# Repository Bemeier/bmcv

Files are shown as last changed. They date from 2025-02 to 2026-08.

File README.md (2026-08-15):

# BMCV

Eight scene-crossfaded LFOs in 16HP, with a PLL that locks them to an incoming
clock. This repository is the firmware, and three other things that run the
*same* firmware: a headless simulator, a browser frontend, and a VCV Rack
module.

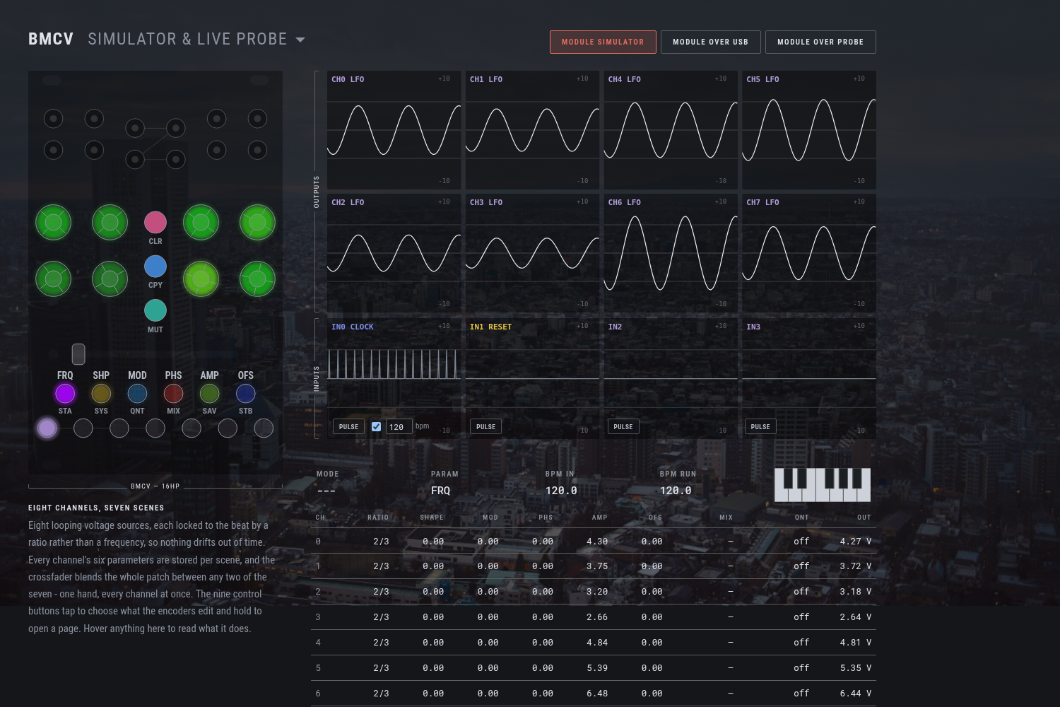
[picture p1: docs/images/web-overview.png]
The browser simulator (https://bemeier.github.io/bmcv/)


**[bemeier.github.io/bmcv](https://bemeier.github.io/bmcv/)** is that frontend,
built and deployed from `main`. It runs the module with no install, shows a
physical one over USB if you have the hardware, and carries the
[manual](https://bemeier.github.io/bmcv/manual/), a
[firmware updater](https://bemeier.github.io/bmcv/update/) and a
[diagnostics page](https://bemeier.github.io/bmcv/diagnostics/).

How to *play* the module is the manual's job, not this file's. What follows is
how the project is put together.

## One core, four hosts

Everything that behaves like a BMCV runs `Core/Src/Lib` unmodified - the same
`engine_tick`, the same UX layer, the same LED renderer. Nothing below
reimplements any of it, and none of them may: a host supplies time, input and
somewhere to put the output, and that is the whole contract.

| | what it is | lives in |
|---|---|---|
| **Firmware** | The module. STM32G474, one `bmcv_main()` off a 250µs tick. | `Core/Src/` |
| **Simulator** | The same core behind a flat C API, plus a scripting CLI for golden-file runs. | `sim/` |
| **Web frontend** | That API compiled to wasm, with an SVG panel and scopes over it. | `web/` |
| **VCV Rack** | A Rack module wrapping the same core. | `vcv/` |

The consequence worth knowing: the browser page is not a *model* of the module,
it is the module's own code with a different set of peripherals bolted on. That
is what lets the same page decode a real module's memory - see
[docs/live-module.md](docs/live-module.md) - with no parser and no second copy
of any unit conversion.

[docs/architecture.md](docs/architecture.md) is the long version.

## Repository layout

    Core/Src/Lib/     the core: engine, UX layer, LED renderer. No hardware.
    Core/Src/         the firmware's own half: ADCs, DAC, FRAM, USB, main loop.
    USB_Device/       the USB stack's app layer - descriptors, WebUSB, DFU entry.
    Middlewares/      ST's USB device library, with the MIDI class extended.

    sim/              the flat C API, its runtime shims and the scripting CLI.
    web/              the browser frontend: simulator, manual, updater, diagnostics.
    vcv/              the VCV Rack plugin.

    tests/            host-compiled tests over Core/Src/Lib and the USB descriptors.
    tools/            code generators - the panel spec, the layout asserts.
    panel/            the generated panel spec, shared by every host.
    pcb/              the KiCad project; production/ holds its fab outputs.
    docs/             architecture, the PLL, the wavetable, the live link, setup.

`Core/Src/Lib` never includes a HAL header. That is what makes the same files
compile for ARM, for the host tests, for wasm and for Rack - and it holds
because three of those four toolchains have no STM32 headers at all.

## Hardware

BMCV is a real Eurorack module - a Macro CV Controller inspired by the
[Emblematic Systems Catalyst](http://www.emblematic-systems.net/). The PCB is
made with [KiCad 8.0](https://www.kicad.org/); the project lives in
[`pcb/`](pcb/) and its fabrication outputs (BOM, gerbers, pick-and-place) in
[`production/`](production/).

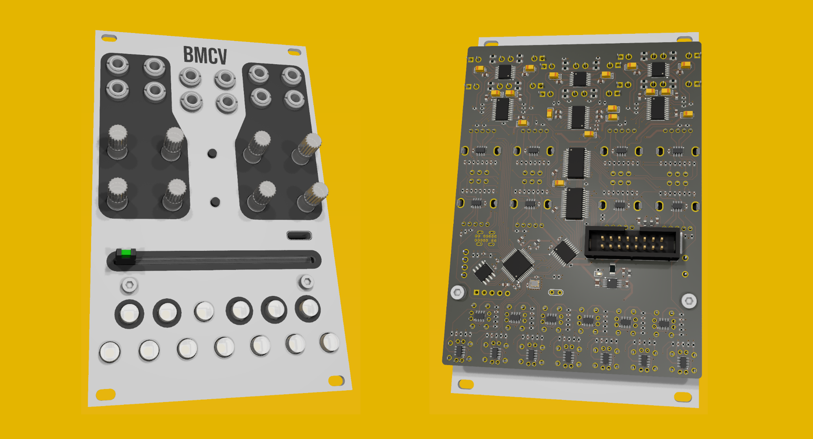
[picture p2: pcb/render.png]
Render


Eight output jacks and four input jacks, eight endless encoders that are also
buttons, nine control buttons, seven scene buttons, a crossfader, and 21
WS2812s. One USB-C port, which is a MIDI port and a vendor interface at once -
[docs/midi.md](docs/midi.md), [docs/live-module.md](docs/live-module.md).

The panel geometry is not typed in anywhere. `tools/gen_panel_spec.py` reads the
KiCad placement data and the firmware's own index tables and writes `panel/`,
which every host then draws from - so the picture on the web page cannot drift
from the board.

## The concepts the design turns on

Three, and most of the codebase follows from them.

**A channel is an oscillator locked to a ratio, not a rate.** Frequencies are
divisions of the incoming beat, so a patch stays in phase with everything around
it. That is why there is a PLL rather than a tempo readout, and why
`clock_sync.c` is the most carefully tested file here -
[docs/pll.md](docs/pll.md).

**A scene is every parameter of every channel at once, and the crossfader blends
two of them.** Forty-eight values move on one fader. That is why parameters live
in a scene-indexed array rather than on the channel, and why `EngineConfig` is
the thing that gets saved, copied and cleared.

**The whole module is one struct.** `BmcvInstance` holds the config, the signal
path, the interaction state and the input layer; the firmware keeps exactly one.
Nothing that matters lives in a file-static. That is what lets a host run
several, a test build one per case, and a debug probe or a USB link ship the
entire module to a browser as bytes.

## LED language

The colours are not decoration. One fact per LED, and the same colour for the
same idea on every page - the point being that the panel teaches itself, so the
manual never has to explain a colour.

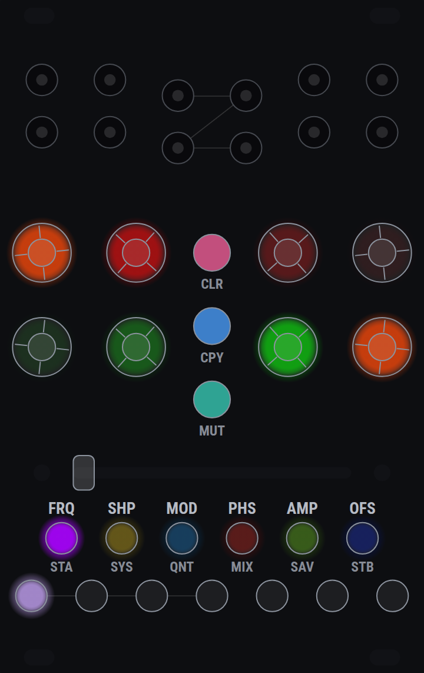
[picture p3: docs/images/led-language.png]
The panel's LEDs


- **Ctrl-page settings clamp, they do not wrap.** Each is a short list of
  unrelated states with its default at index 0, so spinning an encoder fully
  left resets it and you can do that without looking. Rolling off one end into
  the other would be the largest change on the page.
- **Setting states** are the base layer. Index 0 of every setting - disabled,
  default, neutral - is **purple**; **cyan** is continuous / level-following or
  multiplicative, **green** additive or half-way, **yellow** triggered / clocked
  / stepped, **red** reset. Destructive is **pink**, and belongs to clearing
  alone. See `HUE_STATE_*` in `color_presets.h`. The output clamp is the one
  place brightness also carries meaning, because it is two facts on one LED.
- **White is assignment, and nothing else uses it.** A short white flash every
  1.6s over an element's own colour means "you can pick this". Once something is
  held, the places it can go are steady white with a short dropout, the held
  source is steady saturated purple, and everything else goes **dark** - if it
  cannot be pressed it does not light.
- **Output level** only appears when no shift mode is active. In a shift mode
  the encoder ring shows that mode's setting, or nothing if it has none.
- **FRQ is a ratio, not a level**, so its ring codes three facts on three axes
  rather than drawing a bar. **Hue** is the kind of division: **green** straight
  (halves, quarters, octaves), **yellow** triplet, **orange** quintuplet -
  octaves are free, so 1/8 and 16 are the same green and 1/3, 3/2 and 24 are the
  same yellow. **Saturation** is how far off the grid the value sits, so a fine
  adjust washes the colour out to a pastel and a snapped ratio is pure.
  **Brightness** pulses shallowly at the channel's own output rate, which is
  what says fast from slow; anything too fast for the panel to resolve shimmers
  together at one rate instead of aliasing into a slow phantom pulse.
- **Confirmations** are a brief flash on top: purple wrote, pink cleared, cyan
  loaded. Purple is the selection colour, so a copy landing somewhere flashes
  the colour the source was held in. Red is errors only.
- **A held press dips out once as it crosses each of its thresholds** - off,
  then back on - which says "that registered" rather than pulsing away as if
  something were still in progress. At the first stage it comes back exactly as
  the page had it; where holding longer does something wider - clearing every
  scene rather than this one - it comes back brighter, in the same colour.
  Nothing commits until the release.

## Building

Prerequisites, what each fetch recipe actually gets and why, and
troubleshooting: [docs/setup.md](docs/setup.md). On a fresh checkout, the one
thing to run first is `just arm-sdk`.

    just arm-sdk          # fetch the ARM toolchain + STM32Cube HAL, once
    just build            # ARM firmware        just flash / just flash-usb
    just check            # everything host-side: format, tests, flows, wasm, web
    just check-all        # the above plus the firmware and Rack plugin builds
    just test-san         # the same tests under ASan/UBSan
    just fmt              # clang-format the hand-written C (fmt-check to verify)
    just web              # the browser frontend, at http://localhost:8000
    just docs-page        # the same pages with no wasm build, for the updater
    just vcv-install      # build the Rack plugin into ~/.local/share/Rack2
    just vcv-dist win-x64 # a distributable .vcvplugin for any platform

    # Rack running on Windows while you build in WSL. Needs the cross-compiler
    # once: sudo apt install gcc-mingw-w64-x86-64 g++-mingw-w64-x86-64
    just vcv-win-install  # cross-build plugin.dll into %LOCALAPPDATA%\Rack2

    just panel            # regenerate the panel spec from the hardware repo
    just layout-check     # regenerate the struct layout asserts from the ELF
    just docs-shots       # regenerate the screenshots in this file
    just dfu-check        # check the DfuSe client against a fake device

`just fmt` is pinned to clang-format 18, which is what CI installs; the recipe
refuses any other major, because the output moves between them.

Anything machine-specific - where your Rack SDK lives, which browser to drive -
goes in `local.just`, which is not checked in. `CMakeLists.txt` has the same
arrangement with `local.cmake`.

CI runs `just check`, the sanitizer pass and an ARM build on every push - one
job per target, in [`.github/workflows/ci.yml`](.github/workflows/ci.yml). The
firmware size is printed into the job summary rather than gated.

A push to `main` that clears every job bumps `VERSION` and `CHANGELOG.md` from
the commits since the last tag and cuts a GitHub Release - see
[Versioning](#versioning). The same push deploys `web/` to GitHub Pages.

## Flashing

Three routes, and they want different files.

**Over the programming header, from a build.** `just flash` sends
`build/BMCVFirmware.elf` over an ST-Link; `just flash-rel` does the same with
the release build. It needs the module out of the rack with a ribbon on its
debug header, and it is the only route that can also halt the core - so it is
what `just where` and any breakpoint work sit on.

**Over USB-C, from a build.** `just flash-usb` sends `build/BMCVFirmware.bin`
through the STM32's ROM DFU bootloader, with no probe and **the module still in
the rack**. That is the development loop when nothing needs stepping through:
the WebUSB link and the diagnostics page still work, so printf-level debugging
survives; halting does not. The module has to be put into update mode first -
hold **CPY** while it powers up, or press the update-mode button on the updater
page - and the recipe says which, then waits for the bootloader to appear. See
[docs/setup.md](docs/setup.md).

**Over USB-C, from the browser.**
[bemeier.github.io/bmcv/update](https://bemeier.github.io/bmcv/update/) flashes
a released version or a local `.bin`, with no build and no probe. `just
docs-page` serves the same page locally against your own build. That page
documents the rest - what to hold, what Windows needs once, what the panel does
- and this file does not repeat it.

It has to be the `.bin` there. The `.elf` beside it is what the ST-Link path
wants and is not a raw image: headers and symbols, so its first bytes are not
the vector table, and a debug build is four times the size of the flash. The
updater checks for this and refuses, naming the mistake, before erasing
anything.

Both files are on every [release](https://github.com/Bemeier/bmcv/releases). The
`.elf` is the same build with its symbols still attached, which is what a
debugger or a live variable viewer needs to attach to a module running that
release - a `.bin` carries no symbol table, so no tool can find a variable in
one. Take the `.elf` from the release the module is actually running, since
every address in it belongs to that build.

## Installing the Rack module without building it

Every [release](https://github.com/Bemeier/bmcv/releases) carries a
`BMCV-<version>-<platform>.vcvplugin` for `lin-x64`, `win-x64`, `mac-x64` and
`mac-arm64`. Drop the one for your platform into Rack's plugin folder and
restart Rack, which unpacks it on the way up. The folder ends in your
platform's name - since Rack 2.4 there is one per platform, and a plain
`plugins` directory is not read:

| | |
|---|---|
| Windows | `%LOCALAPPDATA%\Rack2\plugins-win-x64` |
| macOS (Apple silicon) | `~/Library/Application Support/Rack2/plugins-mac-arm64` |
| macOS (Intel) | `~/Library/Application Support/Rack2/plugins-mac-x64` |
| Linux | `~/.local/share/Rack2/plugins-lin-x64` |

It is not in the VCV Library, so nothing has signed it but this repository's
CI. On macOS that means Gatekeeper quarantines it on download and Rack then
refuses to load it - clear the flag on the file itself, before starting Rack:

    xattr -dr com.apple.quarantine ~/Library/Application\ Support/Rack2/plugins-mac-arm64/BMCV-*.vcvplugin

Windows may want a "more info" click past SmartScreen the first time.

## Versioning

Commit messages are [Conventional Commits](https://www.conventionalcommits.org)
- `feat: ...`, `fix: ...`, `feat!: ...` for a breaking change, and so on -
enforced on pull requests by the `commits` CI job. `VERSION` and
`CHANGELOG.md` are generated from them by [commitizen](https://commitizen-tools.github.io/commitizen/),
never edited by hand; `Core/Inc/Lib/version.h` is in turn generated from
`VERSION` at configure time, which is why it isn't checked in.

    just commit          interactive wizard for a correctly formatted message
    just bump-dry-run    preview the next version and changelog, unattended
    just bump            bump, commit and tag locally - or just push to main
                         and let the `release` CI job do it

Needs `pipx install commitizen` (or `pip install --user commitizen`) once.

The Rack plugin is the one thing that does not follow this version, because it
cannot: Rack refuses to load a plugin whose version does not begin with Rack's
own major, so driving `vcv/plugin.json` from `VERSION` would pin this project's
major to Rack's and cost the firmware its semver. It is fixed at `2.0.0` and
stays there - it means "for Rack 2", not "the second version of anything". The
firmware version travels on the released file's name instead,
`BMCV-v0.6.1-lin-x64.vcvplugin`, which is why the plugin shows as 2.0.0 in
Rack's browser however new the firmware inside it is.

## License

This work is licensed under a [Creative Commons Attribution-ShareAlike 4.0 International License][cc].

[][cc]

[cc]: https://creativecommons.org/licenses/by-sa/4.0
[shield]: https://licensebuttons.net/l/by-sa/4.0/88x31.png
[render]: https://raw.githubusercontent.com/Bemeier/bmcv/refs/heads/main/pcb/render.png

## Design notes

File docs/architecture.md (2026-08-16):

# How this repository is arranged

Four things are built from it: the firmware, a headless simulator, a browser
frontend and a VCV Rack module. All four run the same C, and the arrangement
below exists to keep that true rather than approximately true. For how to
build each - what to install and in what order - see
[setup.md](setup.md).

```
Core/Inc/Lib  Core/Src/Lib   the module. No host, no peripherals.
Core/Src/*, USB_Device/      the STM32: HAL glue, DMA, SPI, the USB stack.
sim/                         host-side glue, plus a headless CLI.
web/                         the browser frontend (wasm + plain ES modules).
vcv/                         the VCV Rack plugin.
tests/                       native unit tests for everything above.
tools/                       generators. Their output is checked in.
panel/                       generated panel geometry.
```

The HAL itself is not in the tree. `cmake/stm32cubemx/CMakeLists.txt` compiles it
out of an STM32Cube FW package located by `STM32CUBE_FW_PATH`, which is what
`toolchain.cmake` sets - written by `just arm-sdk` (see setup.md), or by hand
from `toolchain.default.cmake` if you already have STM32CubeCLT. CI fetches
the same version from ST's public mirror the same way `arm-sdk` does; the two
submodules it needs are named in `../.github/workflows/ci.yml`, at the repo
root.

## The three ideas most of this follows from

**A channel is an oscillator locked to a ratio, not a rate.** Frequencies are
divisions of the incoming beat, so a patch stays in phase with everything around
it. That is why there is a PLL rather than a tempo readout, and why
`clock_sync.c` is the most carefully tested file here - [pll.md](pll.md).

**A scene is every parameter of every channel at once, and the crossfader blends
two of them.** Forty-eight values move on one fader. That is why parameters live
in a scene-indexed array rather than on the channel, and why `EngineConfig` is
the thing that gets saved, copied and cleared. Moving a parameter onto the
channel where it looks like it belongs is the recurring wrong turn.

**The whole module is one struct.** `BmcvInstance` holds the config, the signal
path, the interaction state and the input layer; the firmware keeps exactly one.
Nothing that matters lives in a file-static. That is what lets a host run
several, a test build one per case, and a debug probe or a USB link ship the
entire module to a browser as bytes - which the next section is about.

## The seam

`Core/Src/Lib` is the module and nothing else. It has no peripheral access, no
globals, and no idea what is running it. The contract is one struct and two
calls:

```c
BmcvInstance m;                                  // instance.h
bmcv_instance_init(&m, &preset_io, now_us);
bmcv_instance_tick(&m, &input_sample, now_us);   // input_fold.h
```

A host fills an `InputSample` - button levels, encoder positions, slider, CV -
and reads `EngineState` back: `channels_gated_level[]` for its outputs,
`leds[]` for its lights. That is the whole interface. Everything a host has to
decide for itself, it decides outside this line.

Which files are in the core is not a matter of opinion:
`cmake/core_sources.cmake` lists them, and all four builds read that one list.
A source that is not on it does not compile into the firmware either.

**The rule that keeps this honest:** a behaviour that exists in a host and not
in `Core/Src/Lib` is a behaviour the hardware does not have. When a host needs
something the core does not expose, the answer is to widen the core's
interface, not to reimplement the behaviour on top of it.

## Why there is a `sim/` at all

Three hosts need the same handful of fiddly things, and each is easy to get
subtly wrong:

## What reaches the pins, and how often

The engine computes one value per channel per tick. What the DAC gets is
interpolated between the last two of those, so a step becomes a ramp rather
than an edge - `dac_write_interpolated()` in `bmcv.c`.

**The DAC has a clock of its own.** TIM6 fires every `DAC_CHUNK_US` and calls
`bmcv_dac_tick()`, which arms one transaction. Nothing in the main loop touches
it, so the output rate is a number this firmware chooses rather than a side
effect of how long the last engine tick took.

It was the latter, and it collapsed exactly when the most was being asked of it:
served from the loop, a completed transfer sat in a flag until the loop noticed,
and the loop was inside an engine tick. `dac_fps` and `engine_fps` read the same
number under load - one transaction per tick, so one frame per output every four
ticks, against a shape being computed every tick.

Two things had to be true before a fixed cadence was affordable:

1. **HAL is not on the path.** `HAL_SPI_TransmitReceive_DMA` plus
   `SPI_DMATransmitReceiveCplt` measured ~17.4us per six-byte transaction
   against **2.67us of actual wire time** - most of a transaction spent walking
   a state machine. `dac_adc.c` arms the DMA and services its completion by
   writing registers: ~9us, and four substeps went from impossible (the engine
   never ticked at all) to merely expensive.
2. **The interrupt runs at the SPI DMA completion's priority.** Equal priority
   means neither can preempt the other, so the service cannot be re-entered
   against the completion that feeds it and the two need no lock between them.

`DAC_SUBSTEPS` is how many full frames a tick is divided into - 2, so a chunk is
62.5us and every output is refreshed twice per tick. That is what the
interpolation was written for: below 1 it has nothing to interpolate between.

The measurements to reach for are `just profile`, which reads `bmcv_profile` off
a running module - `load` near 1 means the tick does not fit its period, and the
`dac` row is what one service costs - and `just dac-loopback`, which patches an
output into an input and is the only reading that tells "the bus is busy" apart
from "the outputs are moving".

- **Unit conversion.** Volts to ADC counts and DAC counts to volts, with the
  converters' real ranges and the 14-bit converter's off-by-one.
- **Tick decimation.** The engine is dt-driven and correct at any rate, but a
  host samples audio far faster than the engine needs. `SimTickDiv` accumulates
  time in Q32 microseconds so that a 44.1kHz divider of 11 does not run the
  clock 0.17% slow.
- **Gate latching.** Hardware catches edges in the ADC's DMA callback, faster
  than the engine loop. A host that samples per frame and ticks at the
  engine's rate has to latch the same way or it drops short triggers.
- **Filling an `InputSample`.** A host counts jacks the way the panel does;
  `InputSample` counts converter channels.
- **The preset slots**, which on the module are FRAM and on a host are bytes to
  put in a patch file or in browser storage.

`sim/src/sim_rt.c`, `slot_store.c` and `led_color.h` are those, in plain C with
no host's types in them, so all three hosts share one implementation and
`tests/test_sim_rt.c` and `test_slot_store.c` can exercise it with no host at
all. `sim/src/bmcv_sim.c` is a fourth host - the flat C API the wasm build and
the CLI use.

The directory is named for the simulator that came first, but its contents are
host support generally.

## The four builds

| Target | Entry point | Why it is separate |
|---|---|---|
| firmware | `CMakeLists.txt` | ARM toolchain, `cmake/gcc-arm-none-eabi.cmake` |
| tests + tools | `tests/CMakeLists.txt` | host compiler, `ctest` |
| sim + wasm | `sim/CMakeLists.txt` | same sources under `emcmake` for the web |
| Rack plugin | `vcv/Makefile` | Rack supplies `plugin.mk`; a plugin must include it |

The Rack plugin is also the only one built for more than one platform, four of
them, so which SDK and which compiler go with which is `scripts/vcv-build.sh`
rather than anything in `vcv/Makefile` - one path shared by `just vcv-dist` and
by the CI matrix in `.github/workflows/vcv.yml`, so a released `.vcvplugin` is
reproducible locally.

They are four projects rather than one because their toolchains genuinely
differ, not because the code does. Each includes `cmake/core_sources.cmake` (or
parses it, in the Rack plugin's case) so the source list cannot drift.

`just check` runs everything that needs neither hardware nor a browser: the
unit tests, the golden flows, a headless load of the wasm, and a headless
import of the whole web frontend.

## Generated, not written

Anything derived is generated and checked in, so that a reader gets it without
opening KiCad and a reviewer sees it change as a diff:

- `panel/` and `web/panel.json` and `vcv/res/` come from `tools/gen_panel_spec.py`,
  which merges the PCB project's KiCad output (`pcb/`, `production/`) with the
  firmware's own `HwSetup` tables. Positions, LED assignments and button roles are
  therefore derived from the board and the firmware together, and
  `tests/test_panel_spec.c` asserts the two agree. `just panel`.
- `Core/Inc/Lib/stepped_table.h` comes from `tools/gen_stepped_table.c`.
  `just stepped-table`.
- `Core/Inc/Lib/wavetables.h`, `Core/Src/Lib/wavetables.c` and the plots in
  `docs/images/wavetable-*.svg` all come from one run of
  `tools/gen_wavetable.py`, so the documentation cannot show a shape the
  firmware does not have. `just wavetable`, and `just wavetable --report` for
  the axis as sparklines. Generated rather than drawn because the properties
  that matter - full swing and no DC at *every* setting, the canonical shapes
  exact, the axis closing on itself - are true of the whole family by
  construction and were not true of a table edited slice by slice.
  `docs/wavetable.md` is the long version.
- `docs/images/` comes from `tools/`-driven screenshots of the real frontend.
  `just docs-shots`.

What genuinely cannot be derived lives in `panel/overrides.json` and is listed
under `assumptions` in the generated spec, so an assumption cannot hide.

## Testing

Conventions for writing one are in [`tests/CLAUDE.md`](../tests/CLAUDE.md);
this is what exists and why. `tests/` holds ordinary unit tests plus three
things worth naming:

- **`tests/fixtures/fixture.c`** drives a whole `BmcvInstance` from button and
  encoder events, so a test can express a gesture ("hold STA, tap scene 3")
  rather than a state.
- **`sim/flows/`** are scripted input timelines replayed through the CLI and
  diffed against committed CSV output. They cover interactions across time that
  a unit test cannot state - a clock locking, a mute ramping, a mode latching.
  Review the diff, then `just flows-bless`.
- **`tests/pll_metrics.{c,h}`** turns a run of the sync loop into numbers -
  settling, ringing, frequency pull, phase continuity, long-run alignment - so
  that a change to it reads as a trade rather than as a feeling.
  `tests/test_pll.c` prints the table; `docs/pll.md` keeps the baseline.

Several tests exist purely to stop the four builds drifting apart, and are
load-bearing rather than incidental: `test_panel_spec.c` (the generated
geometry against `hw_setup.c`), `test_sim_import.c` (a snapshot round-trips
through the wasm decoder), `test_config_migrate.c` (every old FRAM record still
loads), the LED curve check in `web/smoke.mjs` (the C header against the JS
constants), and `sim/include/layout_target.h`, which is not a test at all but a
wall of static assertions the wasm build compiles.

`tools/stepped_explore/` is the fourth kind: an offline measurement harness rather
than a check. It is what a change to `stepped_shape()` has to be judged with,
because the obvious identity metrics say the old sweep contained 400 distinct
patterns and are no help at all. See [`tools/CLAUDE.md`](../tools/CLAUDE.md).

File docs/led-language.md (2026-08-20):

# LED language

The colours are not decoration. One fact per LED, and the same colour for the
same idea on every page - the point being that the panel teaches itself, so the
manual never has to explain a colour.

The panel's LEDs

- **Red and green are a voltage, and nothing else on an encoder is.** The ring
  showing a level, the AMP and OFS parameters, and the live CV on an input jack
  wear the ramp in `led_set_bipolar` — red negative, green positive, warming at
  the extremes. That ramp never lights the blue die, and every other colour on
  the panel does, which is what keeps a setting from reading as a level. The
  error blink borrows red and blanks the panel to say so; the six lit caps keep
  their own colours, because a cap is a label and never shows a value.
- **Ctrl-page settings clamp, they do not wrap.** Each is a short list of
  unrelated states with its default at index 0, so spinning an encoder fully
  left resets it and you can do that without looking. Rolling off one end into
  the other would be the largest change on the page.
- **Setting states** are the base layer, and they live on the cool half of the
  wheel, 30 apart. Index 0 of every setting - disabled, default, neutral - is
  **purple**; **cyan** is continuous / level-following or multiplicative,
  **teal** additive or half-way, **blue** triggered / clocked / stepped.
  Destructive is **pink**, and belongs to clearing alone. **Yellow** is reset,
  and is the one state that keeps a warm hue: it appears only on the SYS scene
  row, which is the one page with no voltage on it anywhere. See `HUE_STATE_*`
  in `color_presets.h`. The output clamp is the one place brightness also
  carries meaning, because it is two facts on one LED.
- **White is assignment, and nothing else uses it.** A short white flash every
  1.6s over an element's own colour means "you can pick this". Once something is
  held, the places it can go are steady white with a short dropout, the held
  source is steady saturated purple, and everything else goes **dark** - if it
  cannot be pressed it does not light.
- **Output level** only appears when no shift mode is active. In a shift mode
  the encoder ring shows that mode's setting, or nothing if it has none.
- **A parameter is drawn as what it is.** With no page open, touching an encoder
  reveals the selected parameter across all eight rings for two seconds. **AMP**
  and **OFS** are volts, so they wear the voltage ramp on the DAC's own scale.
  **SHP**, **MOD** and **PHS** are numbers: the same ramp - dark at zero,
  brightening toward either end - in **teal** positive and **pink** negative,
  where saturation is the third fact and says whether the value is on something
  with a name. Pure on a named shape or on a half or whole turn of phase,
  washing to a pastel between two of them. Which shapes have names depends on
  the shape mode, so PWM's width and the stepped morph have none.
- **FRQ is a ratio, not a level**, so its ring codes three facts on three axes
  rather than drawing a bar. **Hue** is the kind of division: **teal** straight
  (halves, quarters, octaves), **blue** triplet, **pink** quintuplet - octaves
  are free, so 1/8 and 16 are the same teal and 1/3, 3/2 and 24 are the same
  blue. The scale used to be green to orange, which is the voltage ramp end to
  end; it walks the cool half now, so a ratio cannot be read as a level.
  **Saturation** is how far off the grid the value sits, so a fine adjust washes
  the colour out to a pastel and a snapped ratio is pure.
  **Brightness** pulses shallowly at the channel's own output rate, which is
  what says fast from slow, shifting the hue slightly *inward* toward the middle
  of the scale at the peak so a pulse can never brighten a class toward the
  voltage arc; anything too fast for the panel to resolve shimmers
  together at one rate instead of aliasing into a slow phantom pulse.
- **Confirmations** are a brief flash on top: purple wrote, pink cleared, cyan
  loaded. Purple is the selection colour, so a copy landing somewhere flashes
  the colour the source was held in.
- **A held press dips out once as it crosses each of its thresholds** - off,
  then back on - which says "that registered" rather than pulsing away as if
  something were still in progress. At the first stage it comes back exactly as
  the page had it; where holding longer does something wider - clearing every
  scene rather than this one - it comes back brighter, in the same colour.
  Nothing commits until the release.

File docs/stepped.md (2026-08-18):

# The stepped shape

A pattern of values, one per step of the cycle, eased between and locked to the
beat. `Core/Src/Lib/stepped.c` is the runtime; `stepped_pattern.h` is what each
step shows, shared with the table generator; `stepped_norm.h` is the correction
that holds the level steady.

**It is not random.** Every value is a deterministic function of the two knobs,
the pattern length and the phase - the caller re-derives phase from the PLL on
every tick and gets the same value back, which is what lets scenes crossfade
without the pattern drifting. What the knobs move through is a space of
patterns. That is also the constraint that shapes everything below: a phase-
driven module cannot draw fresh numbers, so what it has instead of stochastic
draws is the rule that **neighbouring knob positions stay related**.

For what the knobs do musically, see [shapes.md](shapes.md).

## How a value is built

1. **Slots.** Each step has a slot, and each slot rides its own slow orbit at
   its own whole-numbered rate. SHP advances all of them at once, which is why
   the knob wraps.
2. **Character levers**, all functions of the orbit: how the values are spread
   (`ST_BEND`), how melodic the contour is (`ST_CONTOUR`), whether the cycle
   repeats a quarter-length phrase (`ST_MOTIF`), which steps tie (`ST_SPIN`),
   where the beat sits (`ST_SWING`). Each has a depth and a *rate* - how many
   excursions it makes across its knob - so a given contour depth comes back
   paired with a different shaper each time.
3. **Ties.** A step either takes its own value or crossfades toward the previous
   one. MOD moves the density and rotates which steps tie, so the tied set keeps
   re-arranging instead of only growing.
4. **The correction**, `out = value * gain + offset`, which holds the level
   steady. See below.
5. **Two reshapings** of the finished value, both driven by SHP: the bias, which
   leans the distribution, and the terracing, which gathers values onto a few
   levels. Both monotone.

## The correction, and where it lives

Short patterns collapse. With a handful of steps the orbits can all cross at
once and the pattern flattens for a stretch of the knob - measured at length 2,
18% of the sweep, in runs 15% wide. The correction is an affine per setting that
lifts those without flattening the natural variation elsewhere.

It has two halves, and they have opposite shapes, which is what decides where
each one lives:

| | shape | so it is |
|---|---|---|
| the centring constant | length-*in*dependent, expensive: an average across every pattern length of what would centre each | baked, 8 KB, `st_centre_table` |
| the gain | length-dependent, cheap: one pattern's own extremes | measured at runtime |

A channel knows only its own length, so it cannot work the constant out; it
scans its own pattern for the gain, one slot per engine tick. That split is what
replaced a 180 KB table of gains and offsets - and it made two things exact that
the table could only approximate:

- **The cycle boundary.** Every length lands on the shared constant at phase 0,
  so pattern length can be switched on the wrap without a step in the signal.
  Interpolating a table put 0.044 of a jump there; computing the anchor at the
  real point puts none.
- **The floor.** `ST_NORM_FLOOR` is now applied at the point being played rather
  than arriving through a neighbourhood rule written for interpolation. Worst
  span anywhere went 0.584 to 0.900 of the 2.0 range.

### What a step costs, and why it is paid once

What a step shows, and what the next one shows, depend on which step the
playhead is in and **not on where inside it** - only the ease between them
varies within a step. The shape is sampled far faster than the steps move: at
0.5 Hz over 64 steps, tens of consecutive ticks were computing the same two
numbers from scratch.

So a channel keeps an `StStepCache` and pays per *step* rather than per tick.
Two things fall out of it:

- **Within a step there is nothing to compute but the ease.**
- **Crossing into the next step costs one slot evaluation, not a walk.**
  `st_step_next()` returns exactly `st_step_value(next)`, so what the last step
  eased *toward* is by definition what this one eases *from* - the pair advances
  by computing only its new far end. That is the part that helps a fast LFO,
  where the cache itself never hits.

Only a jump pays the full route: a phase correction, a knob turn, or a rate high
enough to skip a step outright. **The skipping case is not improved at all**, and
was already bounded - `st_step_value()` is O(`ST_JUMP_GRID`) regardless of
pattern length.

### And the slots underneath it

The step cache removed everything *above* the slot evaluations, which left those
as the whole cost - and they are memoisable for the same reason: what a slot
offers depends on the slot and the morph, and the morph on nothing but the two
knobs and the length. `StSlotMemo` remembers `st_slot_offer()` per slot while
the knobs are still.

It is threaded as a parameter, and `NULL` means "compute it". That is what keeps
it a memo rather than a second implementation: one value path, and a caller that
supplies no memo takes the identical route through it. The scan shares the
channel's memo, since it walks the same slots of the same pattern.

### What the two are worth

Measured on the module, seven stepped channels at MOD full (densest ties, motif
fold active), over 64 steps. `engine` avg, and `load` against the 250 µs period -
**taken while the tick was still 250 µs**, so the loads are not today's. The
engine cost per tick is what is being compared and that does not move with the
period; see `hw_setup.h` for what the tick is now and why.

| rate | steps/tick | neither | step cache | + slot memo |
|---|---|---|---|---|
| 0.5 Hz | 1/91 | 296.5 µs (1.30) | 197.3 µs (0.90) | **184.2 µs (0.84)** |
| 62.5 Hz | ~1 | 282.8 µs (1.27) | 227.5 µs (1.02) | **192.0 µs (0.88)** |
| 129.5 Hz | ~2, skipping | 277.9 µs (1.24) | 275.4 µs (1.23) | **209.0 µs (0.95)** |

**Every column of the last row is the point.** The step cache does nothing for a
playhead that skips - the carry never applies and the cache never hits, so it
was flat at 275 µs - while the slot memo takes 24% off it, because a skipping
playhead still asks for slots it asked for a few ticks ago. Together they held
`engine_fps` at its nominal 4000 under every condition above, with overruns at
3% and resyncs in single figures. Before them the same patch ran at 2915 with
every tick overrunning.

Backing out the ~135 µs the engine costs before any stepped channel exists, the
per-channel stepped cost at the skipping rate goes 20.0 → 20.0 → **10.5 µs**.

The cache changes when the work happens, never what comes out.
`tests/test_stepped_cache.c` asserts the cached and uncached routes are
bit-identical, and that is not decoration: the cache key has to name every input
`st_morph()` and `st_step_pair()` read, and a lever added to `StMorph` driven by
something outside the key would leave a channel drawing its old pattern - no
crash, no drift in level, just the wrong shape, sounding plausible.

Writing that test found a real one. `st_tie_run()` *breaks* when a tie weight
reaches 1, so `st_step_value()` returns the slot's offer outright - while
`st_step_next()` computed `lerp(from, offer, 1.0f)`, and `from + (offer - from)`
is not `offer` in floating point. At length 3, where `st_tie_fade` lets a weight
reach exactly 1, the two disagreed in the sixth digit. The discrepancy predates
the cache; nothing had ever compared the two routes.

### The scan

`st_norm_scan()` measures one slot per tick and slews the result into place over
20 ms. Three things about it are load-bearing:

- **The engine hands out one measurement per tick**, in turn, across all
  channels. A slot evaluation is nearly as expensive as the shape itself - a
  step value walks a run of ties, each slot a four-tap contour and a motif fold.
  Eight channels each measuring every tick cost 88 µs of a 310 µs tick, and the
  engine answered by dropping every third one. **Measured on the `-O0` debug
  build** (`just flash-usb` flashes that one; `just flash-usb-rel` is the
  optimised firmware), so the absolute figures are 5x pessimistic - the host
  gap between -O0 and -O2 for this shape is 437 ns against 83. The rota bounds
  the cost either way and costs a standing channel nothing, but whether it is
  *needed* at -O2 has not been measured.
- **A standing channel stops measuring.** Re-measuring an unchanged pattern can
  only give the answer it already has, so what the scan costs is a knob moving.
- **A length change restarts the pass** rather than paying for a full
  measurement in one tick, which would be three ticks' worth of budget and
  happens once per encoder detent.

The slew, not a latch to the cycle wrap: a slow LFO would otherwise play a whole
cycle uncorrected after a knob move, and the table it replaced never waited for
a wrap either.

## What a small turn may do

The rule is that a small turn **deforms** the pattern rather than replacing it.
That is measured as **Spearman's rank correlation** between the patterns at *x*
and *x* + 1% of travel: the steps keep their order.

The measure matters as much as the bound. It used to be "no sample moves more
than 0.35", which is the same thing while character comes from redrawing the
pattern - and a different thing for a monotone reshaping, which cannot move a
step out of order however far it moves the values. That is true by construction,
so the old rule was charging full price for the one mechanism that is musically
free, and it was the ceiling on how much a detent could do.

| steps | worst rho, SHP | worst rho, MOD |
|---|---|---|
| 3-5 | -0.50 .. 0.70 | -0.50 .. 0.60 |
| 8-16 | 0.71 .. 0.84 | 0.79 .. 0.90 |
| 24-64 | 0.93 .. 0.96 | 0.94 .. 0.98 |

Held at 0.55 from eight steps up. Short patterns are exempt: three values cannot
change gently, and at three steps one swap inverts the order outright.

A second, looser bound stays on how far a sample may move (0.60), because
keeping the order is not sufficient on its own - a reshaping steep enough to
throw a step across the range would pass the rank test and still be heard as a
jump.

## Things that were tried and are not here

Written down because each cost a day and the numbers looked good on the way in.

- **A smooth wander** (`drift`, octaves of a smoothed triangle in the phase
  domain). Measured beautifully - DC exactly zero, no correction needed, 20 ns a
  call - and sounded like a sine with harmonics, because that is what it is. A
  waveform that closes on itself over one cycle *is* a Fourier series; smooth
  means few harmonics; octave rates are harmonics 1, 2, 4 and 8. Inside one
  phase-locked cycle the only routes to something that reads as random are
  discontinuity or high harmonic order.
- **A separate melodic mode.** Two routings of the same engine, one for notes
  and one for modulation. The notes one was where this arrived from rather than
  a second thing worth keeping - MOD left is gently eased and SHP centre is an
  even distribution, which is where it lived.
- **`ST_SPAN`**, a lever that ducked the peak-to-peak across SHP. Being a pure
  gain it moved no character measurement at all; it only made the shape flatten
  as the knob turned.
- **Cutting `ST_MAX_ORBIT_RATE` to buy small-turn budget.** The worst turn goes
  0.44 at rate 4, 0.51 at 3, 0.39 at 2, 0.37 at 1 - non-monotone, and barely
  moving even where the slot values are nearly frozen. The worst case is not the
  orbit.
- **Snapping values to levels.** A staircase applied to a moving value is a
  discontinuity - 0.23 of a jump at every crossing. The terracing compresses
  each cell toward its centre instead.
- **Caching orbit values across a run.** Slower: the compare and branch to read
  the cache cost more than the triangle they save.

## Measuring a change

`tools/stepped_explore/` is the only thing that can judge one, because the
obvious metrics mislead: the original sweep contained 400 distinct patterns at
32 steps and still read as nothing happening. `from_c.py` reads the shipping C
through `dump_pattern.c` and splits character into **steer** (what the knob
commands) and **jitter** (what merely fluctuates), alongside the level figures.

Read `char-st` rather than `steer` when only the correction changed: three of
its features are level, and flattening those on purpose lowers `steer` while
moving no character. Two features - `skew` and `clump` - exist because the rest
are ordering-based and were blind to the reshapings entirely.

## Known, and open

- **Terracing moved the level, and the correction now spans it.** It shrinks a
  pattern's peak-to-peak by an amount depending on where its extremes fall
  against the cell boundaries - variance rather than bias, so the mean span
  moves only 4% and no global compensation reaches it. `st_bias_map` driven
  positive does the opposite and *widens* a span.

  So the correction is two affines with the reshapings between them. The
  pre-stage centres the pattern and scales it toward `ST_NORM_TARGET`, as it
  always did. The post-stage - `st_norm_levelled()` - measures what the
  reshapings actually left and scales it back to what the pre-stage asked for.
  Measured across the whole (SHP, MOD, length) grid, on the path a channel
  actually plays:

  | | min span | max span | ratio |
  |---|---|---|---|
  | before | 0.5640 | 1.8750 | 3.325 |
  | after | 0.5640 | **1.6217** | **2.876** |

  **Only the loud end moves, and that is the rails.** Where `st_gain_toward`'s
  clamp is already what sets the gain - the pattern is as wide as +/-1 allows -
  there is no room to lift the quiet settings, so the minimum does not budge.
  What the post-stage reaches is the settings that were coming out *too wide*.

  Two things it must not disturb, and does not. It is anchored at the reshaped
  value at phase 0, which every length shares because the centring constant is
  length-independent - so the loop still closes and pattern length still
  switches seamlessly on the wrap. And being applied *after* the maps, it scales
  the finished waveform uniformly: the plateaus stay plateaus.

  **Applying it before the maps instead does not work, and was measured.** A
  gain change ahead of the terracing moves values against its cell boundaries,
  so it changes which plateau each one lands on - the character, not the level.
  The first attempt did that, iterating on the pre-stage gain, and it also broke
  `ST_NORM_FLOOR` at two settings by removing a widening the floor had been
  carrying by luck.

  A caution for anyone measuring this: `cycle_level()` in the test suite
  evaluates through a *bare* drive - bias 0, terrace 0 - so the reshapings are
  the identity there and it cannot see any of this. An early comparison using it
  produced a confident and completely wrong conclusion. Measure through
  `st_drive(shape, mod)`, which is what a channel plays.

  It costs 3.6% of the engine at the worst case measured on the module - three
  map evaluations and a divide per completed scan pass, and one multiply-add per
  sample - taking `load` from 0.44 to 0.45.

- **Peak-to-peak normalisation flattened crest factor, and `ST_NORM_ROBUST`
  is what stopped it.** The correction measured the span from the single
  highest and single lowest slot. A pattern that sits low with one tall spike
  has the same peak-to-peak as one spread evenly across the range, so it earned
  the same gain - its spike came out no higher than the other's ordinary
  maximum and its bulk far below. A taller spike read as a wider span and
  therefore earned a *smaller* gain. Crest factor is the one thing peak-to-peak
  normalisation cannot let through.

  Reported from the module first, and it was audible before it was measured:
  at negative SHP there were few high values, and the ones there were did not
  peak enough - "now it's just largely quiet".

  The span is now measured between the *second* highest and second lowest,
  blended with the true extremes by `ST_NORM_ROBUST` (0.5). **The rail limit
  still comes from the true extremes**, which is what makes it safe: raising
  the gain lifts a spike toward +/-1 and stops it exactly there rather than
  clipping it.

  Measured across the (SHP, MOD, length) grid, through the drive a channel
  actually plays:

  | | before | after |
  |---|---|---|
  | median peak, SHP < -0.3 | +0.467 | **+0.555** |
  | settings with no peak at all (<0.40) | 36.3% | **25.1%** |
  | RMS ratio, loudest to quietest | 5.249 | **4.067** |
  | crest factor, mean | 1.331 | **1.383** |
  | neighbour rho, mean | 0.9877 | **0.9877** |
  | worst sample move, 1% turn | 0.502 | 0.515 (bound 0.60) |

  **Peak-to-peak spread goes up while RMS spread goes down.** The ear hears
  RMS, so perceived loudness got *more* consistent - the extra span is peaks
  poking out of it, which is the point. The metric that looks worse is the one
  that cannot tell a spike from a loud patch.

  **The character is untouched, and that was the thing to protect.** Spearman
  rho between a setting and the one 1% of travel away is identical to four
  decimal places, so neighbouring knob positions are exactly as related as they
  were; the worst single-sample move across that turn is slightly *larger*, not
  smaller, so there is no loss of variety between neighbours either.

  **It fades in with length**, via `st_dof_fade` - the same fade the contour
  blend uses and for the same reason. At three steps `hi2` and `lo2` are both
  the middle value, the robust span is zero, the gain runs to the rail, and a
  1% turn of SHP moved the output 1.66 of a 2.0 range against a 1.10 limit.
  With the fade it is 0.90.

  One trap worth recording: the rolling scan must seed its order statistics
  *empty* and push slot 0 like any other, exactly as `st_extent_of` does.
  Seeding them from slot 0 looks equivalent and is not - `lo2` starts equal to
  `lo` and can never be improved upward - and the rolling measurement then
  disagreed with the full one in the fourth decimal.

- **Swing on odd lengths** makes step 0 and step L-1 both wide at lengths 3 and
  5 - a lopsided shuffle.
- **Every hardware measurement here was taken on the `-O0` debug build**, which
  is what `just flash-usb` flashes. That is where "the module ticks at 3.3 kHz
  rather than the nominal 4" came from, and it is a property of that build
  rather than of the module. Re-measure with `just flash-usb-rel` before
  treating any of these numbers as the module's own.

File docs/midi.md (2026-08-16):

# MIDI

The module enumerates as a USB MIDI device and talks in both directions. This
is what it says and what it listens for.

## What it sends

Everything on **MIDI channel 1**, in one contiguous block of control changes.

| CC | Source |
|---|---|
| 16–23 | channel outputs 1–8 |
| 24–27 | CV inputs 1–4 |

The value is the signal at the jack, with the converter's full ±10V range
scaled onto 0..127 — so **0V is 64**, a full negative swing is 0 and a full
positive swing is 127.

That mapping is deliberately about the jack rather than about the patch: a
channel clamped to 0..5V uses a quarter of the CC range, because that is the
quarter of the module's output range it actually occupies. Nothing rescales
underneath you when you change the clamp — which also means that **if it is
clipped on the module it is clipped on MIDI**. The clamp is applied in the
output stage before any of this (`channel.c`, `clamp_output`), so a value
sitting at 0 or 127 is the same clipping the jack is doing, and using the clamp
as a shaping tool works the same way in both places.

The channel outputs are read *after* the mute gain, so a muted channel reads as
silent here for the same reason its jack does.

### Rate

Control changes are reconsidered 500 times a second and sent only when the
7-bit value has moved. An idle patch therefore sends nothing at all, and the
worst case is 12 messages per slot.

The rate limit is not a nicety. The engine runs at 2kHz, and a full-scale sine
at 5Hz crosses 128 quantization levels about 256 times a cycle — around 1280
CC/s on one channel and 10k/s across eight, which fits through the endpoint with
no margin and is more than a DAW wants to think about.

7 bits is visibly stepped on a slow ramp into something like a filter cutoff.
That is the cost of a mapping every DAW can learn without configuration; CC
MSB/LSB pairs would fix it at double the traffic and with patchy support.

### Clock

The module sends MIDI Clock at the standard 24 PPQN, plus Start when its clock
resets and Stop when the beat is lost.

**Only when an input jack is the clock source.** That is the same rule the
input direction uses: a patched cable wins, and MIDI is the fallback. So the
module forwards a rack clock out to a DAW, and stays quiet when the DAW is
already the master — regenerating a host's own clock back at it is redundant at
best.

## What it listens for

- **MIDI Clock (0xF8)** and **Start (0xFA)**, used as the clock and reset when
  no input jack is configured for the job. Continue (0xFB) deliberately does not
  read as Start: it resumes rather than restarts, and treating it as a reset
  would drop every oscillator's phase on a DAW punch-in.
And nothing else. Control traffic — the firmware updater's reboot-into-DFU, the
version string it shows beside the image it is about to write, snapshots and the
remote panel — used to come through here as SysEx and now goes over the module's
vendor interface. See [live-module.md](live-module.md) and
`Core/Inc/Lib/usblink.h`. What is left on this endpoint is what MIDI is for.

## Where this lives

`Core/Src/Lib/midi_out.c` decides what to send and holds it in a queue. It is
core code: no USB, no host types, and `tests/test_midi_out.c` drives it with
hand-built engine states. Each host only carries the bytes —
`Core/Src/Lib/midi.c` wraps them as USB-MIDI event packets for the endpoint,
and `web/midi.js` hands them to a Web MIDI port.

The mapping is therefore in exactly one place, and the simulator cannot drift
from the hardware.

## Using the simulator's MIDI out

The **MIDI out** box shows the twelve CCs as they are sent, with a bar per
value: what the far end is receiving, at the 7-bit resolution it receives it,
rather than a re-derivation from the engine. A bar pinned to either end is
marked, so clipping against a channel's clamp is visible as clipping.

That readout is fed by draining the module's queue, which happens whether or
not a port is selected — so it works with no MIDI port on the machine at all,
which is the common case and the quickest way to see what the mapping does.

Two things are worth knowing before it can actually send:

- **Web MIDI is Chromium and Firefox.** Safari does not ship it. The page says
  so rather than failing quietly.
- **A browser can only send to a port that already exists**, and no operating
  system provides one by default. macOS has the IAC driver (Audio MIDI Setup →
  Window → MIDI Studio), Windows needs loopMIDI or similar, Linux has ALSA's
  virmidi. Without one the port list is empty.

## Not implemented

- The VCV Rack module does not send MIDI. Patch its outputs into Rack's own
  CV-MIDI module, which does the same job natively.
- The dialled parameters (FRQ/SHP/MOD/PHS/AMP/OFS) are not published — only the
  values the channels produce. The module is a modulation source here, not a
  control surface.

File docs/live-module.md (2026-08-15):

# Watching and driving a module from the browser

The simulator page can show a physical module instead of the simulation, and
send input back to it. Two transports do the same job by different means:

| | over USB | over a debug probe |
|---|---|---|
| what it needs | the module's own USB cable | an ST-Link on the programming header |
| snapshots/s, measured | **364** | ~70 |
| firmware cost | ~80 lines, 2.4 KB RAM | **none** |
| survives a power cycle | **yes** | yes |
| works on a module that has stopped answering | no | **yes** |

**USB is the default.** It is five times faster, needs no hardware beyond the
cable already in the module, and works on one already plugged into a DAW.

**The probe is kept for one reason.** Streaming runs from the module's main
loop, which is the thing you would be debugging if the engine hung. If the core
faults or stalls, the snapshots stop and so does everything else the module
says. An ST-Link keeps reading RAM regardless, because a Cortex-M's debug unit
reaches memory over the AHB-AP without the core's cooperation. It has already
earned that place once, proving a module was healthy while its USB had gone
quiet.

## The trick, which is the same for both

**The whole module is one struct.** `BmcvInstance` holds the config, the signal
path, the interaction state and the input layer; the firmware keeps exactly one.
Everything the page draws is inside it.

**The wasm decodes it.** `bmcv_sim_import()` takes those bytes, re-points the
pointers inside them at itself, and republishes every reading. So the wasm
module - the same firmware code, compiled for the browser - is not a simulation
of the module here, it is *the decoder for a real one*. There is no struct
parser in JavaScript, no duplicated unit conversion, no second copy of the LED
curve, and there cannot be one, because nothing on the page ever looks inside
the blob.

That property is what every other decision here protects, and it is why three
transports have now been swapped underneath it without any of them touching it.

**The layouts are held equal by construction.** `sim/include/layout_target.h` is
generated from the firmware ELF's debug info and asserts the offset and size of
every leaf field of `BmcvInstance`. It is compiled into the wasm, so `just
check` fails if the two builds ever disagree. Getting there needed one fix:
`arm-none-eabi-gcc` defaults to `-fshort-enums` and clang does not, so three
enum fields are `int8_t` with the enum named in a comment.

Run `just layout-check` after `just build-rel` and review the diff.

## Over USB

The module is a composite device: MIDI on interface 0, exactly as it always was,
and a vendor-specific interface on 1 with its own pair of bulk endpoints.

**Nothing installs a driver.** `USB_Device/App/usbd_webusb.c` carries a BOS
descriptor with a WebUSB platform capability and a Microsoft OS 2.0 one; the
descriptor set behind the second names WinUSB as the driver for interface 1 and
registers a device interface GUID. Windows binds it automatically. Chrome then
claims the interface through `navigator.usb`.

Nothing on the wire is encoded or framed. A bulk transfer keeps its boundaries,
so one transfer is one message, and a snapshot is simply the instance's bytes -
the browser assembles the packets and hands over the whole thing, so neither
side reassembles anything.

- `USBLINK_OP_SNAPSHOT_REQ` asks; the module answers with the instance.
- **One request buys one snapshot.** The page asks again only once it has
  decoded and adopted the last, so the module cannot outrun what the page can
  draw. Two requests stay outstanding so the endpoint does not idle for a round
  trip; credit beyond that is dropped rather than banked, so what goes out is
  the module as it is now and not a queue of stale frames.
- Credit is also the heartbeat. A page that goes away stops asking, credit runs
  out, and the module falls silent on its own.
- The snapshot is copied between engine ticks, so it is internally consistent -
  which a probe read is not.
- Snapshots have their own endpoint, so the engine's MIDI output competes with
  nothing.

`BMCV_REQ_VERSION` is a vendor *control* request answered with the firmware
version. A question about the device rather than part of the stream, and a short
reply sharing an endpoint with 2384-byte snapshots would have to be told apart
from one by length - which is the framing this transport exists to avoid.

**Every call to the device is bounded.** WebUSB transfers have no timeout of
their own: a read for data that never comes simply never settles, with no error
and nothing to retry. During a connect that is an attempt which cannot fail, so
the retries never run and the switch that started it never finishes - which
locks every button on the page, since a switch already running refuses to start
another. `web/frontend-check.mjs` holds this, because it is a property that is
easy to lose one call at a time.

## Over a debug probe

`web/probe/stlink.js` speaks enough of the ST-Link protocol over WebUSB to
identify the probe, enter SWD mode, and read and write memory. A Cortex-M's
memory is readable without halting the core, so the module keeps playing while
it is watched.

Finding the instance is the one thing WebUSB cannot do for itself: `bmcv` moves
whenever anything before it in `.bss` changes size, and a browser has no ELF and
no `nm`. So the firmware says where it is, at an address that does not move -
`Core/Inc/Lib/bmcv_probe.h` declares a 28-byte `const` and the linker pins it to
`0x08000200`, just past the vector table. Two linker `ASSERT`s hold the address
and the size to what the header declares.

## The write direction

Both transports carry the same two mailboxes, and the module cannot tell which
one a byte arrived over.

**`RemoteInput`** is a second panel, wherever it is: button levels to OR in,
free-running encoder positions to sum, an optional crossfader override.
`input_fold` merges it, so the module answers it exactly as it answers a finger
- UX feedback, LED response, autosave, all of it.

Every field is a *level* or a *free-running position*, never a delta waiting to
be consumed. That is what makes it safe to write over a wire with no handshake:
a torn write costs one tick of a wrong value, nothing accumulates so nothing can
be applied twice or lost, and the two sides never have to agree a baseline. The
writer picks its own encoder origin and never learns the module's.

The crossfader is the only control where the two panels can genuinely disagree,
being an absolute position. Last mover wins: a new value in the mailbox takes
the fader and remembers where the physical one was sitting, and the physical one
takes it back by moving `REMOTE_SLIDER_RELEASE_RAW` away from there. The
threshold is what stops ADC noise reading as a hand on the fader.

`RemoteInput.seq` is a heartbeat as well as an update. A writer that stops -
a page refreshed with a button held - would otherwise leave its levels standing,
and a module stuck holding SHIFT has no way back but a power cycle.

**`RemoteCommand`** is the two things a panel cannot say: start again, and forget
what was saved. Destructive, and neither is a level, so it is an edge - acted on
once per change of its sequence number, however often it is rewritten. That is
what "Reset module" and "Clear FRAM" send when a module is connected.

One thing the write direction exposed, older than any of this: a rebuilt
instance zeroes the frame encoder positions are compared against, while the
physical counters keep theirs. The difference is not a turn, but the first fold
read it as one and applied it to whichever parameter was selected - which after
a reset is deliberately OFS. `InputFrames.baseline` is why the first fold after
an instance is built reports a position rather than a movement.

## The update page

`web/update/` flashes over DFU, and now reboots the module into DFU over the
same vendor interface. That matters more there than anywhere: the thing that
page does most is make the module leave the USB bus, and it used to ask over the
transport least able to survive that.

## Diagnosing it

`web/diagnostics/` has two instruments, and they earned their place. Every fault
on these links that was reasoned about was diagnosed wrongly; every one these
were pointed at gave the answer in a single run.

- **Inspect the device** reports what the browser can see: interfaces,
  endpoints, whether the vendor interface can be claimed - which is what says
  the driver bound - and what firmware is running. It separates a driver that
  did not bind from a module that is not answering.
- **Measure the snapshot rate** asks for snapshots exactly as the simulator page
  does but decodes nothing and draws nothing. Fast here and slow there means the
  cost is in decoding and drawing; slow here too means the transport or the
  firmware. It reports the spread as well as the average, because a steady
  stream and a bursty one average the same and look nothing alike.

## What the MIDI transport taught, before it was deleted

Snapshots were carried over MIDI SysEx for a while. It worked - 90 a second,
measured - and was removed anyway, because a browser enumerates MIDI *once*: a
module that left the bus, which a power cycle or a reflash does, could not be
reached again until the browser was restarted. No page can reach past that.

Two things from it are worth keeping in mind, because they are properties of
MIDI rather than of that implementation:

- **Only System Real-Time may interleave a SysEx.** Sharing an endpoint with the
  engine's control changes meant every snapshot held it for eleven milliseconds
  while musical output waited - and a control change landing inside a snapshot
  made the host abandon it, which presented as a stream that stopped for no
  visible reason.
- **A host packs what it has into a transfer.** A parser that reported only the
  first message in one silently dropped the second, which is how the module came
  to be starved of the requests it was waiting for.

The module still speaks MIDI, for what MIDI is for: control changes out, a clock
in.

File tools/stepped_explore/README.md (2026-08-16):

# Stepped: measuring what SHP and MOD actually do

An offline harness for judging changes to `stepped_shape()` before writing any
C. `stmodel.py` is a replica of the shipping algorithm, verified against it to
1.8e-6 (float32 rounding) - regenerate the reference with `dump_c.c`:

    cc -O2 -I Core/Inc/Lib -o /tmp/dump_c tools/stepped_explore/dump_c.c \
        Core/Src/Lib/stepped.c -lm && /tmp/dump_c > /tmp/c_ref.txt

## What it measures

- `metrics.py` - RMS distance between rendered cycles. "How different is this
  signal."
- `musical.py` - patterns quantised to note-sized levels, compared by Hamming
  distance. "How many different note sequences, and how many notes change per
  1% of knob travel."
- `character.py` - eleven features per pattern (span, roughness, turns,
  edginess, tie fraction, longest run, motif repetition, centroid, low-frequency
  energy, spread, swing), then the trajectory along the knob split into
  **steer** (its low-passed component: character the knob commands) and
  **jitter** (the residual: character that merely fluctuates because each
  position is a fresh random draw).
- `invariants.py` - the properties a variant may not break, mirroring
  `tests/test_stepped.c` plus the two the shipping algorithm cannot
  violate (parameter cyclicity, slot 0 length-independence).
- `dump_pattern.c` + `from_c.py` - the same character numbers plus **level**
  (how far the pattern's centre and its peak-to-peak move along a knob),
  computed on the C's own output rather than on the replica. Use these for any
  change to the *correction*: it lives in the generated table, which the replica
  does not carry.

The identity metrics come first historically and are the ones that mislead: the
shipping sweep contains 400 distinct sequences at 32 steps and still feels like
it does nothing. `steer` is what separates a knob that goes somewhere from one
that reshuffles.

`layered.py` is the round-two engine: every lever a (rate, depth) pair, on
whichever knob drives it. `final.py` is the spec the shipping C was written
from, and `verify_c.py` checks the two agree - the normalisation comes from the
generated header, so what it really tests is the value path.

## Use

    cd tools/stepped_explore
    python3 -c "import stmodel as M, character as C, variants as V; \
                C.scale(); C.report(M.Engine()); C.report(V.C5())"
    python3 -c "import invariants as I, variants as V; I.check(V.C5())"

`C.scale()` must be called before the first variant so every run is standardised
against the same baseline sigma.

For a change to the normalisation table, dump the C before and after instead -
the first file given sets the scale, so the columns are comparable:

    cc -O2 -I Core/Inc/Lib -o /tmp/dump_pat tools/stepped_explore/dump_pattern.c -lm
    /tmp/dump_pat > /tmp/after.txt      # `just stepped-table` in between
    python3 tools/stepped_explore/from_c.py /tmp/before.txt /tmp/after.txt

Read `char-st` there, not `steer`: three of the eleven features are level, so a
change that deliberately flattens level lowers `steer` while moving no
character at all.

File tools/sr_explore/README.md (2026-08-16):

# Stepped random: measuring what SHP and MOD actually do

An offline harness for judging changes to `stepped_random()` before writing any
C. `srmodel.py` is a replica of the shipping algorithm, verified against it to
1.8e-6 (float32 rounding) - regenerate the reference with `dump_c.c`:

    cc -O2 -I Core/Inc/Lib -o /tmp/dump_c tools/sr_explore/dump_c.c \
        Core/Src/Lib/stepped_random.c -lm && /tmp/dump_c > /tmp/c_ref.txt

## What it measures

- `metrics.py` - RMS distance between rendered cycles. "How different is this
  signal."
- `musical.py` - patterns quantised to note-sized levels, compared by Hamming
  distance. "How many different note sequences, and how many notes change per
  1% of knob travel."
- `character.py` - eleven features per pattern (span, roughness, turns,
  edginess, tie fraction, longest run, motif repetition, centroid, low-frequency
  energy, spread, swing), then the trajectory along the knob split into
  **steer** (its low-passed component: character the knob commands) and
  **jitter** (the residual: character that merely fluctuates because each
  position is a fresh random draw).
- `invariants.py` - the properties a variant may not break, mirroring
  `tests/test_stepped_random.c` plus the two the shipping algorithm cannot
  violate (parameter cyclicity, slot 0 length-independence).
- `dump_pattern.c` + `from_c.py` - the same character numbers plus **level**
  (how far the pattern's centre and its peak-to-peak move along a knob),
  computed on the C's own output rather than on the replica. Use these for any
  change to the *correction*: it lives in the generated table, which the replica
  does not carry.

The identity metrics come first historically and are the ones that mislead: the
shipping sweep contains 400 distinct sequences at 32 steps and still feels like
it does nothing. `steer` is what separates a knob that goes somewhere from one
that reshuffles.

`layered.py` is the round-two engine: every lever a (rate, depth) pair, on
whichever knob drives it. `final.py` is the spec the shipping C was written
from, and `verify_c.py` checks the two agree - the normalisation comes from the
generated header, so what it really tests is the value path.

## Use

    cd tools/sr_explore
    python3 -c "import srmodel as M, character as C, variants as V; \
                C.scale(); C.report(M.Engine()); C.report(V.C5())"
    python3 -c "import invariants as I, variants as V; I.check(V.C5())"

`C.scale()` must be called before the first variant so every run is standardised
against the same baseline sigma.

For a change to the normalisation table, dump the C before and after instead -
the first file given sets the scale, so the columns are comparable:

    cc -O2 -I Core/Inc/Lib -o /tmp/dump_pat tools/sr_explore/dump_pattern.c -lm
    /tmp/dump_pat > /tmp/after.txt      # `just sr-table` in between
    python3 tools/sr_explore/from_c.py /tmp/before.txt /tmp/after.txt

Read `char-st` there, not `steer`: three of the eleven features are level, so a
change that deliberately flattens level lowers `steer` while moving no
character at all.

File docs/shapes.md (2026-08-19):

# The three shapes, and what SHP and MOD do in each

Every channel is an oscillator locked to the beat by the PLL. What it draws
between one cycle and the next is its **shape mode**, and each mode gives the
same two knobs a different job. The figures are generated from the module's own
shape functions by `just shape-figures` - a picture here cannot show a shape the
firmware does not have.

Read them as a grid: **SHP down the rows, MOD across the columns.**

## Wavetable

wavetable

The classic shapes and everything between them. **SHP** slices a 64-frame table
that runs square - sine - triangle - pointy and back to square, so the knob
wraps. **MOD** leans where the cycle spends its time: negative pulls the
waveform early, positive pushes it late, and the ends of the knob stop short of
where the warp would collapse.

Every setting reaches full swing with no DC offset - between slices as well as
on them, which is a guarantee the table is generated to hold rather than
something it happens to do. See [wavetable.md](wavetable.md).

## Stepped

stepped

A pattern of values, one per step, locked to the beat and eased between. Not
random: every value is a deterministic function of the two knobs, the pattern
length and the phase, re-derived from the PLL on every tick. What the knobs move
you through is a *space of patterns*, which is why neighbouring settings sound
related rather than being fresh draws.

**SHP** is the distribution the values are drawn into, and which pattern they
come from:

| | |
|---|---|
| hard left | mostly low, with the peaks still reaching - modulation that sits down and occasionally spikes |
| centre | even |
| hard right | bunched against both rails - gate-like, mostly high or mostly low |

Underneath that the pattern itself advances, so the knob reaches different
patterns as well as different distributions. It is periodic: past the end is
where it started.

**MOD** is motion. At one end every step takes a new value and the curve is
fully slewed between them; at the other most steps tie to the one before and the
curve sits still on each. Density, which steps tie, how far the beat swings,
whether the cycle repeats a quarter-length phrase, and the ease all move
together along it. Unlike SHP it does not wrap - its ends are opposite ends.

**Pattern length** is a per-channel setting rather than a scene parameter,
because there is nothing between 8 steps and 12 for a crossfade to land on. See
[stepped.md](stepped.md) for how the shape is built and what holds it together.

## PWM

PWM

A gate with an envelope on it. **SHP** is the pulse width, off both end stops so
the pulse never disappears entirely. **MOD** is how much of that pulse is ramp
rather than plateau, and its sign is how the ramp is split between the two ends:

| | |
|---|---|
| 0 | a hard gate, so a PWM channel is still a clock divider |
| part way | attack, plateau, decay - an AD envelope, biased by the sign |
| hard left | one decay filling the pulse: percussive, instant attack |
| hard right | one attack filling the pulse: a ramp up, then a hard drop |

Both ramps live inside the pulse, so **SHP is the envelope's length** as much as
the gate's width, and nothing bleeds past it. A short trigger with a long tail
is a wide SHP at MOD hard left rather than a narrow one.

MOD used to give each edge its own segment - the rise inside the on-time, the
fall inside the off-time. That kept the width honest, but it put the two ramps on
opposite sides of the pulse edge so they could never coexist, and no setting on
the knob was an AD envelope. It also ran the decay's length *inverse* to the
width, because what it had to spend was the off-time: a wide pulse had nowhere
to decay into.

The ramps are curved rather than linear, which is what makes them read as an
envelope rather than as a triangle: the attack is concave and the decay convex.

## What the modes share

- **Phase 0 is the rising edge** in every shape: it is where PWM opens its gate
  and where the stepped mode starts step 0. A square channel at a whole division
  is therefore a clock divider whose gate opens on the beat.
- **The knobs do not change the level.** Each shape either reaches full swing by
  construction (wavetable, PWM) or is corrected to a steady one (stepped), so a
  turn changes what the shape does rather than how much of it there is. How loud
  is AMP's business, and where it sits is OFS's.
- **AMP, OFS, FRQ and PHS mean the same thing everywhere**, which is what makes
  the mode a property of the channel rather than a different instrument.

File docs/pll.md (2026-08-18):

# The sync loop

How a channel's phase is locked to the incoming clock, what it measures, and
the record of the rework that got it here. `tests/test_pll.c` prints the table
below on every run; re-run it after touching the loop and diff.

The work this describes is done. It is kept because the numbers are the only
way to tell whether a future change to the loop is an improvement, and because
two of the three defects found were things the code looked correct about.

## What the loop is, as built

`channel_compute` runs a proportional controller per channel. **As it stands
today**, after the four steps below:

```
q, p     = the latched rational: q beats hold p cycles      // see Step 4
target   = frac(((beat_counter % q) + beat_phase) * p / q)  // the clock's grid
diff     = phase_error(target, shared_phase, 1.0)           // cycles
pull     = clamp(diff / PLL_TAU_S, +/- PLL_MAX_PULL * freq)
correction += (pull - correction) * (dt / PLL_SMOOTH_S)
phase   += dt * (freq + correction)                         // wraps at one cycle
```

The rest of this section describes it **as it was first measured**, which is
where the record starts:

```
target  = ((beat_counter % gcd) + beat_phase) * freq_multiplier
diff    = phase_error(target, shared_phase, phase_length)     // wrapped, cycles
correction += (diff - correction) * k_sync                    // k_sync = 0.075/tick
phase  += dt * (freq + correction)
```

`gcd = find_denominator(freq_multiplier, 8, 0.025)` is the alignment period in
beats — the number of beats after which the channel returns to the same phase.
`phase_length = gcd * freq_multiplier` cycles is the super-period the error
wraps in.

Two things the measurements settled that were not obvious from reading it:

- **`k_sync` is not the loop's time constant.** It is an EMA coefficient per
  tick, so at 250us its time constant is ~3.3ms — three hundred times faster
  than the loop itself. `correction` therefore tracks `diff` essentially
  instantly, and the loop reduces to `d(phase)/dt = freq + 1.0 * error`: a pure
  P controller with an implicit gain of 1/second.
- **So the response is first-order with tau = 1s**, and is nearly independent of
  the control rate. Measured: a half-cycle phase step settles to 1% of a beat in
  3.90s at a 250us tick and 3.87s at 1000us. `ln(0.5/0.01) = 3.9`, which is the
  whole story.

## Step 1: the harness

- `tests/pll_metrics.{c,h}` — a clock generator that drives the fixture at a
  tempo (with optional deterministic jitter), a trace, and the metrics:
  settling time, peak error, ringing (sign changes past a deadband), peak
  frequency pull, frequency slew, steady-state RMS, and alignment-period flips.
  Errors are in **beats**, so they compare across ratios.
- `tests/test_pll.c` — twelve scenarios. Bounds are deliberately loose: the
  point is the printed table, which is the before-picture to diff against.
- `ChannelEffective.phase_error` publishes what the loop is minimising, so the
  tests measure the loop's own quantity rather than a re-derivation that could
  drift from it.

### Baseline (2026-08-04, k_sync 0.075, tau ~1s)

```
scenario                             settle     peak  cross     fdev     fslew  rms_tail   gcd
                                          s    beats      n   x rate  x rate/s     beats flips
lock, x1 @ 120bpm                     0.000   0.0027      0    0.001       0.0   0.00002     0
scene A->B, x1 -> x2 (snap)           3.212   0.2500      0    0.123      34.7   0.00002     0
scene sweep, during the 1s move       never   3.0789     12    1.398     461.9   1.46698    44
scene sweep, settling after           3.164   0.2391      0    0.120       0.1   0.00002     0
ratio sweep x1 -> x4 over 3s          never   3.5626     20    1.721     543.1   1.21583   108
phase step, half a cycle              3.902   0.5000      0    0.246      69.4   0.00002     0
tempo step, 120 -> 140bpm             3.016   0.0728      0    0.032       5.1   0.00031     0
x0.75, 240s alignment                 0.000   0.0003      0    0.000       0.0   0.00019     0
x1, 5% clock jitter                  29.988   0.0272     38    0.014       3.2   0.01048     0
clock lost 6s, then back              0.000   0.0007      0    0.000       0.1   0.00002     0
phase step @ 250us tick               3.901   0.4999      0    0.246      48.9   0.00002     0
phase step @ 1000us tick              3.868   0.4998      0    0.239      12.2   0.00000     0
```

### What it says

**The steady state is excellent.** Long-run alignment at x0.75 (gcd 4, so the
channel only meets the beat every fourth one) holds 0.0002 beats RMS over four
minutes with zero drift. Clock loss and return, tempo steps and jitter are all
absorbed cleanly. Nothing rings: every case is 0 or 1 significant crossings.
The extrapolation-to-beat-multiple approach works — this is the part to keep.

**It is slow, and deliberately over-damped.** ~3.9s to close a half-cycle
error. That is a defensible choice for a module where a lurching LFO is worse
than a late one, and it is why nothing overshoots.

**The one real defect is a moving ratio.** During a crossfade between scenes at
different rates, `find_denominator` changes its answer **44 times in a one-second
fader move** (108 times over three seconds for x1 -> x4). Every change alters
`beat_counter % gcd` by an arbitrary number of beats, so the *target teleports*
and the loop chases a step it did nothing to cause. Consequences, all measured:

- phase error excursions of **3.1 beats** where the fader move itself justifies
  a fraction of one;
- the correction pulling the oscillator to **1.4x its nominal rate** (1.7x for
  the wider sweep) — an audible speed lurch, which is exactly the artifact the
  loop is otherwise tuned to avoid;
- frequency slew of ~460 x rate/s.

Also: a large `gcd` admits a large error, because the error wraps at half the
super-period. At gcd 7 the loop can believe it is 3.5 beats out and correct at
full gain. The excursions above are that mechanism, triggered by the flipping.

## Step 2: done (1-4)

1. **The alignment period is latched.** `EngineState.channels_gcd[]`, taken once
   and re-taken only when the super-period wraps — the "do not change the grid
   under the playhead" rule `st_length_idx` already follows.
2. **The origin is latched with it** (`channels_beat_origin[]`), and the target
   is measured from it: `((beat_counter - origin) % gcd + beat_phase) * ratio`.
   This is what makes a change of period seamless. At the wrap the channel is at
   phase 0 of the period it is leaving, and taking the origin there defines the
   new period to start in the same place — so the target does not move at all.
   Re-basing anywhere else could not work: the origins differ by a whole number
   of *beats*, which is not a whole number of *cycles*, so it would step the
   output waveform.
3. **The correction is clamped** to `PLL_MAX_PULL` (0.15) of the channel's
   nominal rate. Past that the error closes at a constant rate instead of an
   exponential one — slower for a large error, and inaudible.
4. **`PLL_TAU_S`, `PLL_MAX_PULL`, `PLL_SMOOTH_S`** in `channel.h`, all in
   seconds or in fractions of the rate. The smoothing coefficient is now
   `dt / PLL_SMOOTH_S` rather than a per-tick constant.
5. **Not done, and argued against.** An integral term buys nothing measurable
   here: the steady-state residual under a tempo error is 0.0003 beats, and a
   second pole is the thing that would introduce the overshoot this loop is
   valued for not having.

### After (2026-08-04, PLL_TAU_S 1.0, PLL_MAX_PULL 0.15)

```
scenario                             settle     peak  cross     fdev     fslew  rms_tail   gcd
                                          s    beats      n   x rate  x rate/s     beats flips
lock, x1 @ 120bpm                     0.000   0.0027      0    0.001       0.0   0.00002     0
scene A->B, x1 -> x2 (snap)           3.212   0.2500      0    0.123      38.2   0.00002     0
scene sweep, during the 1s move       never   0.2858      0    0.142       0.7   0.23821     1
scene sweep, settling after           3.341   0.2852      0    0.142       0.2   0.00002     1
ratio sweep x1 -> x4 over 3s          never   0.9004      0    0.150       1.7   0.84237     2
phase step, half a cycle              4.060   0.5000      0    0.150      45.9   0.00002     0
tempo step, 120 -> 140bpm             3.017   0.0728      0    0.032       5.6   0.00031     0
x0.75, 240s alignment                 0.000   0.0003      0    0.000       0.0   0.00019     0
x1, 5% clock jitter                  29.988   0.0272     38    0.014       3.5   0.01048     0
clock lost 6s, then back              0.000   0.0007      0    0.000       0.1   0.00002     0
phase step @ 250us tick               4.059   0.4999      0    0.150      31.1   0.00002     0
phase step @ 1000us tick              4.056   0.4995      0    0.150       5.9   0.00000     0
```

| | before | after |
|---|---|---|
| crossfade, frequency pull | 1.398x | **0.142x** |
| crossfade, frequency slew | 461.9 | **0.7** |
| crossfade, peak phase error | 3.08 beats | **0.29 beats** |
| gcd flips, 1s crossfade | 44 | **1** |
| gcd flips, 3s x1→x4 sweep | 108 | **2** |
| phase step, settling | 3.90s | 4.06s |
| long-run alignment, jitter, tempo step, clock loss | — | unchanged |

The crossfade artifact is gone: what was a 1.4x speed lurch is now a bounded
0.14x lean, and the frequency slew during a fader move drops by a factor of 660.
The cost is 4% on settling time, from the clamp, exactly as predicted.
Everything that was already good is untouched, to the digit.

## Step 3: two regressions the hardware found

The first pass at (1) latched `gcd` but left the accumulator wrapping at the
super-period. Caught on hardware as an audible click through a slider move, and
then reproduced in the harness as a new metric, `jump` — the step in output
phase that the oscillator's own rate does not account for.

**The accumulator may only ever wrap at one cycle.** The waveform is a function
of phase modulo one, so that wrap is invisible; the sample either side of it is
the same sample. It used to wrap at `gcd * ratio` cycles, which is only a whole
number of cycles when the ratio really is the rational multiple
`find_denominator` claims. That held while gcd was recomputed every tick — to
within its 0.025 tolerance, so the step existed but was under 2.5% of a cycle.
Latching gcd while the ratio kept moving removed the guarantee entirely:
measured at **0.34 of a cycle** through a one-second crossfade.

The alignment period belongs in the error term, not in the accumulator. So:

- `channels_shared_phase[]` is the phase within one cycle, wrapping at one.
- `channels_cycle[]` counts which cycle of the super-period it is on, and
  `channels_period_cycles[]` how many cycles that period holds. The loop's
  error is computed against `cycle + phase` over the whole super-period.

The second regression came out of fixing the first. Reducing the error to a
single cycle is appealing — it bounds the error at half a cycle and the waveform
repeats, so whole cycles of difference are inaudible in the steady state. It is
wrong: the loop then locks to whichever of the `period_cycles` equivalent phases
is nearest, so a x2/3 channel still repeats every three beats but can sit a
third of a cycle off the bar. **Which cycle of the pattern lands on the downbeat
is the entire point of aligning to a beat multiple.** Nothing asserted it;
`the_pattern_lands_on_the_same_beat_every_time` does now.

A third change fell out of the same investigation: a new alignment period is
only taken once the ratio has held still for `PLL_RATIO_STABLE_US`. A ratio
crossing a crossfade is a rational multiple every few ticks and irrational
between them, so acquiring on the instant meant taking and discarding eleven
periods in a second, with the correction switching on and off along with them.

### Final (2026-08-04)

```
scenario                             settle     peak  cross     fdev     fslew  rms_tail      jump
                                          s    beats      n   x rate  x rate/s     beats    cycles
lock, x1 @ 120bpm                     0.000   0.0027      0    0.001       0.0   0.00002   0.00000
scene A->B, x1 -> x2 (snap)           3.212   0.2500      0    0.123      38.2   0.00002   0.00001
scene sweep, during the 1s move       never   0.2367      2    0.116      32.9   0.18348   0.00001
scene sweep, settling after           2.937   0.1902      0    0.095       0.1   0.00002   0.00001
ratio sweep x1 -> x4 over 3s          never   0.2361      4    0.116      45.4   0.05841   0.00002
fader worked back and forth           never   1.7751     12    0.154     100.4   0.37568   0.00003
phase step, half a cycle              4.060   0.5000      0    0.150      45.9   0.00002   0.00001
tempo step, 120 -> 140bpm             3.017   0.0728      0    0.032       5.6   0.00031   0.00001
x0.75, 240s alignment                 0.000   0.0000      0    0.000       0.0   0.00001   0.00000
x1, 5% clock jitter                  29.988   0.0272     38    0.014       3.5   0.01048   0.00000
clock lost 6s, then back              0.000   0.0007      0    0.000       0.1   0.00002   0.00000
phase step @ 250us tick               4.059   0.4999      0    0.150      31.1   0.00002   0.00000
phase step @ 1000us tick              4.056   0.4995      0    0.150       5.9   0.00000   0.00000
```

| | original | final |
|---|---|---|
| crossfade, frequency pull | 1.398x | **0.116x** |
| crossfade, frequency slew | 461.9 | **32.9** |
| crossfade, peak phase error | 3.08 beats | **0.24 beats** |
| crossfade, output phase step | 0.025 cycles (by luck) | **0.00001** (by construction) |
| crossfade, settling after | 3.16s | 2.94s |
| x0.75 long-run alignment, RMS | 0.00019 beats | **0.00001 beats** |
| phase step, settling | 3.90s | 4.06s |

### Re-taken at a 2kHz tick (2026-08-16)

`ENGINE_TICK_US` went 250 to 500, and the baseline moves with it. Taking it
again turned up a defect that had nothing to do with the rate.

The rate was decided by the *worst* case rather than the typical one: a moving
crossfader empties the stepped caches every tick, because every scene blend is a
new setting, and that costs 359 us however fast the tick is. At 312 us a fader
sweep took `engine_fps` to 2440; at 500 us the same case holds 2000.

**`Clock_Poll` wrapped `beat_phase` past a beat `beat_counter` had not reached.**
The phase is interpolated between pulses and was wrapped with a
`while (next_phase >= 1.0f) next_phase -= 1.0f`, while only a pulse advances the
counter. `channel.c` reads the two together - the target is
`(beats_in % gcd) + beat_phase` - so for the ticks between a beat falling due
and its pulse arriving, every locked channel was pulled by a whole beat of
target at once. It now holds at the end of the beat instead, which is the honest
reading: the next pulse is the evidence that the beat turned over, so a late
pulse stretches the beat.

It read as a single-tick excursion of 0.25 cycles on every beat boundary at
x0.75 - `max` 0.334 beats with `rms_tail` staying clean, because each one lasted
one sample. **Sweeping the tick period, the whole band from 280 to 345 µs showed
it and 250, 260, 360 and 400 µs did not**, which is why nothing had caught it in
two years of running the suite at 250. The suite now passes at every period from
250 µs to 500 µs.

```
scenario                             settle     peak  cross     fdev     fslew  rms_tail      jump
                                          s    beats      n   x rate  x rate/s     beats    cycles
lock, x1 @ 120bpm                     0.000   0.0026      0    0.001       0.0   0.00002   0.00000
scene A->B, x1 -> x2 (snap)           3.213   0.2500      0    0.123      34.7   0.00000   0.00003
scene sweep, during the 1s move       never   0.2368      2    0.116      32.8   0.18370   0.00002
scene sweep, settling after           2.938   0.1903      0    0.095       0.1   0.00000   0.00001
ratio sweep x1 -> x4 over 3s          never   0.2362      4    0.116      45.4   0.05839   0.00006
fader worked back and forth           never   1.7739     12    0.153     100.5   0.37573   0.00014
phase step, half a cycle              3.894   0.4500      0    0.150      41.7   0.00002   0.00002
tempo step, 120 -> 140bpm             2.992   0.0725      0    0.032       5.6   0.00059   0.00001
x0.75, 240s alignment                 0.000   0.0000      0    0.000       0.0   0.00003   0.00000
x1, 5% clock jitter                  29.986   0.0268     40    0.013       2.9   0.01048   0.00000
clock lost 6s, then back              0.000   0.0009      0    0.000       0.1   0.00002   0.00000
phase step @ 500us tick               4.058   0.4998      0    0.150      18.7   0.00002   0.00000
phase step @ 2000us tick              4.240   0.4973      0    0.150       0.3   0.00206   0.00000
```

What moved, and why:

- **`rms_tail` is unchanged at 0.00002 beats.** The residual is set by how
  finely the loop can place a correction, and at 500 us it is still far below
  anything audible.
- **`x0.75, 240s` peak 0.0000 → 0.0006.** Was 0.3339 before the clock fix.
- **`clock lost 6s, then back` settles in 1.25 s where it used to read 0.000.**
  The old zero was the wrap papering over the re-acquisition; holding the phase
  at the end of the beat makes the recovery visible instead of instant-looking.
- **Gates on the input are not affected by any of this.** They are latched in
  the DAC's own interrupt, which samples each converter channel at ~8 kHz, and
  consumed once per tick - so a gate shorter than a tick is still seen. What the
  longer tick costs is the *timestamp*: an edge is attributed to the tick that
  consumed it, so the clock's pulse times carry up to 500 us of quantisation.
  See "Still to check on hardware".
- **The phase-step case steps 0.45 of a cycle, not 0.50.** Exactly half sits on
  the wrap point of `phase_error`, where +0.5 and -0.5 are the same place and
  which way the loop corrects is decided by the last bit of the arithmetic. The
  pick registers as a zero crossing, and `overshoot_beats` - the largest error
  *after* the first crossing - then reports the undisturbed error as overshoot.
  Which side it picked depended on the tick period. Settling, ringing and the
  tail still cover the exactly-half case.

### Timestamping clock edges in the DAC interrupt: measured, not worth it

A tick consumes a clock edge that was *detected* up to a tick earlier - the
latch in the DAC's DMA interrupt records that an edge happened, not when - so
`Clock_Trigger` is given the tick's timestamp. Stamping the edge where it is
detected would put it on the DAC's 62.5 us chunk instead of the engine's 500 us
tick. That is a change across the seam, so it was measured first.

Driving `ClockState` with a perfectly regular clock, so every bit of the error
is quantisation, and taking the *variation* in `beat_phase` rather than its
offset (which is arbitrary - it depends where the first pulse landed):

| edge stamped at | rms, beats | peak |
|---|---|---|
| the tick, 500 us - today | 0.000551 | 0.001233 |
| the DAC chunk, 63 us - the proposal | 0.000070 | 0.000154 |
| exactly - the ceiling | 0.000001 | 0.000003 |
| a 250 us tick - the old engine rate | 0.000274 | 0.000621 |

So the proposal is real: **8x less phase jitter into the loop**, and it would
more than pay back what the 2 kHz tick cost on the input side.

**And it does not matter, because of what is downstream.** The loop's time
constant is 1 s against a pulse rate of 4-24 Hz, so it attenuates this by about
28x: `rms_tail` in the table above is **0.00002 beats with today's stamping**,
which is 10 us at 120 BPM. One DAC frame at 4032 frames/s is **248 us**. The
residual is twenty-five times smaller than the interval between two output
samples - it cannot be observed at the output even in principle.

Worth revisiting only if `PLL_TAU_S` is ever taken far below 1 s. A loop that
tracked the clock aggressively would pass this jitter through instead of
filtering it, and then where the edge is stamped starts to show.

Nothing is missed, either way: gates are latched in that interrupt at ~8 kHz and
consumed once per tick, so a gate far shorter than a tick is still seen.

## Step 4: the grid was the channel's, and it should have been the module's

Two defects, both from the Step 2/3 rework, both found on hardware and then
reproduced in the simulator. They share a cause: the thing the loop aligns to
was per-channel latched state, and per-channel latched state can go stale or
diverge from the next channel's.

### Two channels at one rate, locked exactly 180 degrees apart

The target was measured from `channels_beat_origin[]`, a beat latched per
channel. A new origin was allowed wherever the channel's *own old* period said
the move was seamless - `(beat_counter - origin) % gcd == 0`. **At gcd 1 that
test is vacuously true**, so a channel crossfaded out to x1 and back to x1/2
re-based on whatever beat the fader happened to settle on. An origin one beat
out at x1/2 is half a cycle. Two identical channels, both locked, both steady,
and exactly 180 degrees apart, for as long as the patch was left alone. A
quarter cycle at x1/4, which is the other one that was heard.

The parity is the tell: sweeping the detour length by whole beats, the gap after
came out 0.0000, 0.5000, 0.0000, 0.5000. Half the return beats landed on the
right grid by luck, which is why it looked intermittent.

There is now no per-channel origin. **The grid is `clock.beat_counter`**, which
every channel reads and none of them can disagree about. `Clock_Reset` zeroes
that counter, so a reset re-establishes the grid for everything at once - which
is what the module was already observed to do, and now it is the mechanism
rather than a coincidence.

The `clock_lock` flow moved with this, and the move is the point: the old golden
had the x1/3 channel starting its three-beat period on the beat where its FRQ
encoder happened to be turned. Replaying the same flow with that gesture 500 ms
later shifted the x2/3 channel from 1.005 to 1.505 of its period before the fix,
and does not move it at all after.

### A rate change that kept its denominator, and the wander that followed

The alignment rational is `q` beats to `p` cycles. `p` was computed only inside
the branch that saw `q` change:

- so it was **never taken on the first acquisition at all** - it sat at the
  initial 1 for the life of any channel whose ratio never moved, and was only
  ever right by luck;
- and it went **stale on every move between two ratios that share a `q`**.
  x1/4 and x3/4 both answer q 4. x1, x2, x3 and x4 all answer q 1.

A stale `p` is a super-period the channel's own cycle counter overruns: the loop
compares a target confined to one cycle against a position roaming over three.
Measured at x3/4 -> x1/4, left alone: **peak error 4.6 beats, steady-state RMS
3.19 beats, and the correction pinned on the `PLL_MAX_PULL` clamp with the sign
crossing back and forth indefinitely.** That is the slow wander heard on the
module. It now reads 0.00006 beats RMS with the correction at zero.

`q` and `p` are one fact and are latched together, whenever either half of them
changes.

### The cycle counter is gone, and it cost nothing

Step 3 argued that reducing the error to a single cycle would let a x2/3 channel
"sit a third of a cycle off the bar", and added `channels_cycle[]` and
`channels_period_cycles[]` to measure the error over the whole super-period.

**The argument does not hold.** `find_denominator` returns the *smallest* q it
can, so `p/q` is in lowest terms, so the q beat positions map to q *distinct*
phases within one cycle - for x2/3 they are 0, 2/3 and 1/3. The fraction alone
says which beat of the period the channel is on; there is nothing to confuse.

The evidence that it was never load-bearing: because of the bug above, `p` was 1
on every channel that had not changed rate, so the error *was* being measured
over one cycle on the common path, and had been for the life of the feature.
`the_pattern_lands_on_the_same_beat_every_time` passed throughout, and passes
now, and is the guard for exactly this.

So the error is taken over one cycle, `channels_cycle[]` and
`channels_beat_origin[]` are gone, and `BmcvInstance` is 80 bytes smaller.

### The target is p/q, not the live ratio

The remaining piece. The target used to be `beat_mode * freq_multiplier`, which
steps at the wrap of `beat_counter % q` by `(q * ratio) mod p` whenever the live
ratio and the latched rational disagree - which is every crossfade, and every
moment a stale rational is in force. Using `p/q` instead, the target has advanced
by exactly `q * p/q = p` cycles at the wrap, so its fraction is unchanged and the
target is **continuous by construction**, however far the ratio has moved away.

That is what makes it safe to drop Step 2's "wait for the super-period to wrap"
gate: there is nothing discontinuous left to protect. What replaces it is far
cheaper - the rational is swapped within `PLL_RETAKE_WINDOW` of the top of a
beat, where the old grid and the new one agree. Swapping mid-beat instead costs
22 x rate/s of frequency slew on a scene snap; swapping at the beat top costs
0.5.

### After (2026-08-18)

```
scenario                             settle     peak  cross     fdev     fslew  rms_tail      jump
                                          s    beats      n   x rate  x rate/s     beats    cycles
lock, x1 @ 120bpm                     0.000   0.0026      0    0.001       0.0   0.00002   0.00000
scene A->B, x1 -> x2 (snap)           3.340   0.2217      0    0.110       0.5   0.00000   0.00001
scene sweep, during the 1s move       never   0.2777      1    0.138      92.3   0.20495   0.00008
scene sweep, settling after           3.181   0.1891      1    0.094       0.5   0.00000   0.00001
ratio sweep x1 -> x4 over 3s          never   0.2777     17    0.138      92.3   0.08261   0.00009
fader worked back and forth           never   0.6663     51    0.153     101.1   0.18585   0.00009
phase step, half a cycle              3.894   0.4500      0    0.150      41.7   0.00002   0.00002
tempo step, 120 -> 140bpm             2.992   0.0725      0    0.032       5.6   0.00059   0.00001
x0.75, 240s alignment                 0.000   0.0000      0    0.000       0.0   0.00003   0.00000
x1, 5% clock jitter                  29.986   0.0268     40    0.013       2.9   0.01048   0.00000
clock lost 6s, then back              0.000   0.0009      0    0.000       0.1   0.00002   0.00000
phase step @ 500us tick               4.061   0.5000      0    0.150      41.7   0.00002   0.00002
phase step @ 2000us tick              4.248   0.4989      0    0.150      16.7   0.00207   0.00014
```

| | 2026-08-16 | now |
|---|---|---|
| two channels at one rate, after a detour | **0.5 cycles apart** | 0.0000 |
| x3/4 -> x1/4, steady-state RMS | **3.19 beats**, on the clamp | 0.00006 beats |
| scene snap, frequency slew | 34.7 | **0.5** |
| scene snap, peak error | 0.2500 | **0.2217** |
| crossfade settling after, slew | 0.1 | 0.5 |
| fader worked back and forth, peak | 1.7739 | **0.6663** |
| fader worked back and forth, RMS | 0.37573 | **0.18585** |
| sweep, peak error / slew | 0.2362 / 45.4 | 0.2777 / 92.3 |
| steady state, jitter, tempo, clock loss | — | unchanged to the digit |

**What got worse, and why it is accepted.** During a fader that is still moving,
peak error goes 0.236 -> 0.278 beats and slew 45 -> 92 x rate/s. A sweep never
holds a ratio still for `PLL_RATIO_STABLE_US`, so the rational stays at the
pre-sweep value throughout and the loop leans on the clamp against a rate that
is running away from it. The old code tracked the sweep because its target used
the live ratio - which is the same property that made the target step at every
period wrap. The trade is a slightly firmer lean *while a hand is on the fader*
against a target that is continuous and a grid that is shared. Peak error stays
a quarter of a beat, an eighth of what the pre-rework loop did.

## Step 5: retuned faster, once it was correct

With the grid fixed, the remaining complaint was speed: channels drifted into
line rather than snapping to it. `PLL_TAU_S` had been 1.0s since it was named,
and that number was never chosen - it is what the hand-tuned gain happened to
be. Swept properly, it turns out to have been leaving most of the range unused.

**Nothing in this loop rings, at any speed.** It is first order - one pole, a
pure P controller - so it cannot overshoot in continuous time, and at a 500 us
tick even tau 0.15s is 300 ticks per time constant, nowhere near where
discretisation would change that. The phase-step case reports **0 crossings at
every tau measured from 1.0 down to 0.15**. So ringing is not what bounds the
speed, and the intuition that a faster loop must be a twitchier one is wrong
here.

**What bounds it is jitter.** This loop is the only thing filtering the incoming
clock, and its rejection goes as tau. Measured on the oscillator's own rate
under a 5% jittery clock:

| PLL_TAU_S | 1.0 | 0.5 | 0.35 | 0.25 | 0.2 |
|---|---|---|---|---|---|
| half-cycle step, settling | 3.89s | 2.35s | **1.97s** | 1.75s | 1.66s |
| rate wobble under 5% clock jitter | 0.013 | 0.023 | **0.029** | 0.039 | 0.046 |
| tempo step 120 -> 140, settling | 2.99s | 1.74s | **1.37s** | 1.15s | 0.98s |

Note that `rms_tail` *improves* as tau falls and is no guide here: it measures
phase error, which a faster loop always tracks down. The cost lands on the
output, as rate wobble, which is what the middle row measures.

**`PLL_MAX_PULL` is the separate knob, and it is the one transitions feel.** A
large error spends most of its life on the clamp, so the limit sets how fast it
closes and how far off-rate the channel leans while doing it. At tau 0.35, the
half-cycle step settles in 1.97s at pull 0.15, 1.55s at 0.25 and 1.41s at 0.35.

**Taken: tau 0.35, pull 0.25.** 0.35 is where buying more tail speed starts
costing visible wobble rather than nothing. A quarter off rate is a lean you can
see on a slow LFO and not a lurch; pull 0.35 was measured and rejected because
it pegs the clamp all the way through the settle after a fader move, which is
the artifact the limit exists to prevent.

### After (2026-08-18, PLL_TAU_S 0.35, PLL_MAX_PULL 0.25)

```
scenario                             settle     peak  cross     fdev     fslew  rms_tail      jump
                                          s    beats      n   x rate  x rate/s     beats    cycles
lock, x1 @ 120bpm                     0.000   0.0000      0    0.000       0.0   0.00001   0.00000
scene A->B, x1 -> x2 (snap)           1.253   0.1797      0    0.250       1.4   0.00000   0.00001
scene sweep, during the 1s move       never   0.2519      1    0.250     166.5   0.20411   0.00016
scene sweep, settling after           0.896   0.2321      1    0.250       2.1   0.00000   0.00001
ratio sweep x1 -> x4 over 3s          never   0.2514     16    0.250     166.7   0.08591   0.00024
fader worked back and forth          17.760   0.6664     46    0.256     168.2   0.17508   0.00024
phase step, half a cycle              1.546   0.4500      0    0.250      69.5   0.00001   0.00004
tempo step, 120 -> 140bpm             1.365   0.0509      0    0.067      15.9   0.00058   0.00001
x0.75, 240s alignment                 0.000   0.0000      0    0.000       0.0   0.00001   0.00000
x1, 5% clock jitter                  29.986   0.0207     42    0.029       8.2   0.00889   0.00000
clock lost 6s, then back              0.000   0.0009      0    0.001       0.4   0.00001   0.00000
phase step @ 500us tick               1.646   0.5000      0    0.250      69.5   0.00001   0.00004
phase step @ 2000us tick              1.748   0.4986      0    0.250      27.8   0.00206   0.00022
```

| | tau 1.0 / pull 0.15 | tau 0.35 / pull 0.25 |
|---|---|---|
| half-cycle phase step, settling | 3.894s | **1.546s** |
| scene snap x1 -> x2, settling | 3.340s | **1.253s** |
| crossfade, settling after | 3.181s | **0.896s** |
| tempo step, settling | 2.992s | **1.365s** |
| ringing, every case | 0-1 crossings | 0-1 crossings |
| rate wobble, 5% clock jitter | 0.013 | 0.029 |
| lean during a fader move | 0.138 | 0.250 |
| steady-state RMS, long-run alignment | 0.00003 | **0.00001** |

Nothing got slower and nothing started ringing. What was bought with a 2.5x
faster loop is a doubled rate wobble under a clock that is itself 5% wobbly, and
a quarter-rate rather than a seventh-rate lean while a fader is moving.

**`phase step, half a cycle` now asserts `settle_s < 2.5`.** The suite's bounds
are otherwise deliberately loose, and this one still is in the direction that
matters - it cannot fail on an improvement - but the speed is now a decision
rather than an accident, and something should hold it.

**Where the clock edge is stamped still does not matter**, though this is the
change that would have made it. The argument earlier in this document turned on
`rms_tail` being 0.00002 beats against a 248 us DAC frame; at tau 0.35 it reads
0.00001. Revisit at tau far below 0.2s, not before.

## Step 6: the grid the ratio has left

Step 4 made the target a function of the latched rational `p/q` rather than of
the live ratio, which is what makes it continuous across the wrap of
`beat_counter % q`. The corollary went unhandled, and the module found it.

**A ratio that has moved away from `p/q` describes a grid the oscillator cannot
be on.** A ratio in motion never holds still for `PLL_RATIO_STABLE_US`, so the
rational cannot be re-latched until the fader stops. Until then the error runs
off, wraps at half a cycle, and the correction slams sign on every wrap.

Found on a patch whose two scenes were **x64 and x32** - a whole FRQ sweep apart
rather than a detent, which is what a channel used as an audio-rate LFO looks
like. A one-second fader move **wrapped 49 times, and kept crossing 63 more
times after the fader stopped**: a ~50 Hz square-wave frequency modulation, heard
as grit through the transition rather than as pitch.

This document already predicted the mechanism in Step 4 - "the rational stays at
the pre-sweep value throughout and the loop leans on the clamp against a rate
that is running away from it" - and judged the cost acceptable. At x1 -> x4 it
is. At x64 -> x32 the divergence is thirty times larger, and the loop stops
leaning and starts wrapping. **The suite could not have caught it: every sweep
case in it was a low ratio, which drifts too slowly to wrap inside the move.**

So the correction runs only while the latched rational still describes the rate
the channel is running at - `|ratio * q - p| <= 0.05`, find_denominator's own
tolerance with slack. When it does not, the channel free-runs at the rate asked
for, which is exactly what an unrecognised ratio already got, and acquires the
moment the rate holds still.

`a_sweep_between_distant_ratios_does_not_fight_the_stale_grid` is the guard, and
it pins the crossings that were 49.

### After (2026-08-18)

```
scenario                             settle     peak  cross     fdev     fslew  rms_tail      jump
                                          s    beats      n   x rate  x rate/s     beats    cycles
lock, x1 @ 120bpm                     0.000   0.0000      0    0.000       0.0   0.00001   0.00000
scene A->B, x1 -> x2 (snap)           1.396   0.2500      0    0.250      83.4   0.00000   0.00008
scene sweep, during the 1s move       0.000   0.0022      0    0.003       0.9   0.00000   0.00000
scene sweep, settling after           1.395   0.2498      0    0.250      83.4   0.00000   0.00008
ratio sweep x1 -> x4 over 3s          0.000   0.0025      0    0.003       1.1   0.00000   0.00001
fader worked back and forth           never   0.4728      3    0.250      83.4   0.11087   0.00008
phase step, half a cycle              1.546   0.4500      0    0.250      69.5   0.00001   0.00004
tempo step, 120 -> 140bpm             1.365   0.0509      0    0.067      15.9   0.00058   0.00001
x0.75, 240s alignment                 0.000   0.0000      0    0.000       0.0   0.00001   0.00000
x1, 5% clock jitter                  29.986   0.0207     42    0.029       8.2   0.00889   0.00000
clock lost 6s, then back              0.000   0.0009      0    0.001       0.4   0.00001   0.00000
x64 -> x32, during the 1s move        0.000   0.0000      0    0.000       0.0   0.00000   0.00009
x64 -> x32, settling after            0.000   0.0004      0    0.001       0.2   0.00000   0.00010
phase step @ 500us tick               1.646   0.5000      0    0.250      69.5   0.00001   0.00004
phase step @ 2000us tick              1.748   0.4986      0    0.250      27.8   0.00206   0.00022
```

| | Step 5 | now |
|---|---|---|
| x64 -> x32 sweep, sign crossings | **49 in one second** | 0 |
| x64 -> x32, crossings after it stops | **63** | 0 |
| scene sweep during the move, peak | 0.2519 | **0.0022** |
| scene sweep during the move, slew | 166.5 | **0.9** |
| ratio sweep x1 -> x4, crossings | 16 | **0** |
| ratio sweep x1 -> x4, slew | 166.7 | **1.1** |
| fader worked back and forth, crossings | 46 | **3** |
| fader worked back and forth, RMS | 0.17508 | **0.11087** |
| scene snap x1 -> x2, settling | 1.253s | 1.396s |
| steady state, jitter, tempo, clock loss | — | unchanged |

Every sweep row improves, because the loop is no longer fighting a grid it
cannot reach in any of them. What it costs is 0.14s on a scene *snap*: the
correction is off while the ratio transitions, so acquisition starts later. That
is still 2.4x faster than the 3.34s this loop took before Step 5.

### Still to check on hardware

`PLL_MAX_PULL` is the knob: lower is smoother and slower to acquire, higher is
closer to the old behaviour. `PLL_RATIO_STABLE_US` decides how soon after a
fader stops the channel re-acquires. Re-run `./build-native/test_pll` after any
change and diff the table above.

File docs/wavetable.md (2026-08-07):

# The wavetable

The shape axis of `SHAPE_LFO`. Generated by `tools/gen_wavetable.py` - the
header, its data and the pictures on this page all come out of one run of it, so
a plot here cannot show a shape the firmware does not have. `just wavetable`,
and `just wavetable --report` for the same thing as sparklines in a terminal.

## The named shapes

The wavetable's named shapes

**SINE** is at SHP 0, which is what a channel resets to, and it is `sin(2*pi*p)`
to better than one LSB of the int16 it is stored in. **TRIANGLE** is exact too.
The axis is built from two curve families that share those two shapes exactly,
so the joins between them are identities rather than approximations.

## Where phase 0 is

**The rising edge**, in every shape: zero and rising at phase 0, peak at a
quarter, zero and falling at a half, trough at three quarters.

This is not arbitrary, and it is not only about the wavetable. The other two
shape modes already put their *event* on the beat - `SHAPE_PWM` opens its gate
at phase 0, `SHAPE_STEPPED` begins step 0 at phase 0 - and the wavetable was the
odd one out, with its trough on the beat and its rising edge a quarter of a
cycle late. So PHS 0 meant something different depending on which shape mode a
channel happened to be in.
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

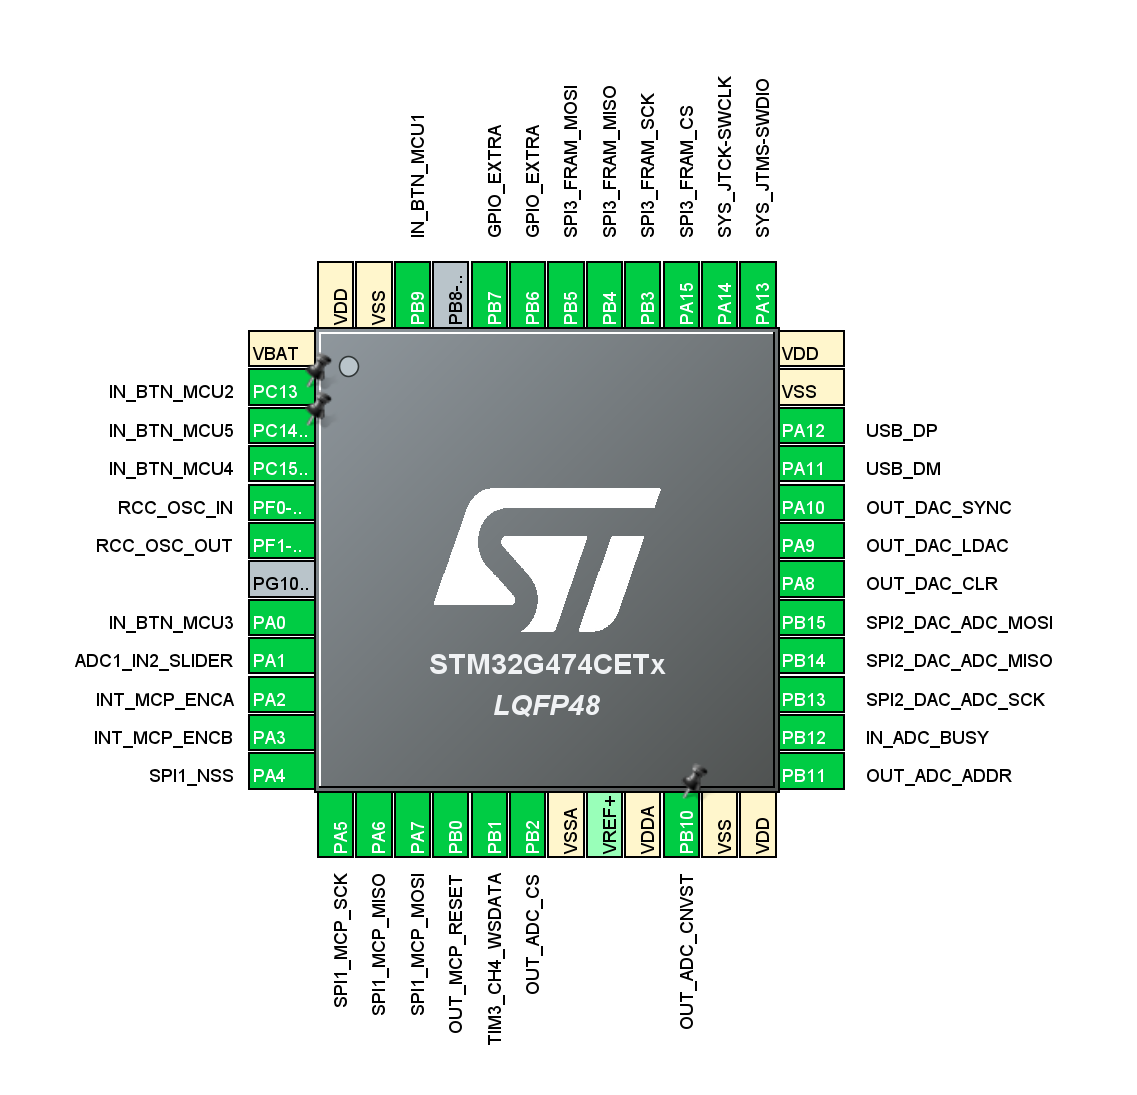
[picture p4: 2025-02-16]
pcb/stm32g4_pinout.png

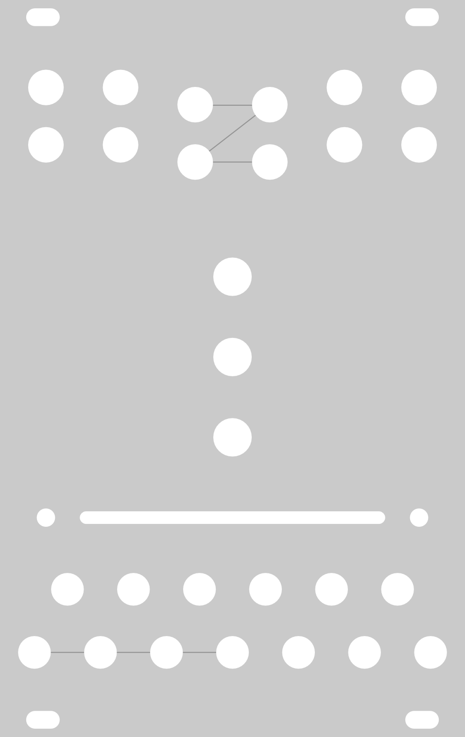
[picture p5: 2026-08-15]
web/bmcv_panel.png

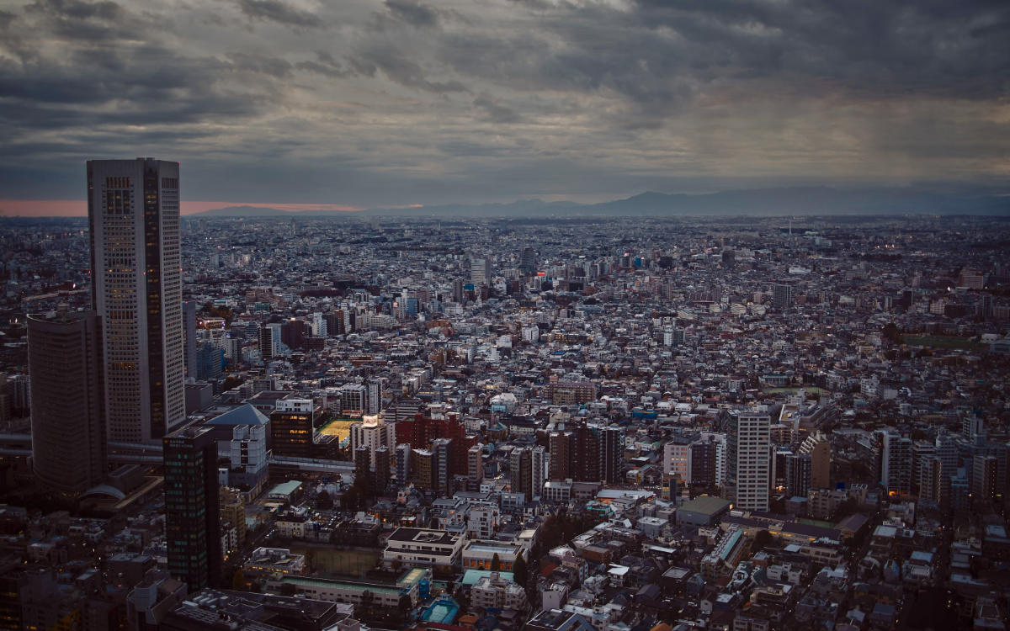
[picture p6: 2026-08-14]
web/bg-tokyo.jpg

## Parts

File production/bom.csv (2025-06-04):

Designator | Footprint | Quantity | Value | LCSC Part #
C1, C2 | 0402 | 2 | 10p | C161520
C10, C16, C7, C9 | 0603 | 4 | 1u | C15849
C100, C101, C102, C103, C44, C45, C47, C49, C50, C52, C53, C55, C56, C58, C59, C61, C62, C64, C65, C67, C8 | 0402 | 21 | 10n | C15195
C104, C105, C106, C107, C108, C109, C110, C111 | 0402 | 8 | 220n | C16772
C112, C12, C13, C18, C26, C27, C28, C29, C3, C30, C31, C32, C33, C34, C35, C36, C37, C38, C39, C4, C40, C41, C42, C43, C46, C5, C6, C78, C82, C83, C93, C94, C95 | 0402 | 33 | 100n | C307331
C14, C17, C19, C20, C21, C22, C23, C24, C25, C48, C51, C54, C57, C73, C74, C87, C89, C91, C92 | 0603 | 19 | 100n | C14663
C15, C97, C98 | 0805 | 3 | 22u | C45783
C60, C63, C66, C68, C69, C70, C71, C72, C75, C76, C77, C79, C80, C81, C84, C88, C90, C96 | 0805 | 18 | 10u | C237493
C85, C86 | 0603 | 2 | 680n | C5143539
F1 | 1206 | 1 | SMD1206P110TF | C20801
FB1, FB2, FB3, FB4 | 0603 | 4 | 470R | C114780
J1, J10, J11, J12, J2, J3, J4, J5, J6, J7, J8, J9 | Jack_3.5mm_QingPu_WQP-PJ398SM_Vertical_CircularHoles | 12 | AudioJack2_SwitchT
J14 | GT-USB-7035E | 1 | USB_C_Receptacle_USB2.0_14P | C22384784
R1, R2 | 0402 | 2 | 5k1 | C25905
R10, R11, R12, R13, R14, R15, R16, R21, R22, R23, R24, R5 | 0603 | 12 | 1M | C22935
R100, R101, R102, R103, R104, R105, R106, R107, R108, R109, R110, R111, R112, R113, R114, R115, R116, R117, R118, R119, R120, R121, R122, R123, R124, R125, R126, R127, R128, R129, R130, R131, R149, R151, R153, R155, R157, R159, R160, R161, R162, R165, R166, R167, R169, R170, R3, R41, R84, R85, R86, R87, R88, R89, R90, R91, R92, R93, R94, R95, R96, R97, R98, R99 | 0402 | 64 | 10k | C25744
R132, R133, R134, R135, R136, R137, R138, R139, R140, R141, R142, R143, R144, R145, R146, R147, R148, R150, R152, R154, R156, R163, R164, R168, R33, R34, R35, R36, R37, R38, R39, R40, R6, R7, R8, R9 | 0402 | 36 | 100 | C25076
R158 | 0402 | 1 | 1k | C11702
R17, R18, R19, R20, R25, R26, R27, R28, R29, R30, R31, R32 | 0603 | 12 | 100 | C22775
R42, R64, R65, R66, R67, R68, R69, R70, R71, R72, R73, R74, R75, R76, R77, R78, R79, R80, R81, R82, R83 | 0402 | 21 | 33 | C25105
R43, R44, R45, R46, R47, R48, R49, R50, R51, R52, R53, R54, R55, R56, R57, R58, R59, R60, R61, R62, R63 | 0402 | 21 | 10 | C25077
RV1, RV10, RV11, RV12, RV2, RV3, RV4, RV5, RV6, RV7, RV8, RV9 | D_SOD-323 | 12 | SD12C-01FTG | C135970
RV13 | ALPHA_B10KX2 | 1 | R_Potentiometer_Dual
SW1, SW10, SW11, SW12, SW13, SW2, SW3, SW4, SW5, SW6, SW7, SW8, SW9 | TC002-N11AXXX-RGB | 13 | TC002-N11AS2XT-RGB
SW14 | TS-1095PS-AXXBX-C3DX | 1 | FN1 | C2834959
SW15 | TS-1095PS-AXXBX-C3DX | 1 | FN2/Boot | C2834959
SW16 | TS-1095PS-AXXBX-C3DX | 1 | FN3 | C2834959
U1, U2, U3, U4, U5, U6, U7, U8 | PEL12T-4xxxS-S1024 | 8 | PEL12T-4225S-S1024
U10, U11, U12, U13, U14, U15, U16, U17, U18, U19, U20, U21, U22, U23, U24, U25, U26, U27, U28, U29, U9 | FSOP-8 | 21 | WS2811F | C5446692
U30, U31 | SSOP-28_5.3x10.2mm_P0.65mm | 2 | MCP23S17_SS | C128577
U32 | TSSOP-20_4.4x6.5mm_P0.65mm | 1 | TXS0108EPW | C17206
U33 | TSSOP-24_4.4x7.8mm_P0.65mm | 1 | AD7367-5 | C650862
U34, U35 | TSSOP-24-1EP_4.4x7.8mm_P0.65mm_EP3.2x5mm | 2 | AD5754R | C392905
U36 | LQFP-48_7x7mm_P0.5mm | 1 | STM32G474CETx | C730125
U37 | SSOP-8_3.9x5.05mm_P1.27mm | 1 | MB85RS64PNF-G-JNERE1 | C8741
U38, U39, U40 | TSSOP-14_4.4x5mm_P0.65mm | 3 | OPA4171 | C529553
U41 | HVSSOP-8-1EP_3x3mm_P0.65mm_EP1.57x1.89mm | 1 | TLV76733 | C2873382
U42 | SOT-353_SC-70-5 | 1 | 74AHCT1G125 | C151417
Y1 | Crystal_SMD_2520-4Pin_2.5x2.0mm | 1 | 38.4MHz 10pF | C3020671

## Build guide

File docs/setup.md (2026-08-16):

# Setup

What to install, once, to build each of the four things this repo builds -
see [architecture.md](architecture.md) for what they are. Every fetchable
dependency (the ARM toolchain, ST's HAL, emsdk, the Rack SDK) is one `just`
recipe away rather than a manual download, and none of them need an account
or an installer: `just arm-sdk` replaces ST's STM32CubeCLT with a couple
hundred megabytes fetched straight from GitHub and ST's own HAL repos.

## Common to everything

- **[`just`](https://just.systems/man/en/packages.html)** runs every recipe
  in this doc. `cargo install just`, `brew install just`, or see the link for
  your platform.
- **CMake 3.22+** and **Ninja**. `apt install cmake ninja-build`,
  `brew install cmake ninja`.
- **git**, **curl** - for the fetch recipes below.
- **Python 3** - the `just wavetable`/`just stepped-table`/`just panel`
  generators, and `just web`'s dev server. Not needed for a build.

## Firmware (ARM)

```
just arm-sdk        # once: fetches the ARM toolchain + STM32Cube HAL
just build            # -> build/BMCVFirmware.elf, build/BMCVFirmware.bin
just flash             # over an ST-Link, via OpenOCD
just flash-usb        # or: over the module's own USB port, no probe
```

### Which of the two flash recipes

`just flash` writes over SWD through an ST-Link. It is the one that can also
halt the core, so it is what `just where` and any breakpoint work sit on. It
needs the module out of the rack with a ribbon on its debug header.

`just flash-usb` writes over the module's panel USB port, through the STM32's
ROM DFU bootloader. No probe, and **the module can stay in the rack** - which
is the point of it, since that port is probably already patched into the
computer for the simulator's live link. You give up halting and breakpoints;
the WebUSB link and the diagnostics page still work, so printf-level debugging
does not go away. See [live-module.md](live-module.md).

It needs the module in update mode first, by either:

- holding **CPY** while the module powers up, or
- pressing the update-mode button on the `just docs-page` updater, which sends
  the same request over WebUSB and needs no hands on the module.

The recipe checks which state the module is in, says what to do, and then waits
for the bootloader to appear - so putting the module into update mode *after*
starting the command is the expected order. It cannot ask for update mode
itself: that request goes over WebUSB to a device that, under WSL, belongs to
Windows, and taking it away with an elevated `usbipd bind` would hide it from
the Windows-side programmer that then has to do the writing.

`build` configures `build/` first if it is not there, so `arm-sdk` really is
the only thing a fresh checkout needs up front. `just configure` reconfigures
from scratch - it deletes `build/` and starts over - which is what you want
after editing `CMakeLists.txt`, and not what you want on every build. The
same holds for each `configure-*` recipe below.

`arm-sdk` fetches two things, both version-pinned in
`scripts/fetch-arm-sdk.sh` for reproducibility:

- The [xPack build](https://github.com/xpack-dev-tools/arm-none-eabi-gcc-xpack)
  of the GNU Arm Embedded toolchain - the same compiler CI installs via
  `apt`, just self-contained rather than a system package. sha256-verified
  against the release's own checksum.
- ST's HAL and CMSIS device headers, sparse-checked-out from
  [STM32CubeG4](https://github.com/STMicroelectronics/STM32CubeG4) at the tag
  named in the script - only the ~30MB the firmware actually compiles
  against, not the multi-gigabyte package with every ST eval board's BSP.

It writes `toolchain.cmake` pointing at both (gitignored - this is meant to
vary per machine) and leaves one alone if it already exists, so re-running
it after an interrupted fetch just finishes the rest. `ARM_GCC_DIR` and
`CUBE_G4_DIR` override where things land, same as `RACK_DIR`/`EMSDK_DIR`
below; both default under `$HOME`.

If you already have STM32CubeCLT (from STM32CubeIDE) and would rather point
at that instead, copy `toolchain.default.cmake` to `toolchain.cmake` and
fill in its two paths - `arm-sdk` is a replacement for that installer, not a
requirement on top of it.

## Native tests and tools

```
just test              # ctest over Core/Src/Lib, host-compiled
just test-san           # the same, under ASan/UBSan
just check              # every host-side check at once
just check-all          # and the firmware and Rack plugin builds too
```

Needs only cmake/ninja/a C compiler - no ARM toolchain, no STM32Cube FW. The
one requirement worth calling out: **GCC 13+**, or a comparably recent
Clang. `Core/Inc/Lib/hw_setup.h` uses `static_assert` as a bare C23 keyword,
which GCC did not support until 13; an older compiler fails several files
deep with a confusing `expected declaration specifiers` rather than
anything mentioning C23, which is why `tests/CMakeLists.txt` and
`sim/CMakeLists.txt` both check for this up front and say so plainly.

Ubuntu 24.04 and Debian 13 ship a new-enough `gcc` as the system compiler.
On an older system, install a newer one alongside it rather than replacing
the system compiler, and point `CC` at it:

```
# Ubuntu 22.04 and older need the toolchain PPA first; 24.04+ has gcc-13
# directly. Debian: gcc-13 is in bookworm-backports on 12, direct on 13.
sudo add-apt-repository -y ppa:ubuntu-toolchain-r/test && sudo apt update
sudo apt install gcc-13
just configure-native && CC=gcc-13 cmake -S tests -B build-native -G Ninja

# or, no root and no package manager needed, into a local prefix:
curl -Ls https://micro.mamba.pm/api/micromamba/linux-64/latest | tar -xj bin/micromamba
MAMBA_ROOT_PREFIX=~/.micromamba ./bin/micromamba create -y -p ~/.gcc13 -c conda-forge gcc=13
CC=~/.gcc13/bin/gcc just configure-native
```

macOS's Clang has had this for years, so this is a Linux-only concern in
practice.

## Web simulator (wasm)

```
just wasm-sdk         # once: clones and builds emsdk (a real build - slow)
just wasm               # -> web/bmcv.js, web/bmcv.wasm
just web                 # serves web/ at http://localhost:8000
```

`wasm-sdk` clones [emsdk](https://github.com/emscripten-core/emsdk) to
`$EMSDK_DIR` (default `~/emsdk`) and installs its `latest` toolchain -
self-contained, needs nothing from the system beyond what emsdk's own
installer wants (Python 3, and on Linux, the usual build-essential
headers). `just wasm-check`/`web-check`/`dfu-check` additionally need
**Node** to run headless against the built module.

`.tool-versions` pins Node 24, which is what CI installs - see
`node-version` in [`ci.yml`](../.github/workflows/ci.yml), and raise the two
together. [mise](https://mise.jdx.dev) and asdf both read that file, so a
checkout gets the right one by cd-ing into it; without either, any Node 24
will do. Nothing here needs a package manager - the three checks are plain
ES modules run straight from the repo, and there is no `package.json`.

## VCV Rack plugin

```
just vcv-install         # -> ~/.local/share/Rack2/plugins-lin-x64/BMCV
just vcv-dist            # -> vcv/dist/BMCV-<version>-<platform>.vcvplugin
```

Both fetch the Rack SDK they need on first use; `just vcv-sdk` does only
that, for priming a machine. Needs `make` and a C/C++ toolchain
(`build-essential` on Debian/Ubuntu, Xcode Command Line Tools on macOS),
plus two smaller things the SDK's own `plugin.mk` shells out to and neither
distribution installs by default:

```
sudo apt install jq zstd     # macOS: brew install jq zstd
```

`jq` reads the slug and version out of `plugin.json`, at make's parse time,
so every build needs it; `zstd` packs the `.vcvplugin`, so `vcv-dist` and
`vcv-install` need it as well. `scripts/vcv-build.sh` checks for both up
front - left to `plugin.mk` a missing one surfaces as `Error 127` against a
line number, after everything has already compiled. GitHub's Ubuntu runners
happen to ship both, so CI is not a check on this.

The same GCC 13+ / modern-Clang requirement as the native
tests applies here too - `vcv/Makefile` compiles the same
`Core/Src/Lib` sources, and checks for it the same way before running
`make -j` turns one real error into a wall of them across every source in
parallel. Pass `CC=`/`CXX=` to build with a non-default compiler.

### Platforms

Every recipe takes a Rack platform name and defaults to this host's:

```
just vcv-dist lin-x64      just vcv-dist mac-x64
just vcv-dist win-x64      just vcv-dist mac-arm64
```

Those four are the entire list, because they are the four Rack publishes an
SDK for. There is **no `lin-arm64`**: on an arm64 Linux machine the plugin
compiles and then has no `libRack.so` to link against, so the recipes stop
with that rather than with `cannot find -lRack`. Everything else in this
repository - firmware, tests, simulator, web frontend - builds there fine.

`win-x64` is a cross build from Linux, which is what a checkout in WSL needs
since Rack on Windows loads a `plugin.dll` and will not look at a `.so`. It
wants the MinGW toolchain, GCC 13 or newer for the same C23 reason as above:

```
sudo apt install gcc-mingw-w64-x86-64 g++-mingw-w64-x86-64   # 24.04+: GCC 13
```

The two mac platforms need a mac - only Apple's toolchain emits a Mach-O
dylib - but either mac builds both: the recipes hand the SDK a `CROSS_COMPILE`
when the CPU you have is not the one you asked for, so `just vcv-dist mac-x64`
works on Apple silicon. If you have no mac at all,
[`vcv.yml`](../.github/workflows/vcv.yml) builds all four on every pull
request and attaches them to each release.

To build the two x86_64 platforms on a machine that is not x86_64, an emulated
container works. Register the emulator and build an image once:

```
docker run --privileged --rm tonistiigi/binfmt --install amd64
printf 'FROM ubuntu:24.04\nRUN apt-get update && apt-get install -y \\\n\
  build-essential jq zstd unzip curl ca-certificates \\\n\
  gcc-mingw-w64-x86-64 g++-mingw-w64-x86-64\n' \
  | docker build --platform linux/amd64 -t bmcv-vcv-builder -
```

then build in it as yourself, so nothing in the checkout ends up root-owned:

```
docker run --rm --platform linux/amd64 -v "$PWD:/repo" -w /repo \
  --user "$(id -u):$(id -g)" -e HOME=/tmp -e RACK_SDK_HOME=/tmp/sdks \
  bmcv-vcv-builder ./scripts/vcv-build.sh win-x64 dist
```

Slow under emulation, but it is how `lin-x64` and `win-x64` were first
verified from an arm64 machine. Nothing reaches macOS this way.

## Versioning (commitizen)

```
pipx install commitizen     # or: pip install --user commitizen
just bump-dry-run             # preview
just bump                      # bump VERSION + CHANGELOG.md, commit, tag
just commit                    # interactive wizard for a correct message
```

Commit messages are [Conventional Commits](https://www.conventionalcommits.org)
- `feat: ...`, `fix: ...`, `feat!: ...` for a breaking change - enforced on pull
requests by the `commits` CI job. `VERSION` and `CHANGELOG.md` are generated
from them and never edited by hand; `Core/Inc/Lib/version.h` is generated from
`VERSION` at configure time, which is why it is not checked in. Pushing to
`main` lets the `release` CI job do the bump instead.

`vcv/plugin.json` is the one thing that does not follow `VERSION`, because it
cannot: Rack refuses to load a plugin whose version does not begin with Rack's
own major, so driving it from `VERSION` would pin this project's major to Rack's
and cost the firmware its semver. It is fixed at `2.0.0` and stays there - it
means "for Rack 2", not "the second version of anything". The firmware version
travels on the released file's name instead,
`BMCV-v0.6.1-lin-x64.vcvplugin`, which is why the plugin shows as 2.0.0 in
Rack's browser however new the firmware inside it is.

## Formatting

```
# Ubuntu/Debian:
sudo apt install clang-format-18
# macOS:
brew install clang-format@18

just fmt-check                          # CI's check
CLANG_FORMAT=clang-format-18 just fmt    # if `clang-format` on PATH isn't 18
```

Pinned to 18 specifically because clang-format's output moves between major
versions - a different version reformatting everything is its own kind of
diff noise.

## Troubleshooting

**`expected declaration specifiers or '...' before numeric constant` in
`hw_setup.h`, or a wall of similar errors across many files at once.** Host
GCC is older than 13 - see [Native tests and tools](#native-tests-and-tools)
above.

**`arm-none-eabi-objcopy: not found` right at the end of an otherwise
successful ARM build.** `toolchain.cmake`'s `ARM_TOOLCHAIN_DIR` is set but
its `bin/` is not on `PATH`, and something predates the fix that makes this
unnecessary - pull the latest `cmake/gcc-arm-none-eabi.cmake`, which now
resolves `objcopy`/`size` the same way it already resolved the compiler.

**`STM32CUBE_FW_PATH = ''` in the CMake configure log, then hundreds of
missing-header errors.** `toolchain.cmake` does not exist yet - run
`just arm-sdk`, or see [Firmware (ARM)](#firmware-arm) above for pointing at
an existing STM32CubeCLT install instead.

**`missing jq` or `missing zstd` from `vcv-build.sh`.** Install them - see
[VCV Rack plugin](#vcv-rack-plugin) above. If the message came from
`plugin.mk` instead (`Error 127`, a plugin.mk line number, after a build that
appeared to be working), the checkout predates the up-front check.

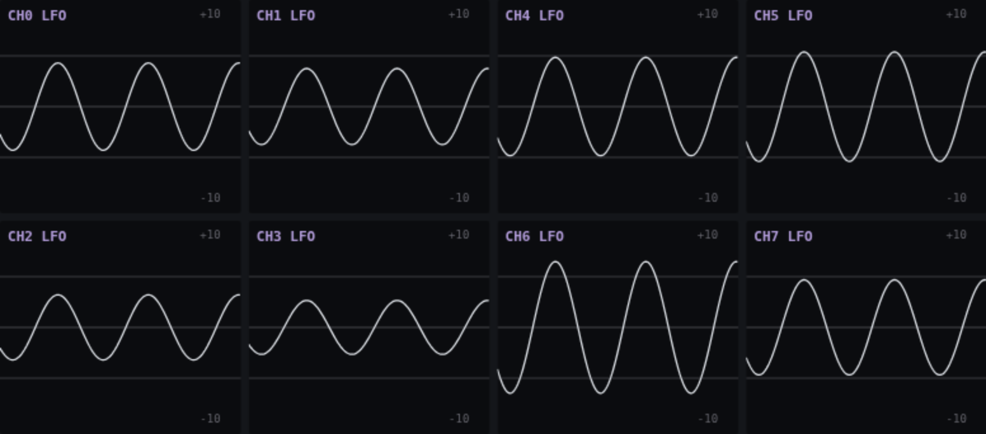
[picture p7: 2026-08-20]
web/manual/scopes.png

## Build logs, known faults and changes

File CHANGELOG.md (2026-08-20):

# Changelog

## v0.20.0 (2026-08-20)

### Feat

- **ui**: red and green mean a voltage, and nothing else on a ring does

## v0.19.0 (2026-08-20)

### Feat

- **ui**: a page is left by its own button, or by letting go of it

## v0.18.0 (2026-08-20)

### Feat

- **pwm**: MOD is an attack and a decay inside the pulse
- **copy**: channel -> channel carries the channel's own settings

### Fix

- **ci**: keep newlib, and let a failed ARM build fail its own step
- **fram**: come back on the last patch, not on the defaults
- **dac**: let the ramp span be a guess, and stop compensating for it

### Perf

- **dac**: two substeps, where the engine has the headroom for them

## v0.17.2 (2026-08-18)

### Fix

- **dac**: put the output back on a continuous ramp
- **pll**: stop correcting toward a grid the ratio has left

### Perf

- **dac**: four substeps a tick, and only the pair that leaves

## v0.17.1 (2026-08-18)

### Fix

- bad PLL sync

## v0.17.0 (2026-08-18)

### Feat

- **stepped**: let a pattern keep a spike, instead of normalising it away

## v0.16.0 (2026-08-17)

### Feat

- **engine**: run the tick at 2kHz, and the DAC at two substeps
- **engine**: run the tick at 3.2kHz

### Fix

- **sim**: copy the snapshot's length on import, not the struct's
- **stepped**: hold the level across the reshapings, not just up to them
- **engine**: keep the derived stepped caches out of the snapshot
- **pll**: stop the beat phase wrapping past a beat the counter has not reached
- **stepped**: remember what a slot offers, not just what a step shows
- **stepped**: pay for a step once, not once per tick
- **dac**: arm the transfer by hand, not through HAL
- **dac**: one substep, because four starved the engine outright
- **dac**: give the outputs a clock instead of the loop's leftovers

### Refactor

- **dac**: drop what the register path made dead, and re-date the docs

### Perf

- **channel**: memoise the alignment-period search on the ratio

## v0.15.0 (2026-08-16)

### Feat

- **sr**: measure what a small turn does to the pattern's order, not its values
- **drift**: a third random mode, with no pattern in it
- **sr**: a second stepped mode, driven for modulation
- **sr**: measure each channel's own pattern, a slot at a time
- **sr**: compute the correction from the pattern, behind a build knob

### Fix

- **dac**: serve a due transaction where it lands, not when the loop notices
- **profile**: ask gdb for plain integers, and say what failed
- **profile**: read the struct's layout from the ELF, not from counting by hand
- **dac**: spread the ramp over the tick that is actually being served
- **sr**: give out one pattern measurement per tick, not one per channel
- **sr**: keep SHP and MOD off the level, and leave the pattern centred

### Refactor

- call it stepped, not stepped random
- **sr**: keep the generator's arithmetic off the channel's path
- **sr**: one stepped mode, and it is the one driven for modulation
- **sr**: make the correction a function, not only a table

## v0.14.1 (2026-08-15)

### Fix

- **usblink**: give each credit counter a single writer, as its comment claimed
- **web**: bound every call the updater makes to the device
- **midi**: count the clocks in a transfer, not whether there were any
- **core**: a request from an interrupt is not a plain uint8_t

## v0.14.0 (2026-08-15)

### Feat

- **build**: flash over USB, with the module still in the rack
- **ui**: a parameter button gives you its parameter, on the way out of a page too

### Fix

- **web**: the scope gap belongs between the cells, not around them
- **ui**: a press and a turn in the same tick is a fine adjust, not a reset

## v0.13.0 (2026-08-15)

### Feat

- **stepped**: give SHP and MOD something to steer, not just reshuffle

## v0.12.0 (2026-08-15)

### Feat

- **panel**: the artwork becomes an opaque panel with the cutouts punched out

## v0.11.1 (2026-08-15)

### Fix

- **web**: shift and the wheel, and a bracket that stopped at three corners

## v0.11.0 (2026-08-15)

### BREAKING CHANGE

- SlotStore holds raw EngineConfigs, so the simulator's storage
blob shrinks from 6400 to 5920 bytes. web/storage.js rejects a blob of the wrong
length and the Rack plugin drops the slot, so a saved browser patch and any
stored Rack presets are lost once, and come back as the first-boot defaults.

### Feat

- **web**: a manual, a menu on every page, and one stylesheet behind all four
- **sim**: one scope window for every source, and a ring that forgets
- **web**: the panel documents itself, and the page says what it is
- **web**: a panel that stays readable while you cross it
- **web**: make the panel explain itself
- **web**: set an input's level by pointing at its trace
- **web**: say what an input is for in the colour the module says it in
- **web**: one hover colour, a table that is there on arrival, and a version to ask for
- **web**: a page with a shape before it has numbers
- **web**: pick a source, and a keyboard that scales
- **web**: read the scopes without having to remember anything
- **web**: stack the scopes, and show what the module is configured as
- carry the module over WebUSB, and delete the SysEx layer
- **usb**: a second interface, for a browser to claim
- **usb**: the descriptors that get a browser to the module with no driver
- **core**: let a host reset a module and forget its storage
- **midi**: drive and watch a module over its own USB port
- **input**: let a host drive a module it did not build
- **web**: show a physical module on the simulator page
- **leds**: lift a dim mixed hue to where its dies behave
- **probe**: publish where the module keeps its state
- **sim**: adopt a whole module as bytes

### Fix

- **web**: the updater must load without a simulator build
- **usb**: let a second browser session reach a module the first left mid-frame
- **web**: hover promises the colour the button is about to wear
- **web**: the scale drew outside its box at wide widths
- **web**: a usb connect that can fail, so that it can be retried
- **web**: one live link at a time, and a switch that looks like one
- **web**: a readable keyboard, brackets that mark something, and a first connect that holds
- **input**: a rebuilt instance is a position, not a gesture
- **midi**: say when the browser is holding a port that no longer reaches anything
- **midi**: remove the watchdog that made the module answer nothing
- **midi**: open the ports before using them, and add a raw bus monitor
- **midi**: keep the module findable, and unwedge its endpoint
- **midi**: stop control changes landing inside a snapshot
- **sysex**: report every message in a transfer, not just the first
- **midi**: let the page pace the module instead of the other way round
- **midi**: find the module by asking it, not by reading its label
- **build**: make a version bump reach the firmware

### Refactor

- MON becomes MIX
- **web**: three sources, one session, and resets that reach the module
- retire the throughput spike, and fix the update page's port lookup
- **config**: store every mode as int8_t so the four builds agree

## v0.10.0 (2026-08-13)

### Feat

- **leds**: rebuild the colour pipeline around light rather than duty

## v0.9.0 (2026-08-11)

### Feat

- **ui**: rework the FRQ ring - prime-limit colour, off-grid wash, rate pulse
- **debug**: publish led_fps, the rate the panel is actually redrawn
- **midi**: publish the channel outputs, inputs and clock as MIDI

## v0.8.0 (2026-08-11)

### Feat

- **ui**: save the selected parameter with the patch, defaulting to OFS

## v0.7.2 (2026-08-10)

### Fix

- **update**: refuse an unusable DFU transfer size instead of guessing
- **leds**: recover from a failed LED DMA instead of freezing the panel

### Refactor

- delete two dead linker scripts and the unused FRAM helpers

## v0.7.1 (2026-08-10)

### Fix

- **leds**: guard led_set_bipolar against a zero divisor and INT32_MIN
- **clock**: drop the pulse history when the clock source changes

## v0.7.0 (2026-08-10)

### Feat

- **release**: publish the firmware .elf alongside the .bin

## v0.6.2 (2026-08-10)

### Fix

- **vcv**: correct the plugin install paths and decouple just from the script

## v0.6.1 (2026-08-08)

### Fix

- **release**: stop release notes from picking up stale changelog prose

## v0.6.0 (2026-08-07)

### Refactor

- reorganize repo with firmware at the root

## v0.5.0 (2026-08-07)

### Feat

- **setup**: fetch the ARM toolchain automatically, document all 4 targets

## v0.4.0 (2026-08-07)

### Feat

- **midi**: drive the clock and reset from MIDI when no input is configured

## v0.3.0 (2026-08-07)

### Feat

- **update**: flash a released version from a dropdown

## v0.2.0 (2026-08-07)

### Feat

- **release**: commitizen versioning and GitHub Pages deploy

### Fix

- **release**: include the CI jobs and CMake wiring from the last commit

## The module flashes itself, from a browser tab

The module has a USB-C port and, until now, no way to use it for the one thing a
USB port on a Eurorack module is for. Updating meant an ST-Link on the
programming header.

It turns out the hardware was already designed for this and nobody had noticed:
tracing the schematic, **FN2 is wired to PB8, which is the chip's BOOT0 pin** —
10k pulldown, 100R series, button to 3V3. Holding FN2 while the case powers up
pulls BOOT0 high and hands the module to the DFU bootloader that lives in the
STM32's mask ROM. No bootloader of ours needed, no flash spent on one, and
nothing that can be bricked, because mask ROM cannot be erased.

So `web/update/` is a page that speaks DfuSe over WebUSB, and the firmware
gained just enough to make the button optional.

### Added

- **A SysEx control channel** (`sysex.c`) on the USB MIDI endpoint the firmware
  already enumerated. Two commands: reboot into update mode, and report the
  running version. Parsing is hardware-free and tested — this is the one path by
  which a passing DAW message could reboot the module mid-set, so the tests are
  mostly about everything it must *not* answer.
- **A reset into the ROM bootloader**, rather than a jump into it. The firmware
  lights the panel, leaves the USB bus, writes a marker to a `.noinit` word and
  resets; `fw_update_check_boot()` reads that marker as the first statement in
  `main()`, before `HAL_Init` and before any peripheral exists, and hands over
  from there.

  The direct jump was tried first and does not work, for a reason worth writing
  down: the bootloader ran - `SCB->VTOR` read back as `0x1FFF0000`, which only
  it sets - but it never brought USB up. The giveaway was that USB and SYSCFG
  registers could not be read over SWD at all while it sat there, because their
  clocks were still gated. It will not initialise a chip it inherits mid-flight,
  however carefully that chip is torn down first. Coming in through FN2 works
  because BOOT0 hands it a chip that has just reset, and the marker-and-reset
  path is how the software route gets the same thing.

  The panel stays amber across the reset for free: the WS2811s latch, and they
  run off +5V rather than off the MCU.
- **`web/update/`** — a separate page from the simulator, so a broken simulator
  build cannot take down the thing that flashes the module. Its DfuSe client is
  written out rather than vendored; the protocol we need is two hundred lines,
  against a library we would use a fifth of.
- **`just dfu-check`**, in `just check`. The flashing sequence is the one thing
  here whose failure mode is a half-written module, and it cannot be tried
  casually, so it is asserted against a fake device: command opcodes, data
  blocks numbered from 2, the short final block sent at its real length, and the
  device resetting mid-leave counted as success rather than failure.
- **The page refuses anything that is not a raw image for this target**, before
  it erases rather than partway through writing. An `.elf` is the mistake that
  matters: it sits next to the `.bin`, it is what the ST-Link workflow leaves
  lying around, and it is not an image at all - byte 0 is an ELF header, not the
  vector table, and a debug build is four times the size of the flash. Writing
  one gets a fifth of the way in and then fails on an address past the end of
  the chip, with the module already erased. Checked by its vector table - first
  word a stack pointer in RAM, second a reset handler in flash - which no
  `.elf`, `.hex` or unrelated file passes. `just dfu-check` asserts it against
  the real built artefacts, both of them.

- **`just where`**, which halts the running module over SWD and resolves PC and
  LR to source lines. A frozen panel looks identical whether the main loop is
  stuck in a spin, sitting in a fault handler, or executing code that no longer
  exists, and this is what tells the three apart. It is what diagnosed the jump
  above, and the manifest stall below.

### Known limits

- **The module does not restart itself after an update - power-cycle the case.**
  The zero-length download that closes a DFU session has to carry block 2, not
  0; block 0 means "this is a command", and a command with no payload is
  discarded, so the session never closed at all. With that fixed the bootloader
  does reach its manifest phase - and then stops. It drops its own USB pull-up
  and parks in dfuMANIFEST-WAIT-RESET, waiting for a bus reset that no longer
  has any route to it, in the place ST's reference implementation calls
  `NVIC_SystemReset()`.

  Measured rather than inferred: PC in ROM at `0x1FFF5064`, `VTOR` at
  `0x1FFF0000`, the app's `uwTick` still zero, and nothing on the bus. Nothing
  the host can send reaches a device that has already disconnected, so this is
  where it stays. The image is fully written by then and the page says so.
- **Update mode shows on the panel only when you got there from the page.** The
  LEDs are set to amber before the reset and the WS2811s latch off +5V, so the
  colour survives it. The FN2 route cannot do this and never will — ST's
  bootloader is running by then and knows nothing about the panel. A dark panel
  in that mode is correct.
- **Windows needs Zadig once**, to bind WinUSB to the bootloader so Chrome can
  claim it. This was the deciding tradeoff: a bootloader of our own carrying MS
  OS 2.0 descriptors would remove the step, but only if those descriptors behave
  on a clean Windows install, which is not verifiable until it is in users'
  hands — against a certain cost in flash, a linker offset, and a new way to
  brick a module.
- **Versions are reported, never enforced.** Any build flashes over any other.
  The ROM bootloader has no concept of a version, so a policy here would only be
  one the recovery path ignores.

## The outputs are left alone

### Removed

- **`DAC_OFFSET_CORRECTION`.** 82 DAC units - about 25mV - were subtracted
  inside `quantize_value()` so that the analog output landed on the true note.
  It described the output stage's zero error, so it reached quantized pitch
  outputs and nothing else: every unquantized channel carried the same error
  uncorrected, and the number was a compile-time constant describing one board.

  Removed rather than generalised. A runtime calibration mode was built and
  measured on the bench, and it could not improve on the untouched outputs: what
  is left after a two-point affine fit is the converter's own INL and the spread
  between channels, and neither is reachable by an offset and a gain. The
  outputs are close enough as they come.

  Quantized output is now an exact semitone and nothing else.

## The tick period is a number now, not an outcome

Two rates ran the module and neither was chosen. The engine's deadline restarted
from `now_us` every tick, so each one began late from wherever the last had
landed and never corrected - a 250us period ran at 263 and `engine_fps` read
3800 against a nominal 4000. The DAC service re-armed on any loop pass a DMA
completion allowed, which happened to give 15.8 chunks per tick because that is
where the HAL turnaround and the tick period crossed.

Both were fine while the DAC only repeated values. Interpolating across a tick
made the first one matter: the fraction divides by the nominal period, so the
output reached its target 13us early and sat flat for the rest of every tick.

### Changed

- **The engine deadline advances by a fixed period instead of restarting.**
  `engine_fps` should now read 4000 rather than 3800, and the drift that made
  nominal and actual disagree is gone - which is what the interpolation needs to
  divide by something meaningful.

  Still not a catch-up. A tick that lands a whole period late is dropped and the
  schedule resynchronised, never repaid as a burst of ticks carrying made-up
  timestamps: the engine is dt-driven, so one long dt is the honest account of a
  loop that could not keep up.

- **The DAC service is rate-limited to a stated ratio.** `DAC_SUBSTEPS` is how
  many times the service covers all eight outputs within one tick, and the chunk
  interval follows from it. The 4x that was emerging by coincidence is now the
  number in the source, which also spreads the chunks evenly instead of letting
  them bunch into the gap between ticks - the ADC's sampling cadence evens out
  with them.

  It is the cheap lever for CPU. A chunk costs single-digit microseconds where a
  tick costs over a hundred, so trading tick rate against substeps holds the
  output rate - and therefore the staircase - while moving real load.

### Added

- **`bmcv_profile.resyncs`**, ticks dropped outright. An overrun is the loop
  running late and catching up; a resync is a tick that never happened. Any
  number here that keeps climbing means the period is too short for the work in
  it, which is the failure that used to be silent.

## The output slides between ticks instead of stepping

A scope on a channel output showed stairs 263us wide - one engine tick - and a
5Hz LFO at full depth climbs them in 41mV jumps. That puts the zero-order-hold
images at the tick rate, 3.8kHz, which is both inside what the output filter
passes and inside where the ear is sharpest; amplitude-modulating with an LFO
was audibly carrying it.

The bus was already fast enough to fix this and was wasting it. The DAC service
ships about four frames per engine tick, and three of them re-sent the previous
value byte for byte, because `DAC_BUF` was only refilled inside the tick gate.
The traffic was being paid for and carrying nothing.

### Changed

- **Channel outputs interpolate between the last two ticks instead of holding
  the last one.** Same frames, same rate, same wire - each one now carries the
  level for the instant it is armed rather than a repeat. Steps go from 263us to
  ~66us and from 41mV to 10mV, moving the images from 3.8kHz to 15.2kHz: 12dB
  off the artifact from the step size alone, and more again from any slope the
  output filter has between those two frequencies.

  Interpolated on elapsed time rather than a sub-step counter, because the tick
  period is not exact - it jitters by a loop pass and overruns roughly every two
  seconds - and a fraction of the time that really passed survives both. A tick
  that runs long holds at its target rather than sliding past it.

  It costs one tick of output latency, the levels for tick N being on the pins
  across tick N+1. Extrapolating instead would have avoided that and overshot
  every direction change, which is a worse artifact than the one being removed.
  A constant level interpolates to itself, so nothing about DC accuracy moves.

  Gates and stepped shapes go through it too, on purpose: a step becoming a
  263us ramp is far short of an audible slew, and gentler through a VCA than the
  broadband click a hard edge is. The costs are a fixed ~50us before a gate
  crosses a downstream trigger threshold and a one-tick transient reaching about
  three quarters of its peak.

  Firmware-side, on the way to the DAC. `engine_state` still holds the exact
  per-tick levels, so internal trigger routing, the LED render, the simulator
  and the VCV module all see what they saw before - which is why no golden flow
  moved.

## The module can be flashed optimized

`just build` produces a Debug build: `CMakeLists.txt` defaults `CMAKE_BUILD_TYPE`
to Debug, and `cmake/gcc-arm-none-eabi.cmake` appends `$<$<CONFIG:DEBUG>:-O0>`
after its global `-O2`, so the last flag wins and every translation unit is
unoptimized. That is what `just flash` has been putting on the module.

The cost is in the engine's hot path. At `-O0`, `fclamp`, `iclamp`,
`phase_mod`, `quantize_value`, `pwm_shape`, `clamp_output`,
`div_round_nearest` and `phase_error` are all real calls with their locals
spilled to the stack, and `channel_compute` runs them eight channels deep at
every tick; at `-O2` none of the eight survives as a symbol. The measurement
that says it out loud is `engine_fps` and `dac_fps` reading the same number:
`bmcv_main` re-arms the DAC once per loop iteration, so the two only agree when
the 250us tick gate is already satisfied on arrival - the loop is running one
pass per tick and the tick is late.

### Added

- **`just configure-rel` / `build-rel` / `flash-rel` / `build-flash-rel`**, the
  same four steps as the Debug set against a RelWithDebInfo build in
  `build-rel/`. RelWithDebInfo rather than Release so it is `-O2` rather than
  `-Os` and keeps its symbols; its own directory so `build/`, `just flash` and
  the `compile_commands.json` symlink clangd reads all still mean the Debug
  build. `scripts/flash.sh` already took the ELF path as `$1`, so `flash-rel`
  is that argument and nothing else changed.

- **`bmcv_profile`, what one tick actually costs.** Optimized, `dac_fps` reads
  ~60000 against `engine_fps` ~3800 - decoupled, where they used to be the same
  number, so the loop now spins between ticks instead of arriving late for each
  one. That says the tick fits, but not by how much: the two rates only bound
  the tick's cost to somewhere between 16 and 85us, because the spare time in a
  period is shared with the DAC service and neither readout separates them.

  So measure it directly. `bmcv.c` reads the Cortex-M4 DWT cycle counter around
  `engine_tick` and around the whole gated block, and keeps last/min/max/average
  of each in `bmcv_profile`, in cycles and in microseconds, plus `load` - the
  average against `ENGINE_TICK_US`. Cycle resolution is 6.9ns where the TIM2
  timestamps everything else uses are 1us, which a tens-of-microseconds span
  needs. Watch it live, the same way `bmcv.engine_state.dac_fps` is watched;
  min and max are sticky and re-arm when written to 0.

  A sticky maximum reached once during startup reads exactly the same as one
  reached every 8ms, so `max_at_tick` records which tick set it and `overruns`
  counts the ticks that ran past `ENGINE_TICK_US`. Against `ticks`, the second
  is a rate rather than an anecdote - which is the difference between a periodic
  cost worth restructuring around and a transient worth ignoring.

  The counter was already enabled - `init_cycle_counter()` has been called from
  `main()` all along, with nothing reading it. The probe costs four register
  loads and a few float operations per tick, under 0.2% of the budget, so it
  stays in the build; `BMCV_PROFILE 0` compiles it out.

## The wavetable is generated, and cannot go quiet

The SHAPE_LFO table was drawn by hand in a visual editor, which is the right way
to find shapes and the wrong way to hold three properties that have to be true
everywhere at once. `tools/gen_wavetable.py` builds it now; `just wavetable`,
with `--report` to see it as sparklines.

### Fixed

- **Two neighbouring slices were the same wave in opposite phase, so the
  channel went silent between them.** Slices 13 and 14: each was full scale on
  its own, and their midpoint cancelled to 0.0003 of a possible 2.0. The
  runtime interpolates across the shape axis, so a knob sitting between two
  entries is the normal case rather than an edge one - nothing had ever checked
  what happened there.
- **A phase below zero made the lookup extrapolate rather than interpolate.**
  The sample index came from a cast, which rounds toward zero, so the fraction
  came out negative and the blend ran past the sample instead of toward it -
  leaving the output range. Floor, not truncate.
- **`shape_table` was defined in the header.** Fine while exactly one file
  included it, a multiple-definition link error the moment a test did. The data
  is `wavetables.c` now and the header declares it.

### Changed

- **Phase 0 is the rising edge, in every shape** - zero and rising at 0, peak at
  a quarter, trough at three quarters. The table used to put the *trough* on the
  beat and its rising edge a quarter of a cycle late, which made it the odd one
  out: `SHAPE_PWM` opens its gate at phase 0 and `SHAPE_STEPPED` begins step 0
  at phase 0, so in both of those the waveform's event is already on the beat.
  PHS 0 therefore meant something different depending on which shape mode a
  channel was in.

  The case that makes it concrete is a square channel used as a **clock
  divider**: a divider whose edge is not on the beat is not one, and at
  divide-by-two the old alignment opened the gate half a beat late every time.
  `a_square_channel_divides_the_clock` drives the real engine against a real
  clock and checks every gate opens on a beat, at both ÷2 and ÷4 - ÷4 alone
  would not have caught it, because there a quarter cycle *is* a whole beat and
  the old edge landed on a beat too, just the wrong one.

  Free, as it turns out: the guarantees below are about all slices sharing the
  *same* anchor phases and not about which phases those are, so the table is
  rotated a quarter cycle on its way out of the generator - an exact shift of
  whole samples. It also puts the canonical shapes in their canonical form, the
  sine being `sin(2*pi*p)` rather than `-cos(2*pi*p)`.
- **Every wave is built from an odd monotone rise curve**, anchored at -1 at
  phase 0 and +1 at phase 0.5 and half-wave antisymmetric. Three things follow
  for nothing, and they are the point of the rewrite:
  - every slice reaches the full swing, at the same phases;
  - **so does every blend of two slices**, because a convex combination of
    monotone rise curves is another one - full amplitude between entries is now
    arithmetic rather than something to be tuned for, and it holds across the
    wrap like everywhere else;
  - the DC offset is exactly zero at every setting. Sweeping SHP used to walk
    the channel's average level by as much as 0.7 of full scale.
- **The canonical shapes are exact.** SINE is at shape 0 - what a channel
  resets to - and is `-cos(2*pi*p)` to better than one LSB; TRIANGLE is exact
  too. The axis is built from two families that share those two shapes exactly,
  so the joins between them are identities rather than approximations.
- **The shape axis is a closed loop**, which it has to be: SHP wraps at the
  parameter (`value += delta * 256` on an int16_t) as well as in the lookup.
  square at shape -1, SINE at 0, TRIANGLE at +0.375, a pointy extreme at
  +0.625, and home to the same square at +1. Slices are spaced evenly in RMS
  rather than evenly in the shape exponent - an exponent axis crowds all its
  visible change into one end, which the first draft of the generator did,
  giving fifteen consecutive slices that were the same square.
- **117 slices become 64, and the table costs 28KB less flash** (47.5% -> 42.0%
  of the G474). The drawn table spent roughly thirty slices on staircases and
  another twenty on pulse widths, which are SHAPE_STEPPED's and SHAPE_PWM's
  jobs now, and had runs of up to five identical slices.
- Saw is deliberately absent: MOD's skew already turns the triangle into one,
  and a saw cannot satisfy the anchoring above - its extreme is at the cycle
  boundary rather than at the half cycle.
- `N` and `M` are `WT_LEN` and `WT_SLICES`. Two single-letter macros in a header
  every DSP file includes is a collision waiting to happen.

### Added

- **`docs/wavetable.md`** and the plots in `docs/images/wavetable-*.svg` - the
  four named shapes at a readable size, and the sweep at every second slice with
  the exact ones picked out. Both written by the same run of the generator that
  writes the header, so a picture in the documentation cannot show a shape the
  firmware does not have. SVG so a reviewer sees a shape change as a diff rather
  than as a new binary, and traces are decimated to about the panel width in
  pixels, which is all a plot can show.

  The strip's sample set is the even grid **unioned with the keyframe indices**,
  so the named shapes are in it by construction. They all sit on multiples of
  four today and any grid would catch them; moving one by a single slice would
  otherwise drop it silently.
- **`tests/test_wavetable.c`** - 1921 checks, asserted against the lookup rather
  than the table, because the lookup is what a channel hears. Full swing and
  zero DC at every setting including between slices, both canonical shapes,
  every wave starting at its minimum and peaking at the half, the loop closing
  with the seam no larger a step than any other, each cycle joining itself, and
  the lookup staying in range for any input at all.

## The sync loop stops lurching through a crossfade

The measurements below found one real defect, and it was not a tuning problem.
Baseline and after-table in `docs/pll.md`.

### Fixed

- **A crossfade between scenes at different rates made the oscillator lurch.**
  The target phase is measured from an origin that repeats every `gcd` beats,
  and `gcd` came from `find_denominator` every tick. That is a search for a
  rational approximation, so as the ratio moves its answer does not move with
  it - it jumps between 8, 7, 6, none, 5 and back. **44 times during a
  one-second fader move**, 108 over a three-second sweep to x4. Every jump moved
  the origin, the target teleported by whole beats, and the loop faithfully
  corrected for a step nothing had caused: 3.1 beats of phase error and the
  channel pulled to **1.4x its own rate**, which is heard.

  `gcd` is latched now (`EngineState.channels_gcd[]`) and re-taken only when the
  super-period wraps - the rule the stepped pattern length already follows, for
  the same reason. The origin is latched with it
  (`channels_beat_origin[]`), and that is what makes the change seamless: at the
  wrap the channel is at phase 0 of the period it is leaving, so defining the
  new period to start there moves the target not at all. Re-basing anywhere else
  cannot work - two origins differ by a whole number of *beats*, which is not a
  whole number of *cycles*, so it would step the output waveform.

  Measured over the whole rework: frequency pull 1.398x -> 0.116x, slew 461.9
  -> 32.9, peak error 3.08 -> 0.24 beats, gcd flips 44 -> 1. Long-run alignment
  on a x0.75 channel improved with it, 0.00019 -> 0.00001 beats RMS, because the
  loop no longer spends corrections on a target that was jumping.

- **The phase accumulator wrapped somewhere other than a whole cycle, and it
  clicked.** Found on hardware, moving the slider.

  The waveform is a function of phase modulo one, so a wrap at exactly one cycle
  is invisible - the sample either side of it is the same sample. The
  accumulator wrapped at the super-period instead, `gcd * ratio` cycles, which
  is a whole number of cycles only when the ratio really is the rational
  multiple `find_denominator` claims. That held while gcd was recomputed every
  tick: it only ever returns a gcd for which `gcd * ratio` is within 0.025 of an
  integer, so the step was there but under 2.5% of a cycle and nobody heard it.
  Latching gcd while the ratio kept moving removed the guarantee, and a
  crossfade stepped the output by up to **0.34 of a cycle**.

  The accumulator is one cycle wide now and nothing else. The super-period
  position the loop needs is `channels_cycle[]` - which cycle of the period the
  oscillator is on - plus that phase, so the thing that wraps oddly is a counter
  nobody hears rather than the phase everybody does.
- **...and the obvious way to fix that would have lost the beat alignment.**
  Reducing the loop's error to a single cycle bounds it at half a cycle and
  costs nothing audible in the steady state, since the waveform repeats. It also
  makes the loop lock to whichever of the equivalent phases is nearest, so a
  x2/3 channel still repeats every three beats but can sit a third of a cycle
  off the bar - and which cycle of the pattern lands on the downbeat is the
  whole point of aligning to a beat multiple. The error is measured over the
  full super-period; `the_pattern_lands_on_the_same_beat_every_time` asserts
  what nothing asserted before.

### Changed

- **A new alignment period is only taken once the ratio has held still**
  (`PLL_RATIO_STABLE_US`, 120ms). A ratio crossing a crossfade is a rational
  multiple every few ticks and irrational between them, so acquiring on the
  instant meant taking and discarding eleven periods in a one-second fader move,
  with the correction switching on and off along with them.
- **The correction is clamped** to `PLL_MAX_PULL` (0.15) of the channel's
  nominal rate. The correction is a speed change, so an unbounded one is an
  unbounded lurch - and since the error wraps at half the super-period, a
  channel on a long alignment period could decide it was three and a half beats
  out and act on it at full gain. Past the clamp a large error closes at a
  constant rate rather than an exponential one: slower, and silent. Costs 4% of
  settling time on the largest error there is (3.90s -> 4.06s).
- **The loop's tuning has names and units.** `PLL_TAU_S`, `PLL_MAX_PULL` and
  `PLL_SMOOTH_S` in `channel.h`, in seconds and in fractions of the rate.
  `k_sync` is gone: it was an EMA coefficient per *tick*, so its time constant
  was a property of the host's control rate, and at 3.3ms it was three hundred
  times faster than the loop and had no say in the response at all. The gain it
  was hiding was 1/second, which is `PLL_TAU_S` 1.0 - so the speed of the loop
  is unchanged, it is just written down.
- `channel_reset_phase` drops the latched period and origin with the phase. A
  reset re-establishes where the beat grid starts, and an origin measured from
  before it would leave the channel repeating on the old one.

### Added

- **`max_phase_jump`** in the PLL metrics: the step in output phase that the
  oscillator's own rate does not account for. This is the invariant - the
  accumulator may only ever wrap at a whole cycle - and it is asserted across
  every moving-ratio case rather than only measured. It is what turned "there is
  sometimes a click" into a number, and it was 0.34 when the click was there.
- **`sim/flows/clock_lock.txt`** - the locked waveform over 16 seconds. Nothing
  in the golden set covered it: the one flow with a clock emits only UI state,
  and the two that emit outputs run without one. Three channels against a 120bpm
  clock at x0.5, x2/3 and x1/3 - periods that come out exactly 1.0000s, 0.7500s
  and 1.5000s - with x2/3 as a 2-against-3 polyrhythm that only returns to phase
  0 on the third beat, so any drift walks the trace through the rows instead of
  repeating on them.

## The sync loop, measured

Step one of two: the phase-lock loop gets numbers before it gets changed. See
`docs/pll.md` for the baseline table and what follows from it.

### Added

- **`tests/pll_metrics.{c,h}`** — a clock generator that drives the fixture at a
  tempo (with deterministic jitter, so a failing run reproduces), a trace, and
  the measurements: settling time, peak error, ringing, peak frequency pull,
  frequency slew, steady-state RMS, and how often the alignment period changed.
  Errors are reported in beats rather than in cycles of the channel's own
  waveform, so a x4 channel and a x0.25 one are comparable.
- **`tests/test_pll.c`** — twelve scenarios: cold lock, scene transitions
  snapped and swept, phase step, tempo step, long-run polyrhythmic alignment,
  a ratio with no beat period at all, clock jitter, clock loss and return, eight
  channels at once, and the same phase step at two control rates. Bounds are
  loose on purpose; the printed table is the artifact, and the point is to diff
  it across a change.
- `ChannelEffective.phase_error` — what the loop is actually minimising. The
  tests measure the loop's own quantity rather than re-deriving it outside,
  which would drift from it the moment the algorithm changes.

### Found

- **The loop is a proportional controller with a time constant of one second**,
  and `k_sync` is not that time constant. It is an EMA coefficient applied per
  tick, so its own time constant is ~3.3ms - three hundred times faster than the
  loop - and `correction` therefore just tracks the error. A half-cycle phase
  step settles in 3.90s at a 250us tick and 3.87s at 1000us, so the response is
  effectively rate-independent, which is not what the code reads like.
- **Steady-state behaviour is very good and should be preserved.** A x0.75
  channel - gcd 4, so it only meets the beat every fourth one - holds 0.0002
  beats RMS over four minutes with no drift. Tempo steps, clock loss and 5%
  jitter are all absorbed. Nothing rings anywhere: 0 or 1 significant crossings
  in every case.
- **A moving ratio is the one real defect.** `find_denominator` changes its
  answer **44 times during a one-second crossfade** between scenes at x1 and x2,
  and 108 times over a three-second sweep to x4. Each change alters
  `beat_counter % gcd` by an arbitrary number of beats, so the target teleports
  and the loop chases a step nothing caused: phase excursions of 3.1 beats, and
  the correction pulling the oscillator to 1.4x its nominal rate. That is an
  audible speed lurch, and it is the artifact the rest of the tuning exists to
  avoid. The error wraps at half the super-period, so a large gcd admits a large
  error - at gcd 7 the loop can believe it is 3.5 beats out and act on it.

## The clock cannot poison the module, and CI runs

### Fixed

- **A clock pulse inside the post-reset guard divided by zero, and the module
  never came back.** `Clock_Trigger` only measures an interval outside the 2ms
  window after a reset, but the divide was not gated on having measured one:
  two pulses inside that window gave `1e6 / 0`. `freq_est` is a leaky
  integrator, so the inf never washed out - every later estimate was inf, every
  channel's phase became NaN, and `wavetable_lookup` was then indexed with
  whatever a NaN casts to. Under ASan that is a read at index -2147483648; on
  the module it is a read from an arbitrary flash address, and on the wasm and
  Rack hosts it is on the audio path. Nothing short of a power cycle recovered.

  Four changes, each independently worth having:
  - The interval is only taken against a pulse that actually happened, and
    `Clock_Reset` drops the pulse history rather than leaving the previous
    run's timing to be measured across the reset. `last_pulse_delta_us` itself
    survives, because it is also `Clock_Poll`'s timeout reference and a reset
    must not make a stopped clock look live.
  - `CLOCK_MIN_PULSE_US` - a pulse closer than 1ms to the last one is not a
    pulse. At four pulses per beat that still admits 15000 BPM, so it only ever
    rejects bounce. Applied before the beat counter, so a bouncing edge does
    not advance the beat either.
  - `CLOCK_BPM_MIN`/`CLOCK_BPM_MAX` - an interval that works out to a tempo
    outside 1..1000 BPM is not a measurement. Rejected rather than clamped: a
    clamp still drags the estimate to the bound and takes several good pulses
    to come back, which is audible as every LFO changing speed at once. Two
    edges 50us apart used to read as a 5kHz beat.
  - `wavetable_lookup` masks `i0`. `i1` was already masked and `i0` was left to
    the caller's contract; one AND makes a bad phase a wrong sample rather than
    a wild read.
- **A non-finite phase is recoverable.** Every comparison against a NaN is
  false, so it survived the wrap, the `fmodf` and the next tick's accumulate -
  once a channel's phase was NaN it stayed NaN. `channel_compute` resets the
  accumulator instead. The clock can no longer produce one, but a host chooses
  its own dt and its own tempo, and one bad frame should cost one cycle rather
  than the channel.
- **An encoder dithering in its detent walked the parameter.** The decoder
  counted a step whenever the quadrature state landed on 00, which scores the
  return leg of a dither and ignores the outward one - so a noisy contact at
  rest accumulated +1 per bounce with nobody touching the panel. Steps are
  accumulated and a detent is emitted per whole quadrature cycle, so the two
  halves cancel exactly and a real turn yields the same one count per detent it
  always did. The first sample after power-on now establishes position rather
  than decoding as movement.

### Added

- **`.github/workflows/ci.yml`.** `just check` is 21 unit tests, four golden
  flows, a headless wasm load and a headless import of the whole frontend, and
  it runs in a couple of seconds with no hardware and no browser - and nothing
  ran it automatically. Four jobs, one per build in `docs/architecture.md`, so
  a failure names the toolchain it failed under:
  - tests + flows, then the same tests again under **ASan/UBSan** (`just
    test-san`). The suite has been clean under it from the day it was added,
    and it is the cheapest thing that would have caught the wavetable read
    above.
  - wasm and the frontend check, under emsdk.
  - **the ARM firmware**, which `just check` does not build - a break confined
    to `BMCV_DRIVER_SOURCES` was otherwise invisible until you flashed. The HAL
    is not vendored, so CI fetches STM32CubeG4 v1.6.1 from ST's public mirror
    with only the two submodules the firmware compiles against, and caches it.
    The size goes into the job summary rather than being gated: the sr-table
    alone moved flash 16 points in one commit, and a number in the log is what
    makes that visible while there is still room to react.
  - `clang-format`, pinned to 18. `.clang-format` existed and nothing enforced
    it.
- **Preset migration** (`config_migrate.{c,h}`). The record format has changed
  three times in as many months and every bump threw away all eight slots -
  correct while the only module is on the bench, wrong the moment somebody else
  has seven scenes dialled in. A version this build knows is now converted:
  - **v3 -> v4** renumbers `shape_mode`. Three stepped modes became one, which
    moved PWM under them; `config_validate` would have clamped SEMI and HARD
    onto PWM, which is the right numeric range and the wrong shape. A channel
    that was SEMI or HARD comes back as `SHAPE_STEPPED` - the shape survives,
    its hold value does not, because hold is not a per-channel setting yet.
  - **v2 -> v3** appends `sr_length_idx` and `clamp_mode` at their defaults and
    **halves every AMP**, because AMP is the peak swing now and was half of it
    then. An unconverted v2 patch would come back twice as loud as it was
    dialled in.
  - The old layouts are spelled out with the types their headers used, not by
    byte offset. A record is only ever read back by the target that wrote it,
    and the layouts genuinely differ between targets - see the note below.
  - `preset_load` checks the CRC over `hdr.length` rather than the current
    struct's size, since an older payload is shorter, and bounds that length
    against what was actually read out of FRAM.
  - A `_Static_assert` on `CONFIG_STATE_VERSION` sits in the way, so the next
    bump is a compile error until somebody says what happens to the records
    already written. `CONFIG_STATE_VERSION` moved to `config.h` for it -
    migration is core code and must not include a driver header, the same
    reason `FRAM_CONFIG_SLOTS` is already there.
- **`mcp_decode.{c,h}`** and `tests/test_mcp_decode.c`. What the two panel
  expanders' port bytes *mean* - the quadrature state machine, the bit-plane
  unpacking, the pin map - had no SPI in it but sat inside `mcp.c` behind the
  HAL, so the one piece of logic every gesture test in the suite depends on was
  the one piece nothing could exercise. It is plain C on the core source list
  now, driven from recorded port bytes: detent counting, dither rejection,
  per-encoder independence, and that the pin map is a permutation rather than
  something with a duplicate in it. `mcp.c` keeps the transfers and the DMA
  state machine.
- `just test-san`, `just build-ci`, `just fmt`, `just fmt-check`.

### Changed

- **The engine runs on a fixed period** (`ENGINE_TICK_US`, 250us). `main()`
  calls `bmcv_main` in a bare `while (1)`, so the engine used to run once per
  iteration and the interval between DAC updates was however long the last pass
  happened to take - an LED flush and a USB frame land in some passes and not
  others. The oscillators are dt-driven and stay correct through that, but the
  samples leaving the module are not evenly spaced and an LFO's edges carry the
  jitter. A floor rather than a catch-up: if the loop cannot keep up, a longer
  dt is the honest thing to hand the engine and `engine_fps` says so. It also
  makes 4kHz true rather than assumed - it is what `web/const.js` and the Rack
  plugin already tick at.
- The USB MIDI output is `midi_publish_inputs()` behind `BMCV_MIDI_CC_INPUTS`,
  and says what it is: the four CV inputs as CC 0x10..0x13 on channel 1. It is
  the only use of the USB MIDI stack, nothing asks for it and nothing
  documented it. Kept and switchable rather than deleted.

### Notes

- **`EngineConfig` is not the same size on the module as in a test.**
  `arm-none-eabi-gcc` defaults to `-fshort-enums` and a host compiler does not,
  so the enum-typed members of `ChannelConfig` are one byte on ARM and four on
  a host: 91 bytes against 97, and 738 against 798 for the whole config. Each
  target is self-consistent - FRAM is only ever read by the module, and a
  host's slot store only by that host - so nothing is broken today. But the
  struct is not a wire format, and anything that would make it one (importing a
  FRAM dump into the simulator, sharing a patch file between hosts) has to fix
  this first. The cure is to give the persisted fields explicit widths, the way
  `shape_mode` and `clamp_mode` already have them, which is a format change and
  wants its own version bump.
- **`find_denominator` is not worth caching.** It runs per channel per tick and
  looks like an obvious cache; measured, it is ~50 cycles, so about 4us of a
  250us budget across all eight channels, against roughly 750 instructions for
  the rest of `channel_compute`. A cache plus its invalidation is more risk than
  1.6% of the control loop is worth while flash is at 47% and RAM at 7%.

## A review pass over the four targets

### Fixed

- **The shipped Rack plugin was linking `tests/fakes/fake_drivers.c`.** Nothing
  in the core has called a driver since the DAC write moved into `bmcv.c`, so
  the stub was dead in all three host builds. Removed from the plugin, the
  simulator and the test library; the file is gone.

### Changed

- **Both hosts open-coded the jack -> converter mapping.** `sim_input_cv()`,
  `sim_input_take_trigs()` and `sim_input_slider()` join the rest of the
  host-side glue in `sim_rt.h`, so filling an `InputSample` is one
  implementation with tests rather than a rule each host has to remember.
  Getting it backwards routes the clock into a modulation input and is
  invisible until something refuses to sync.
- **The Rack widget walked the `HwSetup` index tables to find out what sits
  behind each button.** `panel_layout.h` now carries `panel_button_kind[]`,
  `panel_button_led[]` and `panel_encoder[]`, generated beside the geometry and
  the legends that were already there. Four lookup helpers in `BMCV.cpp` are
  gone with it.
- **`web/leds.js` and `sim/include/led_color.h` are checked against each
  other.** They have to agree or the browser and the Rack module show different
  modules, and nothing linked them but a comment. `web/smoke.mjs` now reads the
  constants out of the C header and compares.

### Local environment

Machine-specific settings no longer live in tracked files:

- **`local.just`**, imported if present and not checked in - the arrangement
  `CMakeLists.txt` already had with `local.cmake`. The Rack SDK path, the
  Windows Rack directory, the SDK version and the browser to drive are all
  overridable there.
- **`vcv/compile_commands.json`**, generated by `just vcv-compdb`. The Rack
  SDK's include paths are per-machine, and `vcv/.clangd` used to invite you to
  paste yours into a tracked file.

### Documentation

- The README opens with what the module *is* and how it is used - the panel,
  the parameter row, scenes and the crossfader, what a shift mode is - instead
  of a TODO list, which has moved to the end.
- **`docs/architecture.md`**: the seam between the core and its four hosts, why
  `sim/` exists, what each build is for, and what is generated rather than
  written.
- **`docs/images/`**, from `just docs-shots`: screenshots of the real frontend
  running the real firmware, driven by a headless browser rather than posed.

## A VCV Rack module, running the firmware

### Added

- **`vcv/` — BMCV as a Rack 2 plugin.** The core is compiled straight out of
  `Core/Src/Lib` from the same list the ARM build, `tests/` and `sim/` use, so
  there is no copy to drift. The module allocates one `BmcvInstance`, samples
  Rack's ports into an `InputSample` every audio frame, ticks the engine on a
  divider at 4kHz and reads `channels_gated_level[]` and `leds[]` back out.
  There is no DSP in the plugin and there must never be any. `just vcv-sdk`,
  `just vcv`, `just vcv-install`.
- **A Windows build, cross-compiled with MinGW-w64** (`just vcv-win-sdk`,
  `just vcv-win-install`), because Rack running on Windows against a checkout
  in WSL cannot load a `.so`. It links libgcc statically as well as libstdc++ -
  Rack's own `plugin.mk` does only the latter, which leaves the DLL importing
  a MinGW runtime file that exists on the build machine and nowhere else.
- **The panel is the real artwork, and the parts are Rack's own.** `just panel`
  emits `vcv/res/BMCV.png` and `vcv/res/BMCV.svg`. Rack derives module width
  from the panel SVG and only lands on the rail grid at a whole number of HP,
  so that one is 81.28mm rather than the 81.0mm the artwork was exported for -
  the 0.28mm gets its own width and offset instead of moving everything else,
  and the image is placed by its board origin so every cutout still lands on
  the control that sits in it. Rack's SVG renderer cannot embed a raster, so
  the SVG is a plain rectangle of the artwork's background colour and the
  plugin draws the image over it - which also means a missing artwork file
  degrades to a blank panel rather than a black one.

  Jacks are `PJ301M`, the lit switches are `VCVLightBezel` with an RGB light
  filling the cap, the three centre tactiles are `TL1105` and the corners have
  Rack's screws: every one of those is both the native part and a fair match
  for what is on the board, and drawing our own versions of them would only
  look like a module that could not be bothered. What is left is what Rack has
  no part for - an endless encoder and a horizontal fader - and those follow
  web/panel.js down to the palette, so the two frontends are one module rather
  than two designs of it.

  `panel_layout.h` gained `PANEL_VCV_*`, `PANEL_ART_*`, the mounting slots and
  the legend tables the widgets and tooltips read.
- **`sim/src/slot_store.c`** — the eight preset slots in memory, factored out
  of `bmcv_sim.c` and now shared with the Rack plugin. Saving a patch writes the
  live config into the autosave slot first, so a reopened patch comes back where
  it was left rather than up to two seconds behind.
- **`sim_tickdiv_reconfig()`** — change the host's sample rate without moving
  the engine's clock. Elapsed time is an unsigned difference, so a timestamp
  that steps back one second is a 71 minute step forward, and every oscillator
  phase and the clock's tempo estimate go with it.

### Fixed

- **HUE_YELLOW was chartreuse.** `led_set_hsv()` divides the wheel into six
  regions of 43, so a hue is pure at a multiple of 43 and a blend in between.
  65 sat two thirds of the way from yellow to green and came out
  `(0.48, 1.00, 0.00)` - and it was only 15 from `HUE_GREEN`, so SHP and AMP
  were nearly the same colour. 43 is yellow. This is the hardware's colour too,
  not only the simulators'.
- **A lit LED washed out to white in Rack.** Rack composites its light layer
  *additively*, which is right over the dark panels its own modules wear and
  wrong over this one: adding a 30%-bright red to a light grey panel gives
  white-pink. The colour now goes down in the base layer, alpha-blended at the
  level `led_color_of()` computed and at web/leds.js's own opacities, so the
  two frontends agree; the light layer carries only the bloom around the part.
  An unlinked module - the module browser's preview - draws dark rather than at
  Rack's default full brightness, because twenty-one lights at once is not what
  a BMCV at rest looks like.
- **A fresh Rack module came up on heap noise.** `SlotStore` is a plain member
  of a `Module`, and a `Module` is allocated with `new`, so `occupied[]` held
  whatever was in that memory: every slot reported itself full,
  `bmcv_instance_init()` "loaded" the autosave slot, and the module booted with
  a -23131 offset, both scenes set to the same one and encoders that moved
  nothing. `slot_store_init()` clears the store rather than trusting its caller
  to have zeroed it - the simulator calloc'd its way past this and never saw it.
- **`config_defaults()` now zeroes the config it fills.** It only ever set the
  handful of fields that are not zero, which was invisible because every caller
  in the firmware passed a zeroed struct - `bmcv_instance_init()` memsets the
  instance. The first host to build one on the stack got a module with a
  -30639 offset and a 0.004Hz oscillator.

### Changed

- **A shift mode takes 350ms to latch, not 150ms.** `UI_T_HOLD`'s only consumer
  is shift-mode entry, and 150ms was short enough to latch a mode when a
  parameter tap was meant. It also widens the tap window by the same amount,
  which *shrinks* the gap between a tap and the `UI_T_LONG` actions rather than
  opening a new one. The tests and flows that hold a button now say
  `UI_T_HOLD + …` instead of a number that happened to clear it.
- The three centre tactiles are drawn at the size of the part. SW14-16 are 7mm
  against 6mm for the lit switches, and a `TL1105` at its native 5.2mm made the
  bigger switch on the board the smaller one on the panel.
- The scroll wheel turns an encoder over its centre cap as well as its ring.
  The cap is a good half of the knob and a wheel that did nothing there read as
  a dead spot - web/panel.js binds both for the same reason.
- `hw_setup.h` uses `static_assert` and `helpers.h` spells out one `void*`
  cast, so the firmware's headers can be read from C++. Both are C23 already;
  neither changes what the firmware compiles to.

## Clearing looks like clearing

### Changed

- **A held press dips out once instead of blinking.** It crosses a threshold,
  drops for 90ms and comes back - "that registered" - rather than pulsing for as
  long as it is held, which reads as something still in progress. At the first
  stage it returns to exactly what the page was showing, so the dip is the whole
  message; the second, wider stage returns brighter and dips again on the way
  there. `blink_fast` had no other user and is gone with it, along with
  `FAST_BLINK_PERIOD`.
- **The held colour is no longer a second purple.** It was the confirmation
  purple over a page tinted a different purple - two shades of the same hue
  meaning different things. It is now the colour of the act itself, which on the
  clear page is what the page is already tinted.
- **Clearing is pink.** Purple means "off" or "default" in half the settings
  lists and "selected" in the other half, which is far too neutral for the one
  page whose whole job is destructive. `HUE_PINK` sits between magenta and red,
  clear of both.
- **A committed copy, save or assign flashes purple**, not green - the same
  purple the source was held in, so the flash says "this is where the thing you
  picked went" in the colour you picked it with.

## Three shape modes, and settings that stop at the ends

### Changed

- **Ctrl-page settings clamp instead of wrapping.** Shape mode, quantize mode,
  cross-modulation mode, output clamp and pattern length are short lists of
  unrelated states, so rolling off one end into the other was the largest
  change available on the page and never a deliberate one. Every list has its
  default at index 0, which makes spinning fully left a reset that can be done
  blind. `delta_modulo_step()` lost its last caller with it.
- **The stepped-random variants are one mode again.** SMOOTH, SEMI and HARD
  were the same algorithm at three hold values - a long list made out of one
  idea. `SHAPE_STEPPED` is what is left, beside the wavetable and PWM. The hold
  values stay in `stepped_random.h` because they are what that parameter's
  range means and the tests exercise it; if hold returns it should return as a
  per-channel setting, the way pattern length did.
- The parameter row has more contrast: unselected buttons drop to `VAL_DIM` 2
  and the selected one rises to `VAL_HIG`, which is roughly five times brighter
  to the eye.

### Fixed

- **Switching to the FRQ page flashed every encoder green.** The frequency hue
  was multiplied by the fast blink to mark it as a coded colour rather than a
  level. That was survivable when touching one channel lit one LED; once
  picking a parameter lit all eight, it became a row flashing in unison - and
  green, because the default frequency lands on a green ratio. It is steady now;
  the hue itself already distinguishes a ratio from a level.

### FRAM

Removing shape modes renumbers the ones after them, so `CONFIG_STATE_VERSION`
goes 3 -> 4 and older records are rejected rather than silently remapped.

## MOD, per shape mode

MOD warped the phase in the wavetable mode and did nothing in the other two.
It now has a job in each, chosen for what that shape actually wants rather than
for what was easy to reuse. SHP picks the shape; MOD is the second axis.

### Added

- **Wavetable: skew.** `phase_mod()` was two straight segments with a slope
  discontinuity where they met - a corner halfway through every cycle - and a
  curvature term riding on the same parameter, so one knob did two things. It is
  now a single rational warp, `p / (p + (1-p)·r)` with `r = (1+mod)/(1-mod)`:
  monotone, both cycle endpoints fixed, smooth everywhere, one divide and no
  `expf`. Negative leans the shape early, positive late - the sign convention
  the other modes follow.
- **Stepped random: density.** MOD scales the tie probability that was the
  fixed `SR_HOLD_PROBABILITY` 0.30. Fully left every step takes a new value;
  fully right the cycle is a handful of long notes. The provisional phase skew
  is gone.
- **PWM: an AD envelope.** MOD 0 is a hard gate; negative snaps up and decays
  through the off-time, positive swells across the on-time and drops at the end.
  Each ramp is confined to its own segment, so the width still means what it
  says at either extreme. The ramps are curved - concave attack, convex decay -
  which is what makes the negative side read as an envelope rather than as a
  triangle. A narrow pulse with MOD hard left is a beat-locked percussive
  envelope, which the module could not previously make.

### Changed

- **The stepped-random normalisation table has a probability axis.** It was
  generated at the one fixed probability, so the correction drifted as soon as
  MOD moved off it - the symptom being a pattern going quiet at some settings
  and not others. Now `[length][probability][morph]`, 8 probability bins over
  `[0, SR_HOLD_MAX]`, interpolated on both bin axes. Costs ~86KB of flash (47%
  used, from 31%). `SR_HOLD_MAX` and `SR_PROB_BINS` are emitted into the
  generated header, so the runtime cannot disagree with the table's own axis,
  and the short-pattern fade moved out of the generator into the runtime.
- `just sr-table` regenerates the table. It had been regenerated by hand, which
  is how it came to still carry `sr_length_param[]` after nothing read it.
- **`wave_fn()` is gone.** Nothing ever called it - `channel_compute` has always
  used the table - so it was a second shape engine that never ran, and it was
  where the phase warp was first written. Its file kept `wavetable_lookup()`
  and is now named after it: `wave_fn.{c,h}` -> `wavetable.{c,h}`.
  `smoothstep_edge()` in helpers.h lost its only caller with it.

### Added tests

- `test_helpers.c`: the phase warp's endpoints, monotonicity, identity at the
  centre, sign convention, and the absence of the corner the old one had.
- Density is asserted directly - counting how many of a pattern's steps take a
  new value - and the loop-closure and range properties are re-checked across
  the whole MOD sweep, since density changes which slots are sources.

## Held presses, the parameter row, and a debuggable module

### Changed

- **A held press now shows what letting go would do.** Nothing acted until the
  release and nothing was shown until after it, so the whole gesture was
  invisible while it was happening. An element being held wears the colour of
  the act, blinking, and a press with a wider second stage - CLR on a channel:
  this scene, or all of them - says so by getting brighter at the threshold.
  Which stages exist comes from `ui_sel_press_stages()` in the selection model,
  so the renderer is not re-deriving the rules the dispatcher follows.
- **`UI_T_HOLD` 100ms -> 150ms**, so latching a shift mode takes a deliberate
  press. The tests that used to hold for a hardcoded 150ms now hold for
  `UI_T_HOLD + 50ms`, so retuning the threshold cannot silently change what
  they cover.
- **The parameter display covers all eight encoders at once** and lasts 2s
  instead of 1s. Seeing where a parameter sits is a comparison between
  channels, which needs the row lit together - and that made the per-channel
  timers pointless, so `channels_edit_hold[8]` is one `param_display_hold`.
  Tapping a parameter button arms it too, including re-tapping the current one;
  the tap that *leaves* a shift mode does not, so exiting lands back on the
  output monitor.
- `channels_edit_hue[]` is gone: the frequency hue is derived from the stored
  parameter (`ui_channel_freq_hue()`) rather than cached when an encoder moves.
  The cache was only ever filled for the channel being turned, which is why
  lighting all eight at once used to paint the untouched ones red.
- **Unselected parameter buttons glow very dim** in their own colour with no
  mode active, so the row says which colour belongs to which parameter. They
  stay dark inside a mode, where only that mode's button is lit.

### Fixed

- **The MCU-viewer setup could not read the module any more.** It samples fixed
  addresses, and the refactors had taken away every global it named. Two
  changes bring it back without giving up the layering: the 2-deep `HwState`
  ring becomes a named `curr`/`prev` pair - only one tick of history was ever
  wanted, and the ring's address alternated every tick, which a sampler cannot
  follow - and the firmware's single `BmcvInstance` gets external linkage and a
  declaration in `bmcv.h`, so `bmcv.engine_state.dac_fps` and everything beside
  it has a stable address. Other hosts still allocate their own instance.
  `tools/bmcv.mcuvproj` is repointed accordingly, including the per-channel
  arrays that became `channels_effective` members.

### Web simulator

- Enabling the clock generator zeroes IN0's fader. Whatever it was left at
  became the gate's low level, so a jack sitting below 0V produced a clock that
  never crossed the threshold.
- The scroll wheel turns an encoder over its centre cap as well as its ring;
  the middle of the knob was a dead spot.
- The crossfader handle wears the same grey as the encoder bodies instead of
  being the brightest thing on the panel.

## MOD freed, output clamp, PWM

`CH_PARAM_MOD` meant two unrelated things: a continuous phase warp in
`SHAPE_LFO`, and a *discrete pattern-length index* in the three stepped modes.
That one overload is what forced `val_neighbour` stepping into the parameter
editor, a mid-cycle latch in the engine, and per-scene crossfading of a value
that cannot meaningfully be crossfaded - there is nothing between 8 steps and
12, so any blend of two scenes landed on a length neither of them asked for.

### Changed

- **Pattern length is a per-channel setting** (`ChannelConfig.sr_length_idx`),
  edited by the channel encoders on the **STA** page. Dark and inert on channels
  that are not in a stepped mode, since there it would do nothing. The engine's
  cycle-boundary latch stays, now latching the setting rather than a value
  derived from MOD.
- **`CH_PARAM_MOD` is continuous again in every mode**, like AMP and OFS, and is
  passed to `stepped_random()` as a second shaping parameter. Its mapping there
  is provisional - a monotonic skew of where the step boundaries fall, which is
  a swing and keeps the loop closing seamlessly - pending a design for what it
  should really do. It does nothing in PWM yet.
- **AMP is the peak swing, not half of it.** A channel at full amplitude now
  covers the whole ±10V the converter can reach on its own; it used to top out
  at ±5V unless an offset or cross-modulation pushed it further, which left the
  wider output clamps unreachable from the oscillator alone. Every level in a
  stored patch doubles - which is moot, since the record version changed anyway.
- **Per-channel output clamp** on the **SAV** page: ±10V, ±5V, 0..10V, 0..5V.
  Applied after cross-modulation, so it bounds what actually leaves the module,
  and it clamps rather than rescales - a channel set to 0..5V does not quietly
  halve everything already dialled in. Not per scene and not touched by a
  channel clear: it describes the rig, not the patch.
- **New shape mode, `SHAPE_PWM`**: a square whose duty follows SHP, kept off
  both end stops so the pulse never disappears. Appended to the enum, so saved
  shape modes keep meaning what they did.
- **A long-press channel clear now clears the whole channel** - MON routing and
  cross-modulation mode, QNT mode and trigger source, shape mode and pattern
  length, on top of every scene's parameters. A channel that reads as cleared
  while an input is still modulating it was a half-state. The output clamp is
  the deliberate exception.
- MUT shows green for passing as well as purple for gated: on the page whose
  subject is mute, "not muted" is a state too, and a dark ring read as neither.
- `INPUT_AMP_MULT` moves from magenta to cyan - at this brightness magenta is a
  hair from the purple that means "off" on the same page.
- `channel_reset` no longer loops the scenes itself; `channel_reset_param`
  already does, since it started honouring `scene < 0`.
- `sr_length_index_from_mod()` and the generated `sr_length_param[]` table are
  gone with the parameter overload that needed them.

### Web simulator

- The input scope's height is taken from the output scope rather than from an
  aspect ratio of its own width, so the two boxes end level whatever widths the
  grid gives them, and its cells carry the same ±10V markers.
- The clock cell's pulse button and bpm box share a row.

### FRAM

`ChannelConfig` gained two bytes, so the record length changed and
`CONFIG_STATE_VERSION` goes 2 -> 3. Presets written by an older build are
rejected on load, which is the existing first-boot path.

## LED language: one fact per LED

The panel had two vocabularies fighting over the same 21 LEDs. Purple meant
"selectable" *and* "off" *and* "muted"; a candidate pulse at 50% duty sat on top
of whatever state colour was underneath, so half the time an element showed the
wrong thing; and a channel's ring showed its output level in every mode, under
whatever that mode was editing. The rules are now stated once, in the README and
in `color_presets.h`, and the renderer follows them.

### Changed

- **A shift mode's channel LEDs show that mode's own setting, and nothing else.**
  New `ChannelBaseLayer` in the mode table, alongside the `SceneBaseLayer` that
  already existed. Output level appears in one arm, selected only by no-mode; a
  mode with no per-channel setting leaves the ring dark rather than falling back
  to the level. `render_channel_edit` shrank to the one case that is genuinely
  transient - the selected parameter, with no mode active.
- **White is the whole vocabulary of assignment.** A pickable element keeps its
  own colour and flashes white for 200ms every 1.6s (`blink_mark`); once a
  source is held, valid destinations are steady white with the flash inverted
  into a dropout, the source is steady purple, and **everything else goes
  dark**. Previously a non-target kept showing its state and read as pressable.
  In MON that means the other seven channels no longer sit there previewing
  their outputs while an input is being routed.
- **Setting-state hues are shared across pages** (`HUE_STATE_*`): index 0 of
  every settings enum - disabled, default, LFO - is purple, cyan is continuous,
  yellow is triggered or clocked, and so on. Each mode used to pick its own
  four colours, so "off" was red on one page and green on another.
- CPY and CLR each have one tint - blue for copy, purple for clear - across
  their channels and scene buttons, since on those pages every element is the
  same act.
- Confirmations: clearing is purple rather than red, loading is cyan. Red is
  errors only.
- **MUT**: rotating is absolute - right unmutes, left mutes - so a row can be
  muted by feel. The press is still a toggle.
- **No mode**: a press on the encoder clears the selected parameter in the
  active scene, and a hold clears it in every scene; both flash purple, longer
  for the wider one. It was a long press only, silently, and only ever touched
  the active scene. `channel_reset_param` now honours `scene < 0` as its header
  had claimed all along.

### Fixed

- **Leaving a shift mode flashed every encoder red.** Mode entry armed the
  transient value display on all eight channels; on the way out to no-mode that
  display is the frequency parameter, whose hue is zero - red - until the
  encoder has been turned at least once. The reveal is gone, because a mode's
  setting is now shown for as long as the mode is active and there is nothing
  left to reveal.
- `web/frontend-check.mjs` checked element ids against a hand-written list of
  what `index.html` contains. It reads the page now.

### Web simulator

- BPM is two readouts: what the clock input measures, and what the oscillators
  are actually running against. They differ whenever the clock stops - the
  engine free-runs at the last tempo - and only the second was shown.
- The channel table shows the phase *offset* that was dialled in rather than the
  live phase, which is already on the scope and moving, plus each channel's
  waveshape mode. Both names and values come from the firmware
  (`BMCV_EFF_PHASE_OFS`, `bmcv_sim_shape_mode_name`).
- Bigger grab ring on the encoders; header tagline and the redundant sentence
  about buttons removed.

## Frontend split

`web/main.js` was 926 lines doing wasm binding, base64 `localStorage`, SVG panel
construction, LED gradients, encoder and slider gestures, two canvas scopes, CV
and clock generators, and the parameter table - the least modular thing in a
tree whose whole theme is modularity. It is now nine modules, none over 300
lines, with `main.js` down to wiring and the frame loop:

| module | what it owns |
|---|---|
| `sim.js` | the wasm module behind readable names; nothing else touches an `_bmcv_sim_*` symbol or a heap pointer |
| `spec.js` | `panel.json` and everything derived from it |
| `panel.js` | the SVG panel and its pointer handling |
| `leds.js` | the 21 WS2812s and their gradients |
| `scope.js` | both scopes |
| `inputs.js` | input faders, gate buttons, clock generator |
| `readouts.js` | the readouts and the channel table |
| `storage.js` | the `localStorage` mirror |
| `const.js` | the numbers more than one of them needs |

### Added

- **`web/frontend-check.mjs`** (`just web-check`): stands up enough of a DOM to
  import all nine modules for real, against the real `bmcv.wasm` and the real
  `panel.json`, then drives frames and asserts the module responded. It catches
  what a static check cannot - a missing export, a module-scope reference to
  something not yet defined, an element id that is not in `index.html`, an
  import cycle leaving a binding uninitialised - without opening a browser.
  `web/smoke.mjs` covers the wasm boundary; this covers everything on top of it.
- `just check` runs everything checkable without hardware or a browser: unit
  tests, golden flows, wasm smoke, frontend check.

### Fixed

- **The drawn crossfader position was published before the saved patch loaded.**
  Restoring reboots the module, which puts `slider_raw` back at one end, so the
  panel and the engine disagreed about where the handle was until the first
  drag. Publishing is now an explicit step in `main.js`, after `restore()`,
  rather than a side effect of building the panel.
- The input scope called `getBoundingClientRect()` every frame to decide
  whether to resize, which forces a layout for a size that only changes when
  the window does. Both canvases now size off a `ResizeObserver`.

### Changed

- The two scope draw functions were near-identical copies; cell drawing (grid,
  decimated trace, border) is shared, and the two differ only in their
  dimensions and whether cells are labelled.
- `IN_ORDER` is derived once in `spec.js`. The fader overlay and the input
  scope both lay out cells in panel order and have to agree - they each
  computed it before.

## Layering cleanup

A review pass over the UI/engine split and the simulator. Behaviour-preserving
except where noted: all four golden flows in `sim/flows/` still match byte for
byte. See `docs/review-ui-engine-split.md` for what was found and what is left.

### Fixed

- **Four test files never failed the build.** Their `main` called
  `TESTKIT_SUMMARY()` without `return`, so it fell off the end and exited 0 -
  ctest reported a green run no matter how many checks failed
  (`test_instance`, `test_panel_spec`, `test_sim_rt`, `test_input_state`).
  Fixed, and `testkit_summary` is now `[[nodiscard]]` so dropping the value is
  a compiler warning rather than a silent pass.
- **A channel counted as triggering another channel from 0.31V.**
  `CHANNEL_TRIG_THRESH` was the input-side value 1024 copied across without
  rescaling: identical numbers, but ADC counts are a quarter of DAC counts at
  the same voltage. Both domains now derive from one documented pair
  (`TRIG_THRESH`/`TRIG_THRESH_DAC`, ~1.25V rising with ~0.98V hysteresis), so a
  trigger means the same voltage wherever it is measured.
- **A save that failed still flashed green.** `SCN_PRESET` ignored
  `ux_preset_store`'s return and emitted the confirmation unconditionally,
  while the adjacent load path checked and raised an error. Store is now
  symmetric (`ERR_PRESET_STORE`).
- **A failed autosave was never retried.** `last_crc` was updated whether or
  not the write succeeded, so the next interval saw no change and did nothing
  until the user edited something else.
- **`preset_store`/`preset_load` did not guard a negative slot**, which would
  wrap the `uint16_t` address and read or write an arbitrary part of FRAM. Not
  reachable from any current caller; the simulator's equivalents already
  checked, and the two backends should not disagree about who validates.
- **Scene buttons 4-6 blinked as candidates in MON and QNT**, where the scene
  row addresses the four input jacks and those three buttons do nothing. The
  renderer drew them dark and then let the context layer paint over it; the
  handler had the guard and the renderer did not.

### Changed

- **Mute is applied by the engine, not by whoever reads the output.**
  `channel_output_level()` advanced the ramp as a side effect and carried a
  prose contract that any host reading outputs must call it - so a host that
  read `channels_output_level[]` directly got ungated audio and a mute ramp
  frozen in place. `engine_tick` now calls `channel_apply_mute` once per tick
  and publishes `EngineState.channels_gated_level[]`; the firmware and the
  simulator both just read it.
- **The DSP takes what it touches.** `channel_compute`, `channel_detect_trigger`,
  `channel_apply_mute`, `channel_init`, `channel_reset*` and `channel_take_trig`
  took `UxState*` - the whole module, interaction layer and preset vtable
  included - and used only a channel index from it. They now take
  `(uint8_t ch, EngineState*, const EngineConfig*, const HwState*)` as needed,
  which is what makes the layering structural rather than a convention, and is
  the shape an audio thread in a plugin host wants.
- **`input_fold.c` (was `input_state.c`) is a transducer again.** It drove the
  clock, reset every channel's phase, cleared error flags and ran the config
  autosave. It now latches `HwState.clock_pulse`/`clock_reset` and stops;
  `engine_tick` acts on them with the same timestamp, and the autosave moved to
  `ux_state.c`, which owns the preset io. `InputFrames` is the frame ring and
  nothing else.
- **The mode table drives the scene LEDs and the keyboard overlay.**
  `render_scene` branched on the descriptor and then re-checked `shift_state`
  three more times for SYS, SAV and STA/STB; `quantizer.c` and
  `render_quantizer` each named `SHIFT_STATE_QNT` themselves. New descriptor
  fields `scene_btn_base`, `xfade_end` and `keyboard_overlay` cover all of it,
  and `SCN_SET_A`/`SCN_SET_B` collapse into one `SCN_SET_XFADE`. Adding a mode
  is a row in `ui_mode.c`.
- **`ui_select.c` no longer names a shift mode.** Arming QNT's trigger mode and
  clearing MON's routing were written inline in the generic "pick a source"
  path. They are `assign_trig_arm_channel` / `assign_input_clear`, dispatched on
  `UiAction` - the vocabulary that file does own.
- **`channel.c` and `scene.c` split by layer.** `channel.c` was 510 lines of
  DSP, UX dispatch, config mutation, presentation tables and a driver call;
  the interaction half is `ui_channel.c` and the scene buttons are `ui_scene.c`.
  The one remaining driver call moved to `bmcv.c`, so nothing in the core
  touches a peripheral.
- **`state.h` split into `config.h`, `hw_state.h` and `engine_state.h`** -
  persisted record, hardware frame, running state - with `ShiftStates` moved to
  `ui_mode.h`, the file that enumerates what each mode does. No umbrella header:
  every file now includes only the layer it uses.
- Names follow the file they live in: `channel_*` for the signal path,
  `ui_channel_*`/`ui_scene_*`/`ui_ctrl_*` for the handlers, `ux_update` for the
  pass, `input_fold` for the sample-to-frame step.
- **First-boot defaults are `config_defaults()`**, next to the validation that
  has to accept them, rather than inline in the composition root.
- `bmcv_sim_mode_name()`/`bmcv_sim_mode_count()` expose the firmware's own mode
  names, and `dump_hw_setup` emits them as `ctrl_names`. The list
  STA/SYS/QNT/... existed in four places - the mode table, the CLI,
  `gen_panel_spec.py` and `web/main.js` - and four copies can disagree. The
  other three are now derived.
- `engine_fps` is measured inside `engine_tick`, so every host reports it the
  same way; both it and `dac_fps` are readable through the sim API.
- Ctrl-button ids mean three things at once (a `ShiftStates`, a
  `ChannelParameters`, an index into `ctrl_button_color[]`) and nothing said so.
  Two `_Static_assert`s in `ui_mode.c` now do.
- `TRIG_SRC_INPUT()`/`TRIG_SRC_CHANNEL()` name the composite trigger-source
  index space that was open-coded as `N_INPUTS + c`. Channel-indexed arrays say
  `N_CHANNELS` rather than `N_ENCODERS`, with a `_Static_assert` where the two
  being equal is relied on.
- `SLIDER_MIN_VALUE`/`SLIDER_MAX_VALUE` moved to `hw_setup.h` (analog
  calibration), the blink periods to `ui_state.h` (presentation),
  `FRAM_CONFIG_SLOTS` to `config.h` so a core file no longer includes a driver
  header for it.
- Both native builds compile with `-Wmissing-prototypes`; `led_set_adcr` and
  `led_set_dac` are wrappers over one `led_set_bipolar`.

### Removed

- **`envelope.c` / `envelope.h`**, an old experiment nothing referenced. It was
  in `BMCV_CORE_SOURCES`, so it compiled into all three builds; the linker was
  already dead-stripping it, which is why the firmware is the same size without
  it.
- `compute_channel_scene()` (empty, no callers, no prototype), `CTRL_DEFAULT`,
  `UxState.last_ux_update` (write-only), `UxState.dt` (a copy of `ui->in.dt`),
  and the commented-out level tables in `channel.c`.
- `ui_render_arm_all_edits` - arming a UI timer is `ui_state.h`'s business, not
  the renderer's (`ui_show_channel_edit` / `ui_show_all_channel_edits`).

## Virtual BMCV

Work toward running the real firmware logic off-target - headless, then in a
browser, later as a VCV Rack module. See `docs/plans/virtual-bmcv.md`.

### Added

- **Generated panel spec** (`panel/bmcv_panel.json`, `panel/panel_layout.h`,
  `panel/bmcv_panel.svg`, `web/panel.json`) built by `just panel` from three
  sources that cannot disagree: `BMCV.kicad_pcb` (board outline, placements and
  body sizes), `netlist.ipc` (WS2812 chain order, jack-to-converter paths), and
  the firmware's own `HwSetup`/`UxSetup` tables via `tools/dump_hw_setup.c`.
  Nothing in the layout is hand-typed - every button, LED, encoder and jack
  position is derived, because each WS2811 is mounted directly behind the
  control it lights, which resolves LED index to physical part by co-location.
- `tools/gen_panel_spec.py`, `tools/dump_hw_setup.c`, `panel/overrides.json`
  (the three facts the CAD data does not carry, listed as `assumptions` in the
  generated spec).
- `tests/test_panel_spec.c`: asserts every `UxSetup` pairing is physically
  co-located, that exactly three buttons have no LED, that no two controls
  share a position, and that everything lands inside the board outline.
  Swapping two entries in any `hw_setup.c` index table fails it.
- **`input_state.c`**: the step between raw hardware and `HwState`, hoisted out
  of `bmcv.c`. Takes a plain `InputSample` (slider, CV levels, latched gate
  edges, button levels, free-running encoder positions) and does the frame ring
  buffer, clock trigger/reset dispatch, slider CV summing, CV scaling, encoder
  deltas and the periodic config autosave. `input_trig_step()` exposes the
  ADC driver's gate hysteresis so a host can reproduce the same edges.
- `tests/test_input_state.c`: 77 checks over paths that previously had none -
  clock dispatch, reset-before-clock ordering, `INPUT_SLIDER` CV summing,
  autosave, encoder int16 wraparound, gate hysteresis.
- **`ChannelEffective`** in `EngineState`: per channel, what it is actually
  doing after the scene crossfade and the parameter maths - frequency in Hz and
  as a ratio of the beat, phase, shape, mod, peak amplitude and DC offset. This
  replaces the ad hoc `cgcd`/`cphsc`/`csphs`/`cfrm`/`cshp`/`cmod` fields, which
  were written every tick and read by nothing. Exposed by
  `bmcv_sim_effective()` and shown in the web frontend's channel table, which
  now reports what the module is doing rather than what was dialled into the
  active scene.
- **`instance.c`**: `BmcvInstance` is one module in one struct - config, signal
  path, interaction state, input layer and the wiring between them.
  `bmcv_instance_init()` is the power-on sequence; `bmcv_instance_tick()` is
  input fold + engine tick. The firmware holds one static instance; a
  simulator or VCV Rack patch holds one per module.
- `tests/test_instance.c`: two instances must not share a clock, error flags,
  input/UI state, preset storage or the LED framebuffer.
- **`sim/`**: the firmware's core behind a flat C API (`sim/include/bmcv_sim.h`)
  that speaks volts, 0..1 slider positions and encoder detents rather than
  converter counts, so a frontend needs none of the firmware's types.
  `bmcv_sim_run()` drives the real `engine_tick`; outputs, the 21 LEDs and an
  8-channel scope ring are readable as flat arrays.
- **`sim/src/sim_rt.c`**: host-side glue shared by every frontend - unit
  conversion, tick decimation and gate latching. Time accumulates in Q32
  microseconds: at 44.1kHz a rounded integer step would run the engine 0.17%
  slow, putting every LFO permanently flat.
- **The simulator's preset store persists across browser sessions.** The
  module autosaves its config to its last slot every couple of seconds; the
  frontend mirrors that blob into `localStorage` on the same cadence and
  restores it on load, so a patch survives a reload. Reset clears both. A blob
  whose length does not match `bmcv_sim_storage_size()` is rejected, and
  anything past that is still validated by `config_validate()` on boot.
- **Input panel rebuilt** as one canvas on a 2x2 grid laid out like the input
  jacks, matching the output scopes, with the controls overlaid on the cells
  rather than wrapped in boxes and labels of their own. Each cell carries a
  vertical fader, the trace of what the engine actually latched, and a pulse
  button; the clock generator sits on input 0's cell as a bpm number field and
  disables that fader while it runs. The fader fills from the centre outward,
  so the bar means "offset from 0V" - a native range input fills from its
  minimum and put a solid bar at -10V. `bmcv_sim_input_scope()` exposes the
  per-input history.
- The panel controls are restyled for the light artwork: dark outlines and
  spokes, a nearly transparent knob fill, lighter switch caps and a stronger,
  wider LED glow, since a wash that read well on a dark mock-up disappeared on
  a silver panel. The slider draws only its handle - the artwork has the slot -
  and the wiper travel (49mm) is now measured off that slot rather than guessed
  from the potentiometer body.
- The encoder cap is sized to the 7.03mm cutout in the panel artwork, leaving a
  hairline of it showing, with a correspondingly larger knob body. Legends are
  bold; the crossfader handle is shorter, its hit area uses a horizontal resize
  cursor, and the switch caps are lighter.
- Button legends are drawn rather than left to the artwork, so they stay correct
  if a button is ever reassigned: the parameter above (FRQ, SHP, ...) and the
  shift mode below (STA, SYS, ...), with CLR/CPY/MUT taking the lower slot
  alone since latching a mode is all they do.
- **The panel is drawn like the parts.** Buttons are round: 6mm for the
  illuminated switches, 7mm for the three unlit tactiles. Only the ctrl
  functions carry a legend and it sits above the button - the scene numbers and
  semitone names are gone, since a 6mm cap has no room and the layout already
  says which is which. Encoders have a smaller body (the cap is unchanged) and
  four spokes rather than one, because a single mark reads as an absolute
  pointer and these are endless relative encoders. Their LED is a ring around
  the body rather than a tint on the face: the WS2812 is behind the encoder, so
  its light spills around opaque plastic rather than through it.
- Output-jack and channel labels dropped, along with the slider's SCENE label.
  Separate **Reset module** (reboot, keep presets) and **Reset FRAM** (wipe
  presets and the browser copy) buttons.
- The input scope's cells are the same size as the output scope's, at the same
  pixel density and the same time per pixel, so a trace means the same thing in
  both. It reads at half the canvas width because it is 2 columns to the output
  scope's 4.
- **The exported panel artwork (`web/bmcv_panel.png`) is the panel background**,
  drawn 1:1 over the 81 x 128.5mm panel rectangle with the live controls on
  top. It lands exactly on the generated geometry, which is a useful check on
  the whole KiCad-derived pipeline. The drawn ctrl legends are gone with it -
  the artwork carries them, and it names the *parameter* (FRQ, SHP, MOD, ...)
  rather than the shift mode. The spec still exposes both as roles, for the
  hover hint and for anyone rendering without the artwork.
- LED edges are soft: each one paints through its own radial gradient rather
  than a flat fill - solid through the middle with the falloff only at the rim,
  rather than a bright point fading linearly all the way out. Done with
  gradients rather than an SVG blur filter because a paint server costs nothing
  to rasterise. Encoder bodies are slightly translucent so the colour bleeds
  through the knob as well as around it.
- The channel parameter table uses `table-layout: fixed` with tabular figures;
  it used to resize its columns on every value change and jitter constantly.
- **`bmcv_sim_cli`**: drives the module from a scripted input timeline
  (`sim/flows/*.txt`) and prints outputs / LEDs / UI state as CSV. Scripts name
  controls by role (`ctrl QNT 1`, `scene 2 1`, `chbtn 0 1`) rather than by
  button index.
- **`sim/flows/`** with `just flows` / `just flows-bless`: golden-file coverage
  of whole interactions - shift-mode entry and exit, mute, clock lock, param
  selection - which unit tests cannot express.
- `tests/test_sim_rt.c`: 125 checks over the shared runtime glue, including
  no-drift-over-ten-minutes at 44.1k and 48k, and a gate shorter than one tick
  still being seen.
- **WebAssembly build** (`just wasm`) of the same `sim/` project via emscripten,
  producing `web/bmcv.js` + `web/bmcv.wasm` (~105KB). The export list lives in
  `sim/CMakeLists.txt` and is explicit: `bmcv_sim` is a static library, so
  anything unnamed is dead-stripped before it can be exported.
- **`web/`**: a browser frontend that builds its whole panel from
  `web/panel.json` - nothing in the JS knows where any control is. Encoders
  turn by dragging the ring or scrolling and push via the centre cap (Shift
  while turning gives press-and-turn); the 21 LEDs are driven from the real
  framebuffer with a gamma lift so they read like WS2812s rather than flat
  fills. An 8-lane scope, scene contribution bars, a live parameter table and
  CV/clock generators fill in what a panel photo cannot show.
- **`web/smoke.mjs`** (`just wasm-check`): headless node check that the module
  loads, that all 26 exports are present, that heap views line up, and that
  driving it through the flat API actually moves the engine - so a broken wasm
  build is caught without opening a browser.

### Changed

- **`bmcv_state_update` is now only peripheral reads** (~25 lines): it fills an
  `InputSample` and hands it to the core. Every `bmcv_*` entry point keeps its
  signature, so `main.c` and the HAL callbacks are untouched.
- **Presets go through a `PresetIo` vtable on `UxState`** rather than direct
  `preset_store`/`preset_load` calls from `scene.c`. The backing store is FRAM
  on the module and will be patch JSON / browser storage off it. A NULL
  `PresetIo` is valid: store is a no-op, load reports "nothing stored".
- `ui_render.c` no longer calls `get_adc` for the MON scene LED - it reads the
  same value from `hw_state->input_state[]`, which makes that path assertable
  and removes the last driver dependency from the render layer.
- `TRIG_THRESH`/`TRIG_THRESH_LOW` moved from `dac_adc.h` to `hw_setup.h`,
  alongside the CV range constants and for the same stated reason: a simulator
  needs them without pulling in a driver header.
- `tests/fakes/fake_drivers.c` is down from five stubs to one (`dacadc_write`).
- **`channel_output_level()` split out of `write_channel_dac()`.** Mute is an
  output-stage gain, not a zeroed `channels_output_level`, so what actually
  leaves the module was only computed inside the function that talks to the
  DAC. Any host reading `channels_output_level[]` directly would show a muted
  channel as live - the simulator did, until this split.
- **The clock is per instance.** `g_clk` is gone; `ClockState` is a field of
  `EngineState` and every `Clock_*` takes a `ClockState*`.
- **Error flags are per instance.** The `error.c` file static is gone;
  `error_flags` is a field of `EngineState` and every `error_*` takes an
  `EngineState*`.
- **`bmcv.c` holds a single `BmcvInstance`** instead of six file statics, and
  `bmcv_init` is now pin setup plus one `bmcv_instance_init` call. Every
  `bmcv_*` entry point keeps its signature.

### Fixed

- **Panel geometry came from the wrong file.** It was read from
  `production/positions.csv`, which is a *pick-and-place centroid* export: for a
  footprint whose pads are not symmetric about its origin the centroid sits to
  one side, and the offset flips sign with the footprint's rotation. The jacks
  are on a uniform 13mm grid but alternate 90/270 degrees, so they came out at
  14.03/11.97mm alternating - visibly wrong. Geometry now comes from the
  footprint placements in `BMCV.kicad_pcb`, which also yields the board outline
  from Edge.Cuts, so the board size and the panel offset are derived instead of
  typed into the overrides.
- **The simulator booted showing scene 6 until the slider was touched.** The
  frontend drew the crossfader at one end but never told the engine, which had
  come up with `slider_raw` at the other. The drawn position is now published at
  startup, and there is one function that moves both.
- **The browser tab could freeze solid on load.** `bmcv_sim_run` took an
  unsigned `n_ticks`, and the frontend computed it from `rAF` timestamp minus
  `performance.now()` without a lower bound. rAF hands a callback the *current
  frame's* start time, which can be earlier than a `performance.now()` sampled
  just before scheduling it, so the first frame sometimes produced a negative
  count - which arrived in C as ~4.29 billion ticks and blocked the main thread
  for good. No JS error, no crash event, just a dead page, and intermittent
  because it depended on frame timing.
  `bmcv_sim_run` now takes signed counts, rejects zero or negative and caps at
  `BMCV_SIM_MAX_TICKS`; the frontend clamps elapsed time at zero. Covered by
  `web/smoke.mjs`. Eight consecutive page loads: 8/8 alive, previously about one
  in three froze.
- **A fresh module no longer boots into an error display.** Finding no stored
  config raised error bit 6, which `render_error` draws by blanking every LED
  and blinking scene 6 until the next interaction - a startup screen announcing
  that nothing is wrong. An unused module having no saved config is its normal
  state, and `config_validate()` has already made the defaults safe to index. A
  slot the user *explicitly* asks for and cannot read still reports (`scene.c`,
  error bit 5).
- **The 2s config autosave is silent.** It flashed the whole scene row green on
  every write, so idling with a knob just moved produced a confirmation nobody
  asked for. Confirmations are for committed actions; background housekeeping
  on a timer is not one. An explicit save still flashes.
- **The slider was drawn vertical with a guessed 45mm travel.** RV13's
  footprint is 73 x 16.8mm with its pads at x = +/-34, so it is *horizontal*
  with roughly 60mm of travel. The generator now reads the footprint extent
  out of `BMCV.kicad_pcb`, so the axis and body size are derived rather than
  assumed and only the wiper stroke remains an override.
- **The web panel's LEDs were invisible.** They were drawn as circles in a
  layer beneath the controls, and the opaque button and knob bodies covered
  them completely. Physically the switch cap *is* the lamp, so each control now
  carries a tint plus a halo, both transparent when the LED is off.
- **LED brightness was calibrated against the wrong ceiling.** `led_fb.c` caps
  at `VAL_MED` (32) and draws base layers at `VAL_LOW` (8); normalising against
  255 left everything the renderer actually draws invisible. Brightness now
  rides on opacity against a `VAL_MED` full scale with a perceptual curve, and
  hue on a fill normalised to full range so a dim red still reads as red.
- An SVG blur filter over a panel-sized group, re-rasterised every animation
  frame, crashed the renderer outright; the glow is a translucent oversized
  shape instead. The scope polyline is decimated to the canvas width and the
  readout table updates at 10Hz rather than 60Hz - it was the largest source of
  DOM churn on the page.
- **The scope was a fixed 1000x440 bitmap stretched to fit**, so it was visibly
  soft on a wide or HiDPI display. Its backing store now tracks the element's
  real size times `devicePixelRatio`, via a `ResizeObserver`.
- **Slider direction.** Scene A anchors at `SLIDER_MAX_VALUE` (`scene.c`) and
  sits on the left of the panel, so the leftmost position has to map to full
  scale, not zero.
- **The scope stops growing past ~1100px** and the side panels move alongside
  it on wide screens rather than the traces stretching forever. Two jacks
  abreast collapses the range inputs in the narrower column, so they go one per
  row there.

### Notes

- **There is no channel-to-jack crossing.** An earlier revision of the
  generator reported one; that was a tracing error, not a hardware or firmware
  fault. The two AD5754Rs are daisy-chained (MCU -> U34 -> U35) behind a single
  shared `DAC_1_SYNC`, so in each 6-byte transfer the *first* command shifts
  all the way through U34 into U35 and the second stays in U34 - even buffer
  indices are U35, odd are U34, the opposite of what `dac_init()`'s ordering
  suggests at a glance. With that corrected, `channel_dac_idx` puts channels
  0-3 on J1-J4 (left block) and 4-7 on J5-J8 (right block), each in the same
  reading order as their encoders. `hw_setup.c` is correct as shipped.
- **The ADC ADDR phase is resolved.** `input_adc_idx = {2,3,0,1}` only reads as
  a sensible panel if the A2/B2 converter slots land in `adc_i[0..1]`, which
  puts inputs 0-3 on J9-J12 in reading order. The other phase would number the
  jacks 2,3,0,1 across the panel, which nothing else on the module does.

## UI layer restructure

Separated the interaction layer from the engine and gave the recurring UI
concepts one implementation each.

### Added

- **MUT shift mode.** Channel button toggles that channel's mute on release.
  Gates the DAC write only, so a muted channel still feeds cross-modulation and
  still works as a trigger source. Ramps over 5ms so it does not click. Renders
  dim purple in every mode. Not persisted - clears on power cycle.
- **Confirmation feedback** (`ui_feedback.c`) for copy, clear, save, load,
  assign and scene A/B - same flash, same timing, colour by action class. Most
  of these previously gave no feedback at all.
- **Semantic palette** in `color_presets.h` plus `HUE_PURPLE`. The renderer
  names meanings, not colours. Brightness capped at `VAL_MED`.
- **Candidate highlighting** driven by the same predicate the dispatcher uses,
  so what blinks and what responds cannot disagree.
- Tests: `test_ui_input`, `test_ui_gestures`, `test_ui_select`,
  `test_ui_feedback`, `test_ui_mode`. The button path had no coverage before.
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

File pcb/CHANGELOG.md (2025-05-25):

# CHANGELOG

## PCB

### V1

- Fix pinout WS2812
- WS2812 data uses a dedicated levelshifter
- Use one interrupt per MCP
- Disconnect sdo from DAC-2 (not needed, ic not going into tri-state, so it was fighting ADC sdo).
- Weaker pulldowns on and small RC filter on ADC inputs to improve stability when floating.
- Small RC filters on DAC outputs.
- Updated TC002 footprint slightly to also be potentially compatible with 228C series LED switches
- Don't control state of DAC_LDAC & DAC_CLR (tied high, ldac only via software, not using CLR)
    - PA8 now menu button 2 (which was previously reset)
    - PA9 now free & broken out
- Switched to differend (smoother) sliding potentiometer
- Added third function button
  - using PB6 (which was previously SLIDER_LED)

### V0

    Initial version

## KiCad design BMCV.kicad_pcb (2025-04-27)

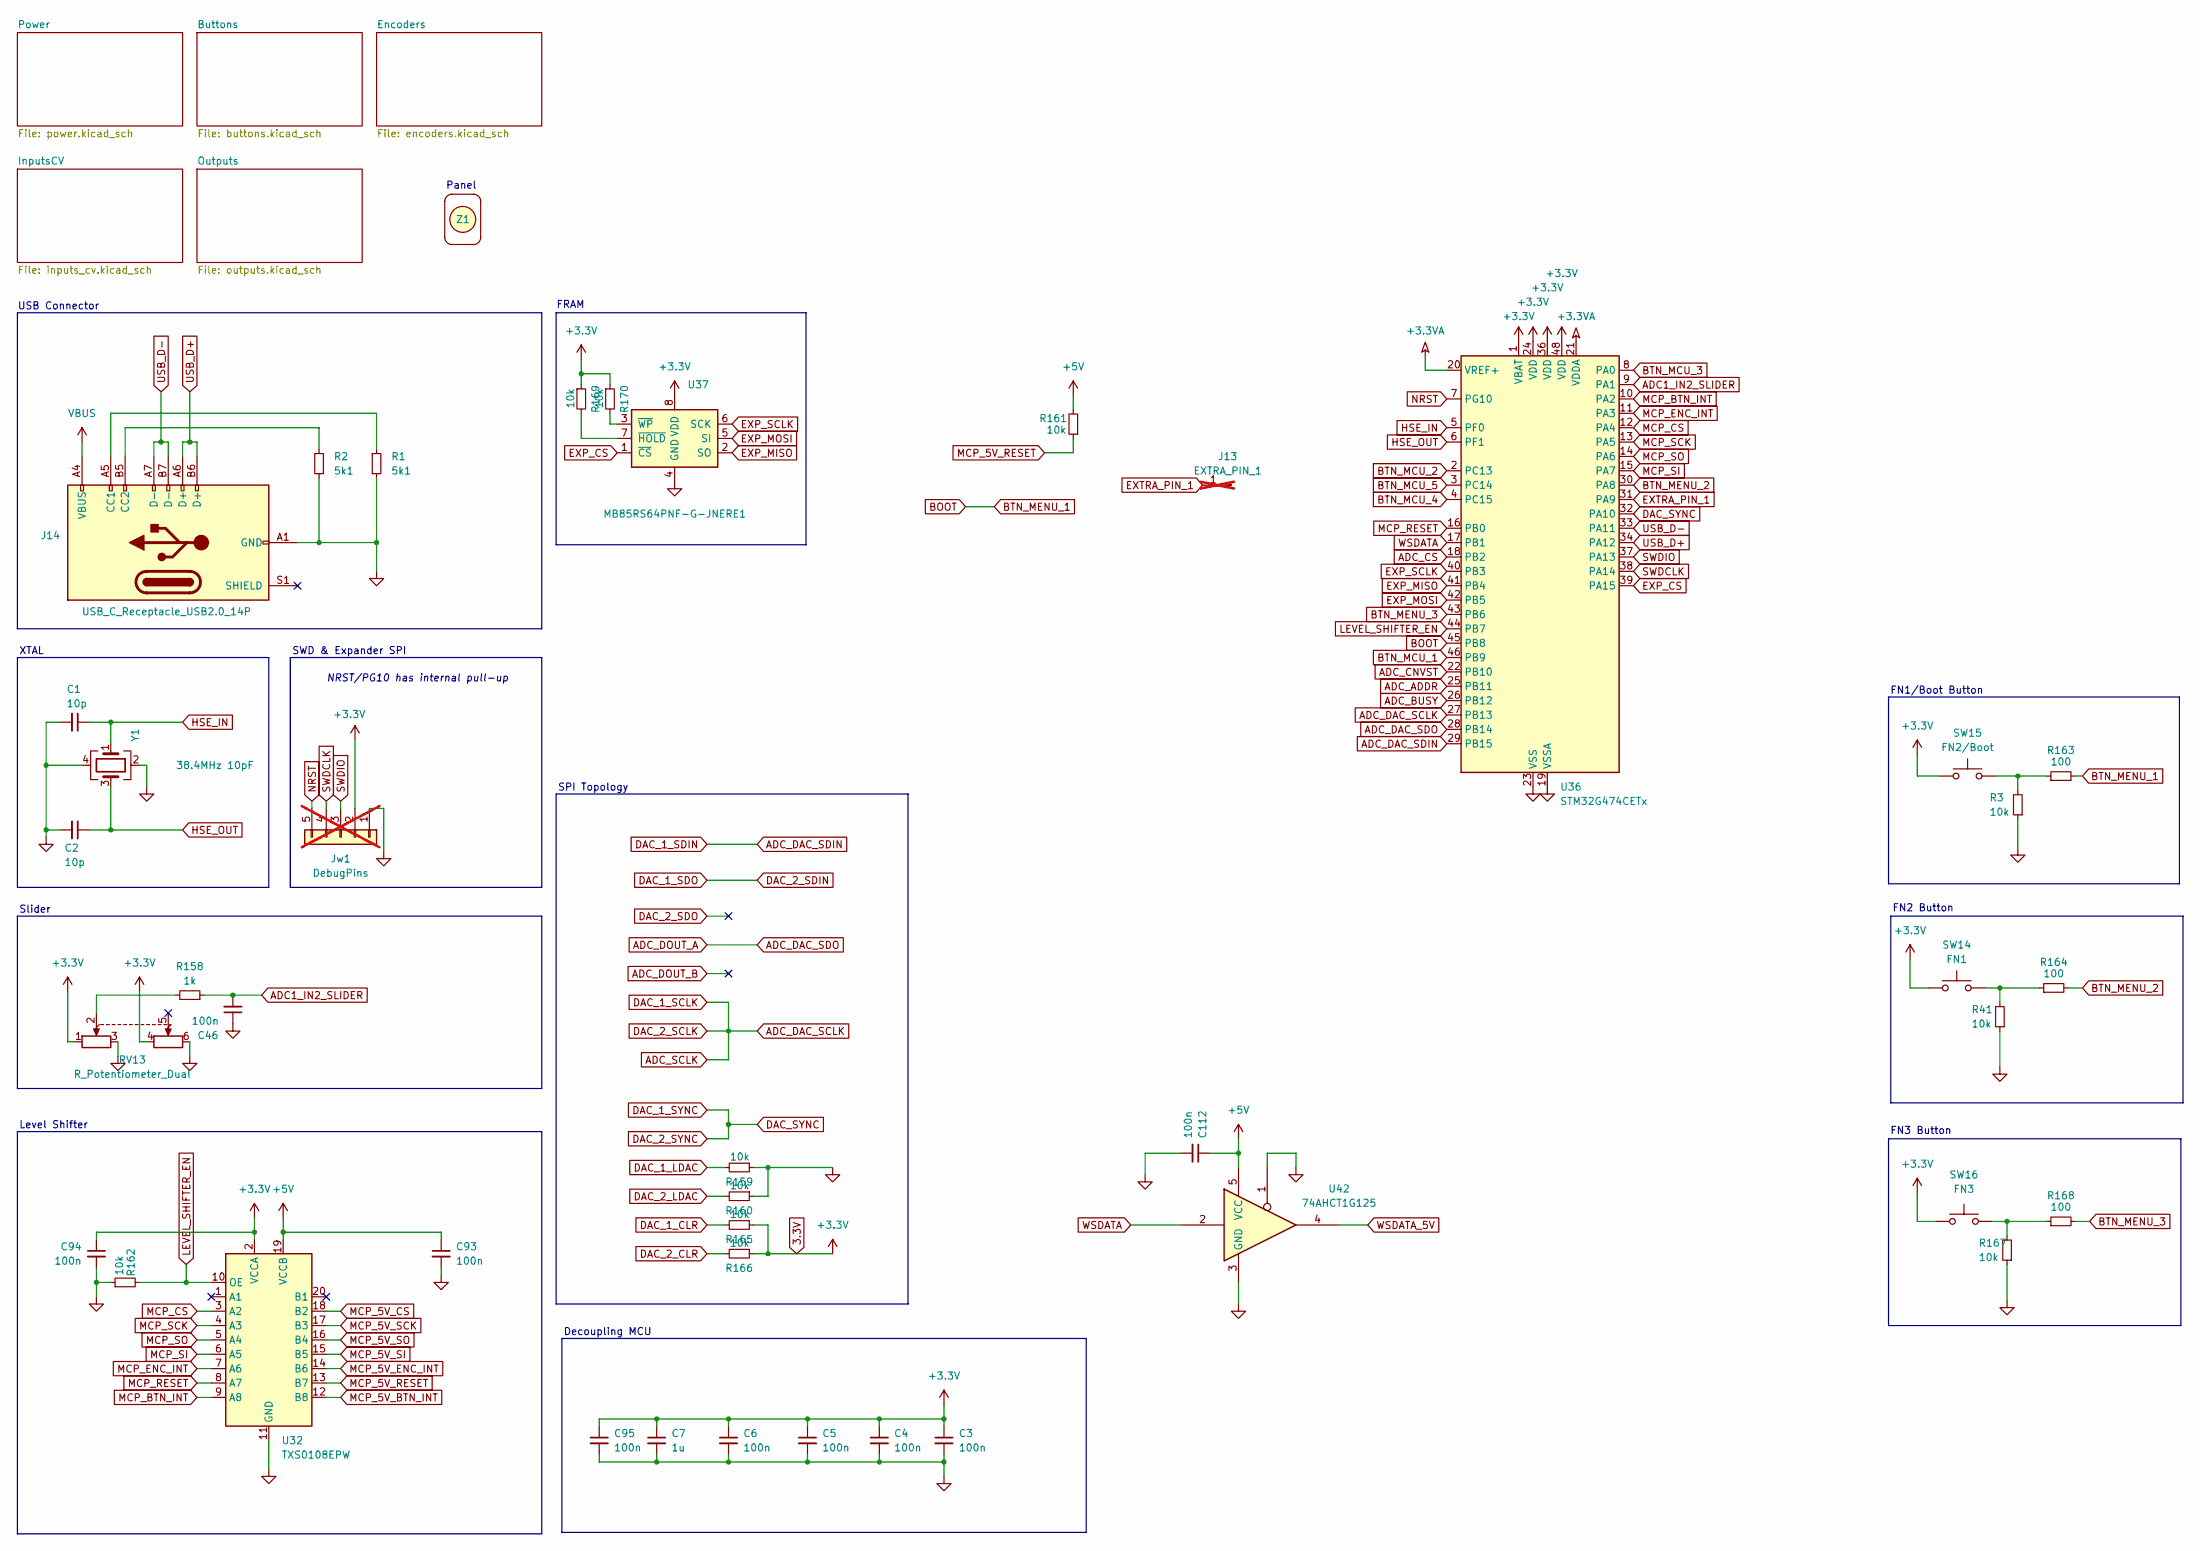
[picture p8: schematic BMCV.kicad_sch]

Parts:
C1, C2: 10p; C_0402_1005Metric; LCSC Part # C161520
C3, C4, C5, C6, C46, C93, C94, C95, C112: 100n; C_0402_1005Metric; LCSC Part # C307331
C7: 1u; C_0603_1608Metric; LCSC Part # C15849
J13: EXTRA_PIN_1; TestPoint_Pad_D1.5mm; not fitted
J14: USB_C_Receptacle_USB2.0_14P; GT-USB-7035E; LCSC Part # C22384784
Jw1: DebugPins; PinSocket_1x05_P2.54mm_Vertical; not fitted
R1, R2: 5k1; R_0402_1005Metric; LCSC Part # C25905
R3, R41, R159, R160, R161, R162, R165, R166, R167, R169, R170: 10k; R_0402_1005Metric; LCSC Part # C25744
R158: 1k; R_0402_1005Metric; LCSC Part # C11702
R163, R164, R168: 100; R_0402_1005Metric; LCSC Part # C25076
RV13: R_Potentiometer_Dual; ALPHA_B10KX2
SW14: FN1; TS-1095PS-AXXBX-C3DX; LCSC Part # C2834959
SW15: FN2/Boot; TS-1095PS-AXXBX-C3DX; LCSC Part # C2834959
SW16: FN3; TS-1095PS-AXXBX-C3DX; LCSC Part # C2834959
U32: TXS0108EPW; TSSOP-20_4.4x6.5mm_P0.65mm; LCSC Part # C17206
U36: STM32G474CETx; LQFP-48_7x7mm_P0.5mm; LCSC Part # C730125
U37: MB85RS64PNF-G-JNERE1; SSOP-8_3.9x5.05mm_P1.27mm; LCSC Part # C8741
U42: 74AHCT1G125; SOT-353_SC-70-5; LCSC Part # C151417
Y1: 38.4MHz 10pF; Crystal_SMD_2520-4Pin_2.5x2.0mm; LCSC Part # C3020671
Z1: BMCVPanel

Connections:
+3.3VA: U36.20 (VREF+), U36.21 (VDDA); also elsewhere on the board
+5V: C93.1, C112.1, R161.2, U32.19 (VCCB), U42.5 (VCC); also elsewhere on the board
ADC1_IN2_SLIDER: C46.2, R158.1, U36.9 (PA1)
ADC_ADDR: U36.25 (PB11); also elsewhere on the board
ADC_BUSY: U36.26 (PB12); also elsewhere on the board
ADC_CNVST: U36.22 (PB10); also elsewhere on the board
ADC_CS: U36.18 (PB2); also elsewhere on the board
ADC_DAC_SCLK: U36.27 (PB13); also elsewhere on the board
ADC_DAC_SDIN: U36.29 (PB15); also elsewhere on the board
ADC_DAC_SDO: U36.28 (PB14); also elsewhere on the board
BOOT: R163.2, U36.45 (PB8)
BTN_MCU_1: U36.46 (PB9); also elsewhere on the board
BTN_MCU_2: U36.2 (PC13); also elsewhere on the board
BTN_MCU_3: U36.8 (PA0); also elsewhere on the board
BTN_MCU_4: U36.4 (PC15); also elsewhere on the board
BTN_MCU_5: U36.3 (PC14); also elsewhere on the board
BTN_MENU_2: R164.2, U36.30 (PA8)
EXP_CS: U36.39 (PA15), U37.1 (~CS)
EXP_MISO: U36.41 (PB4), U37.2 (SO)
EXP_MOSI: U36.42 (PB5), U37.5 (SI)
EXP_SCLK: U36.40 (PB3), U37.6 (SCK)
HSE_IN: C1.1, U36.5 (PF0), Y1.1
HSE_OUT: C2.1, U36.6 (PF1), Y1.3
LEVEL_SHIFTER_EN: R162.2, U32.10 (OE), U36.44 (PB7)
MCP_5V_BTN_INT: U32.12 (B8); also elsewhere on the board
MCP_5V_CS: U32.18 (B2); also elsewhere on the board
MCP_5V_ENC_INT: U32.14 (B6); also elsewhere on the board
MCP_5V_RESET: R161.1, U32.13 (B7); also elsewhere on the board
MCP_5V_SCK: U32.17 (B3); also elsewhere on the board
MCP_5V_SI: U32.15 (B5); also elsewhere on the board
MCP_5V_SO: U32.16 (B4); also elsewhere on the board
MCP_BTN_INT: U32.9 (A8), U36.10 (PA2)
MCP_CS: U32.3 (A2), U36.12 (PA4)
MCP_ENC_INT: U32.7 (A6), U36.11 (PA3)
MCP_RESET: U32.8 (A7), U36.16 (PB0)
MCP_SCK: U32.4 (A3), U36.13 (PA5)
MCP_SI: U32.6 (A5), U36.15 (PA7)
MCP_SO: U32.5 (A4), U36.14 (PA6)
NRST: J13.5, Jw1.5, U36.7 (PG10)
unnamed 84: R41.2, R164.1, SW14.2; also elsewhere on the board
unnamed 85: R3.2, R163.1, SW15.2; also elsewhere on the board
unnamed: J14.A5 (CC1), R1.1
unnamed: J14.B5 (CC2), R2.1
unnamed: R167.2, R168.1, SW16.2
unnamed 288: R158.2, RV13.2; also elsewhere on the board
SLIDER_LED: R168.2, U36.43 (PB6); also elsewhere on the board
SWDCLK: J13.3, Jw1.4, U36.38 (PA14)
SWDIO: J13.2, Jw1.3, U36.37 (PA13)
USB_D+: J14.A6 (D+), J14.B6 (D+), U36.34 (PA12)
USB_D-: J14.A7 (D-), J14.B7 (D-), U36.33 (PA11)
VBUS: J14.A4 (VBUS), J14.A9 (VBUS), J14.B4 (VBUS), J14.B9 (VBUS)
WSDATA: U36.17 (PB1), U42.2
WSDATA_5V: U42.4; also elsewhere on the board

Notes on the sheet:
SPI Topology
NRST/PG10 has internal pull-up
FN1/Boot Button
Slider
Panel
FN2 Button
Level Shifter
Decoupling MCU
USB Connector
XTAL
FN3 Button
SWD & Expander SPI
FRAM

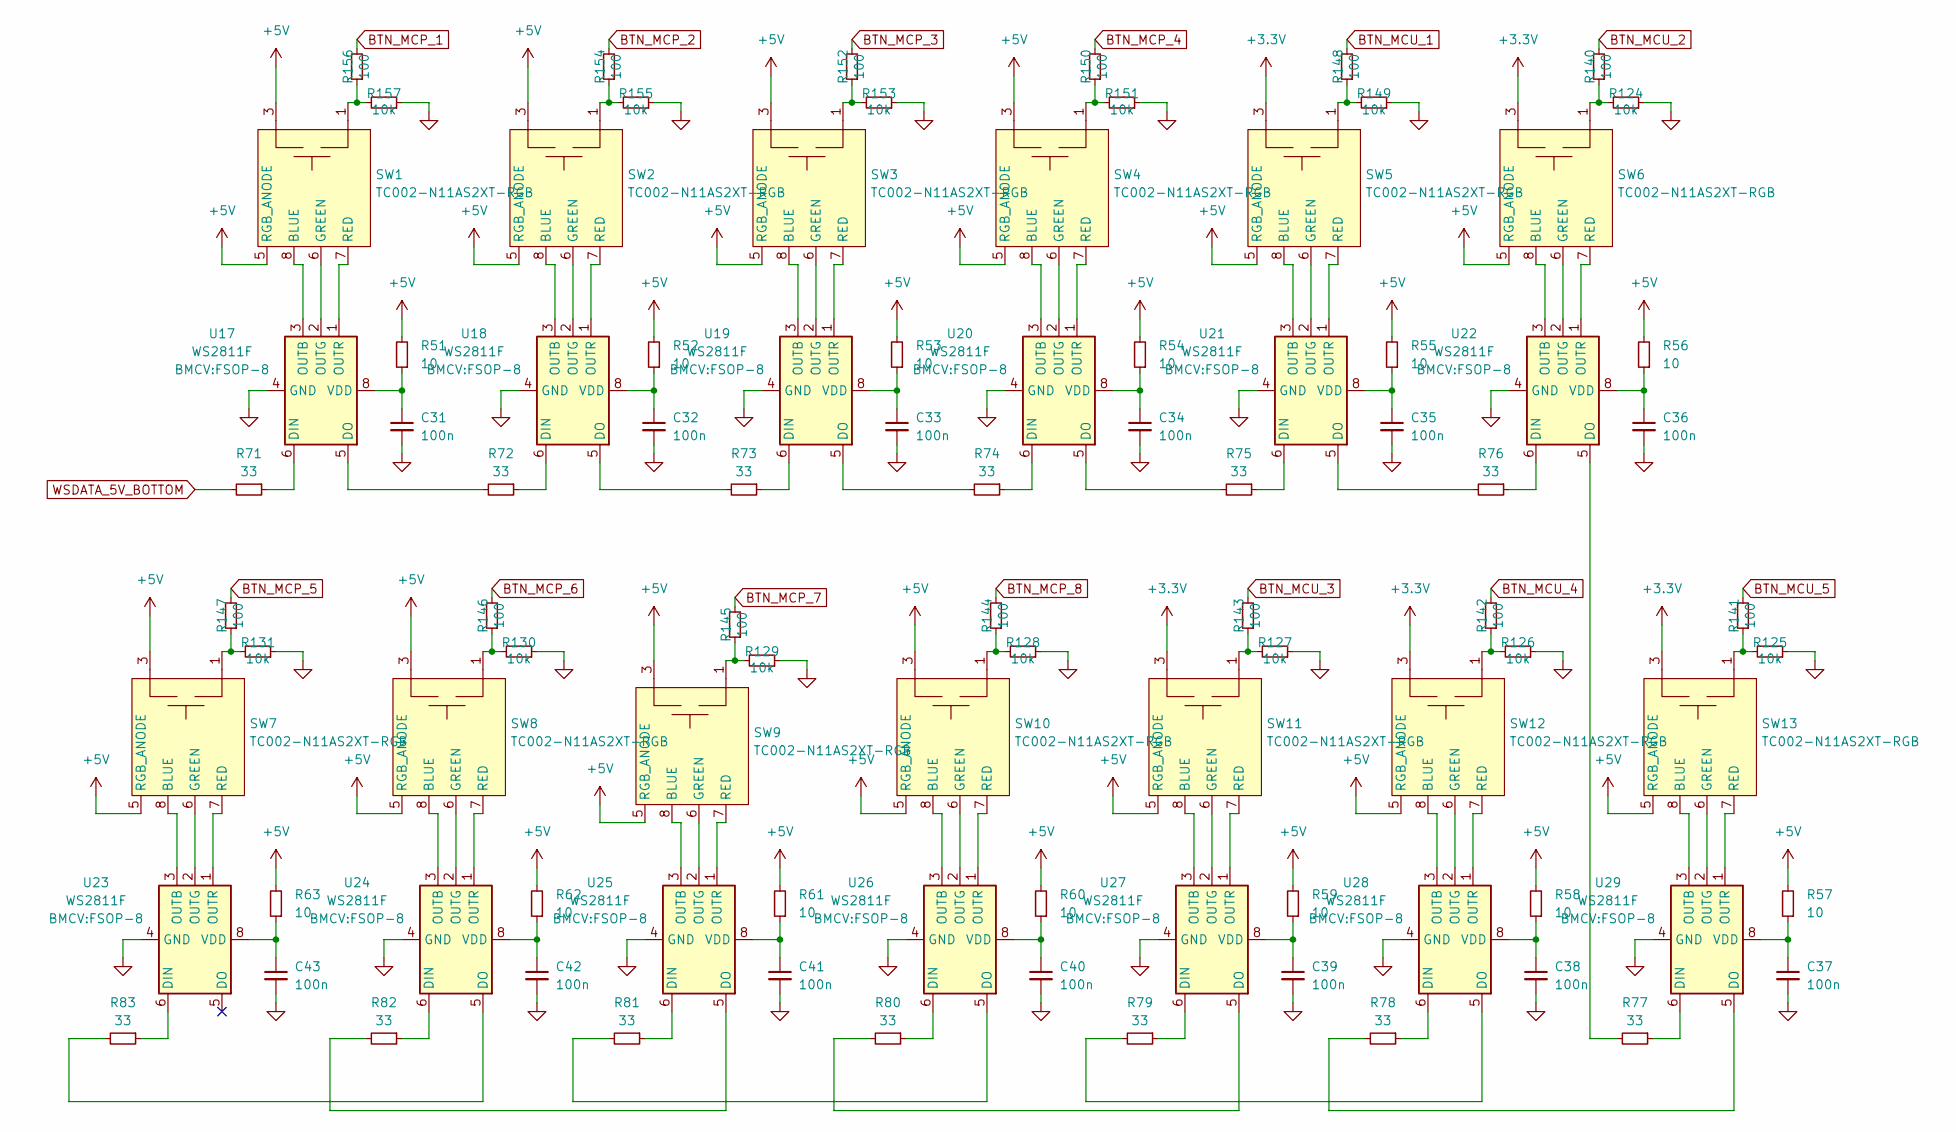
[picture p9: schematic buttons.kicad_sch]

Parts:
C31, C32, C33, C34, C35, C36, C37, C38, C39, C40, C41, C42, C43: 100n; C_0402_1005Metric; LCSC Part # C307331
R51, R52, R53, R54, R55, R56, R57, R58, R59, R60, R61, R62, R63: 10; R_0402_1005Metric; LCSC Part # C25077
R71, R72, R73, R74, R75, R76, R77, R78, R79, R80, R81, R82, R83: 33; R_0402_1005Metric; LCSC Part # C25105
R124, R125, R126, R127, R128, R129, R130, R131, R149, R151, R153, R155, R157: 10k; R_0402_1005Metric; LCSC Part # C25744
R140, R141, R142, R143, R144, R145, R146, R147, R148, R150, R152, R154, R156: 100; R_0402_1005Metric; LCSC Part # C25076
SW1, SW2, SW3, SW4, SW5, SW6, SW7, SW8, SW9, SW10, SW11, SW12, SW13: TC002-N11AS2XT-RGB; TC002-N11AXXX-RGB
U17, U18, U19, U20, U21, U22, U23, U24, U25, U26, U27, U28, U29: WS2811F; FSOP-8; LCSC Part # C5446692

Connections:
+5V: R51.2, R52.2, R53.2, R54.2, R55.2, R56.2, R57.2, R58.2, R59.2, R60.2, R61.2, R62.2, R63.2, SW1.3, SW1.4, SW1.5 (RGB_ANODE), SW2.3, SW2.4, SW2.5 (RGB_ANODE), SW3.3, SW3.4, SW3.5 (RGB_ANODE), SW4.3, SW4.4, SW4.5 (RGB_ANODE), SW5.5 (RGB_ANODE), SW6.5 (RGB_ANODE), SW7.3, SW7.4, SW7.5 (RGB_ANODE), SW8.3, SW8.4, SW8.5 (RGB_ANODE), SW9.3, SW9.4, SW9.5 (RGB_ANODE), SW10.3, SW10.4, SW10.5 (RGB_ANODE), SW11.5 (RGB_ANODE), SW12.5 (RGB_ANODE), SW13.5 (RGB_ANODE); also elsewhere on the board
BTN_MCP_1: R156.2; also elsewhere on the board
BTN_MCP_2: R154.2; also elsewhere on the board
BTN_MCP_3: R152.2; also elsewhere on the board
BTN_MCP_4: R150.2; also elsewhere on the board
BTN_MCP_5: R147.2; also elsewhere on the board
BTN_MCP_6: R146.2; also elsewhere on the board
BTN_MCP_7: R145.2; also elsewhere on the board
BTN_MCP_8: R144.2; also elsewhere on the board
BTN_MCU_1: R148.2; also elsewhere on the board
BTN_MCU_2: R140.2; also elsewhere on the board
BTN_MCU_3: R143.2; also elsewhere on the board
BTN_MCU_4: R142.2; also elsewhere on the board
BTN_MCU_5: R141.2; also elsewhere on the board
unnamed: R124.2, R140.1, SW6.1, SW6.2
unnamed: R125.2, R141.1, SW13.1, SW13.2
unnamed: R126.2, R142.1, SW12.1, SW12.2
unnamed: R127.2, R143.1, SW11.1, SW11.2
unnamed: R128.2, R144.1, SW10.1, SW10.2
unnamed: R129.2, R145.1, SW9.1, SW9.2
unnamed: R130.2, R146.1, SW8.1, SW8.2
unnamed: R131.2, R147.1, SW7.1, SW7.2
unnamed: R148.1, R149.2, SW5.1, SW5.2
unnamed: R150.1, R151.2, SW4.1, SW4.2
unnamed: R152.1, R153.2, SW3.1, SW3.2
unnamed: R154.1, R155.2, SW2.1, SW2.2
unnamed: R156.1, R157.2, SW1.1, SW1.2
unnamed: SW1.8 (BLUE), U17.3 (OUTB)
unnamed: SW1.6 (GREEN), U17.2 (OUTG)
unnamed: SW1.7 (RED), U17.1 (OUTR)
unnamed: SW2.8 (BLUE), U18.3 (OUTB)
unnamed: SW2.6 (GREEN), U18.2 (OUTG)
unnamed: SW2.7 (RED), U18.1 (OUTR)
unnamed: SW3.8 (BLUE), U19.3 (OUTB)
unnamed: SW3.6 (GREEN), U19.2 (OUTG)
unnamed: SW3.7 (RED), U19.1 (OUTR)
unnamed: SW4.8 (BLUE), U20.3 (OUTB)
unnamed: SW4.6 (GREEN), U20.2 (OUTG)
unnamed: SW4.7 (RED), U20.1 (OUTR)
unnamed: SW5.8 (BLUE), U21.3 (OUTB)
unnamed: SW5.6 (GREEN), U21.2 (OUTG)
unnamed: SW5.7 (RED), U21.1 (OUTR)
unnamed: SW6.8 (BLUE), U22.3 (OUTB)
unnamed: SW6.6 (GREEN), U22.2 (OUTG)
unnamed: SW6.7 (RED), U22.1 (OUTR)
unnamed: SW7.8 (BLUE), U23.3 (OUTB)
unnamed: SW7.6 (GREEN), U23.2 (OUTG)
unnamed: SW7.7 (RED), U23.1 (OUTR)
unnamed: SW8.8 (BLUE), U24.3 (OUTB)
unnamed: SW8.6 (GREEN), U24.2 (OUTG)
unnamed: SW8.7 (RED), U24.1 (OUTR)
unnamed: SW9.8 (BLUE), U25.3 (OUTB)
unnamed: SW9.6 (GREEN), U25.2 (OUTG)
unnamed: SW9.7 (RED), U25.1 (OUTR)
unnamed: SW10.8 (BLUE), U26.3 (OUTB)
unnamed: SW10.6 (GREEN), U26.2 (OUTG)
unnamed: SW10.7 (RED), U26.1 (OUTR)
unnamed: SW11.8 (BLUE), U27.3 (OUTB)
unnamed: SW11.6 (GREEN), U27.2 (OUTG)
unnamed: SW11.7 (RED), U27.1 (OUTR)
unnamed: SW12.8 (BLUE), U28.3 (OUTB)
unnamed: SW12.6 (GREEN), U28.2 (OUTG)
unnamed: SW12.7 (RED), U28.1 (OUTR)
unnamed: SW13.8 (BLUE), U29.3 (OUTB)
unnamed: SW13.6 (GREEN), U29.2 (OUTG)
unnamed: SW13.7 (RED), U29.1 (OUTR)
unnamed: R71.1, U17.6 (DIN)
unnamed: R72.2, U17.5 (DO)
unnamed: C31.1, R51.1, U17.8 (VDD)
unnamed: R72.1, U18.6 (DIN)
unnamed: R73.2, U18.5 (DO)
unnamed: C32.1, R52.1, U18.8 (VDD)
unnamed: R73.1, U19.6 (DIN)
unnamed: R74.2, U19.5 (DO)
unnamed: C33.1, R53.1, U19.8 (VDD)
unnamed: R74.1, U20.6 (DIN)
unnamed: R75.2, U20.5 (DO)
unnamed: C34.1, R54.1, U20.8 (VDD)
unnamed: R75.1, U21.6 (DIN)
unnamed: R76.2, U21.5 (DO)
unnamed: C35.1, R55.1, U21.8 (VDD)
unnamed: R76.1, U22.6 (DIN)
unnamed: R77.2, U22.5 (DO)
unnamed: C36.1, R56.1, U22.8 (VDD)
unnamed: R83.1, U23.6 (DIN)
unnamed: C43.1, R63.1, U23.8 (VDD)
unnamed: R82.1, U24.6 (DIN)
unnamed: R83.2, U24.5 (DO)
unnamed: C42.1, R62.1, U24.8 (VDD)
unnamed: R81.1, U25.6 (DIN)
unnamed: R82.2, U25.5 (DO)
unnamed: C41.1, R61.1, U25.8 (VDD)
unnamed: R80.1, U26.6 (DIN)
unnamed: R81.2, U26.5 (DO)
unnamed: C40.1, R60.1, U26.8 (VDD)
unnamed: R79.1, U27.6 (DIN)
unnamed: R80.2, U27.5 (DO)
unnamed: C39.1, R59.1, U27.8 (VDD)
unnamed: R78.1, U28.6 (DIN)
unnamed: R79.2, U28.5 (DO)
unnamed: C38.1, R58.1, U28.8 (VDD)
unnamed: R77.1, U29.6 (DIN)
unnamed: R78.2, U29.5 (DO)
unnamed: C37.1, R57.1, U29.8 (VDD)
WSDATA_5V_BOTTOM: R71.2; also elsewhere on the board

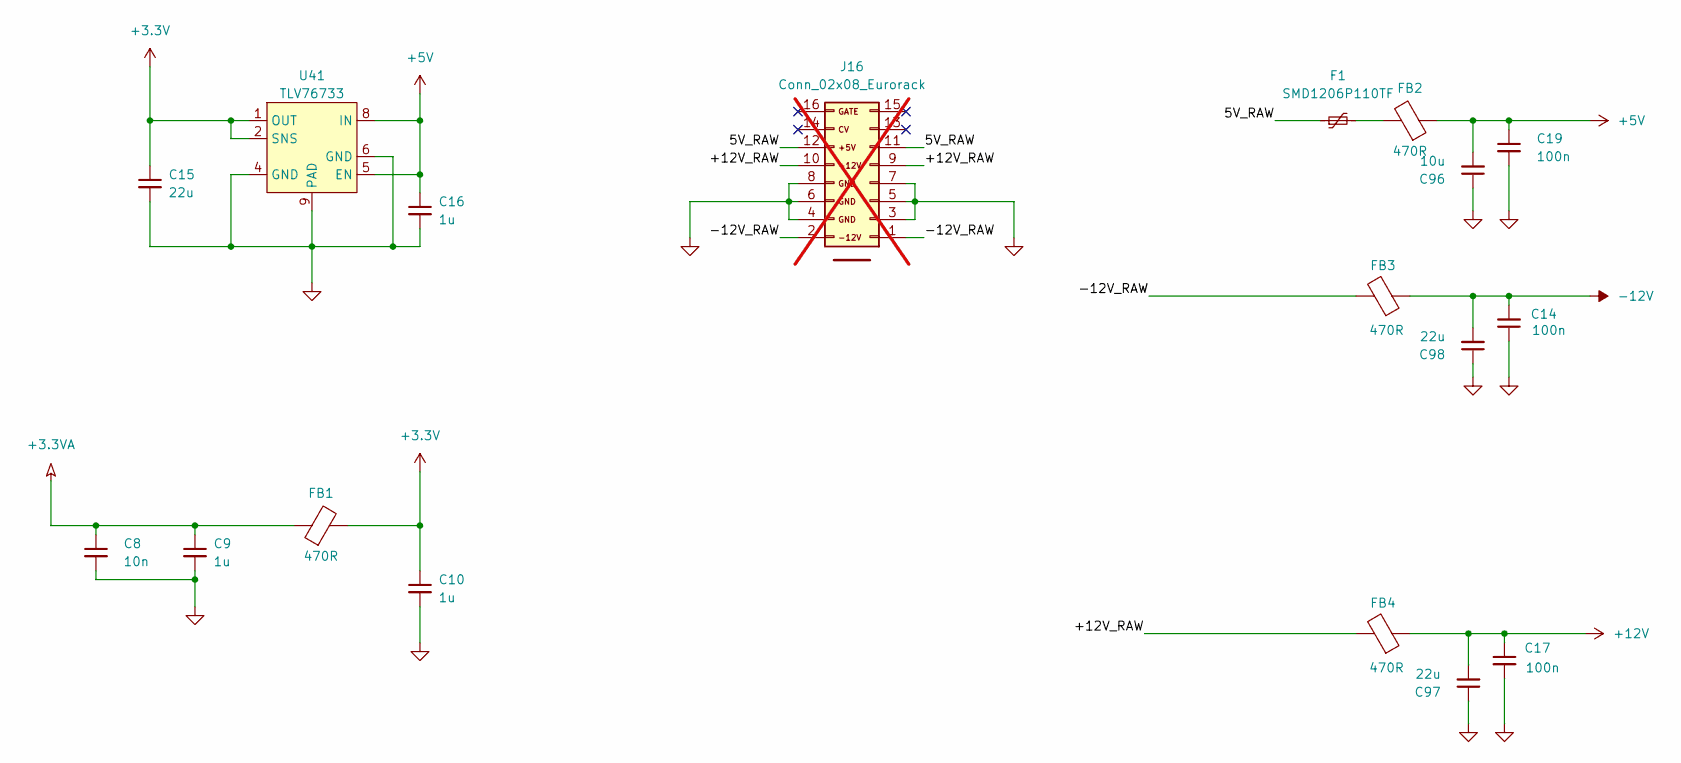
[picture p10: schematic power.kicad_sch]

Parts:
C8: 10n; C_0402_1005Metric; LCSC Part # C15195
C9, C10, C16: 1u; C_0603_1608Metric; LCSC Part # C15849
C14, C17, C19: 100n; C_0603_1608Metric; LCSC Part # C14663
C15, C97, C98: 22u; C_0805_2012Metric; LCSC Part # C45783
C96: 10u; C_0805_2012Metric; LCSC Part # C237493
F1: SMD1206P110TF; Fuse_1206_3216Metric; LCSC Part # C20801
FB1, FB2, FB3, FB4: 470R; L_0603_1608Metric; LCSC Part # C114780
J16: Conn_02x08_Eurorack; Eurorack_Full_IDC_Vertical; LCSC Part # C3406; not fitted
U41: TLV76733; HVSSOP-8-1EP_3x3mm_P0.65mm_EP1.57x1.89mm; LCSC Part # C2873382

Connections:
+3.3VA: C8.1, C9.1, FB1.1; also elsewhere on the board
+5V: C16.1, C19.1, C96.2, FB2.1, U41.5 (EN), U41.8 (IN); also elsewhere on the board
+12V: C17.1, C97.2, FB4.1; also elsewhere on the board
-12V: C14.2, C98.2, FB3.1; also elsewhere on the board
/Power/5V_RAW: F1.1, J16.11, J16.12
/Power/+12V_RAW: FB4.2, J16.9, J16.10
/Power/-12V_RAW: FB3.2, J16.1, J16.2
unnamed: F1.2, FB2.2

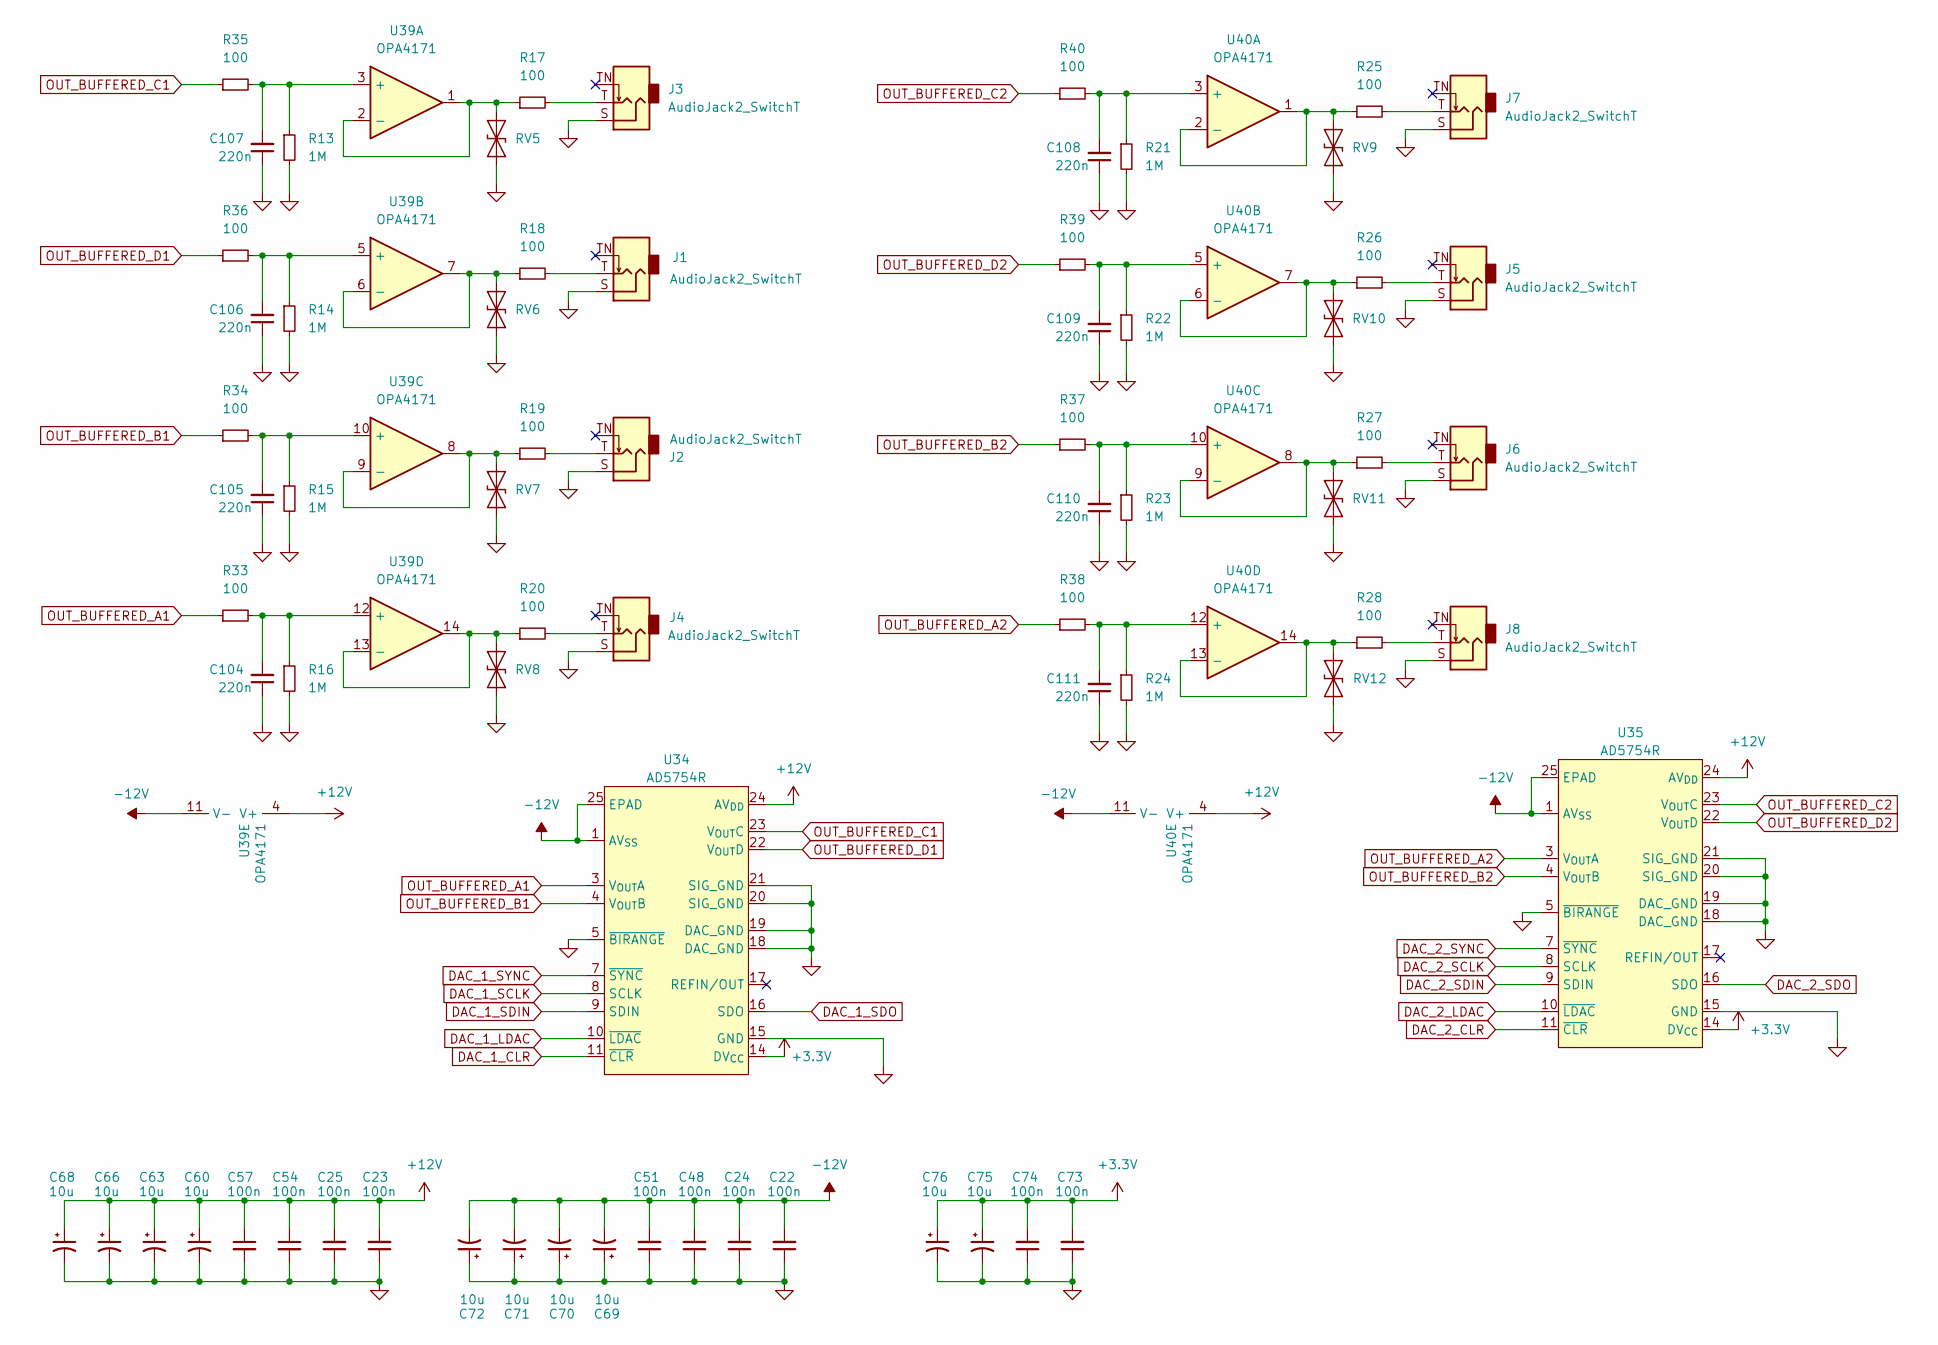
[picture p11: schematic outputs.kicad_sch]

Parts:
C22, C23, C24, C25, C48, C51, C54, C57, C73, C74: 100n; C_0603_1608Metric; LCSC Part # C14663
C60, C63, C66, C68, C69, C70, C71, C72, C75, C76: 10u; C_0805_2012Metric; LCSC Part # C237493
C104, C105, C106, C107, C108, C109, C110, C111: 220n; C_0402_1005Metric; LCSC Part # C16772
J1, J2, J3, J4, J5, J6, J7, J8: AudioJack2_SwitchT; Jack_3.5mm_QingPu_WQP-PJ398SM_Vertical_CircularHoles
R13, R14, R15, R16, R21, R22, R23, R24: 1M; R_0603_1608Metric; LCSC Part # C22935
R17, R18, R19, R20, R25, R26, R27, R28: 100; R_0603_1608Metric; LCSC Part # C22775
R33, R34, R35, R36, R37, R38, R39, R40: 100; R_0402_1005Metric; LCSC Part # C25076
RV5, RV6, RV7, RV8, RV9, RV10, RV11, RV12: SD12C-01FTG; D_SOD-323; LCSC Part # C135970
U34, U35: AD5754R; TSSOP-24-1EP_4.4x7.8mm_P0.65mm_EP3.2x5mm; LCSC Part # C392905
U39, U40: OPA4171; TSSOP-14_4.4x5mm_P0.65mm; LCSC Part # C529553

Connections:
+12V: C23.2, C25.2, C54.1, C57.1, C60.1, C63.1, C66.1, C68.1, U34.24 (AV_{DD}), U35.24 (AV_{DD}), U39.4 (V+), U40.4 (V+); also elsewhere on the board
-12V: C22.2, C24.2, C48.2, C51.2, C69.2, C70.2, C71.2, C72.2, U34.1 (AV_{SS}), U34.25 (EPAD), U35.1 (AV_{SS}), U35.25 (EPAD), U39.11 (V-), U40.11 (V-); also elsewhere on the board
ADC_DAC_SCLK: U34.8 (SCLK), U35.8 (SCLK); also elsewhere on the board
ADC_DAC_SDIN: U34.9 (SDIN); also elsewhere on the board
DAC_2_SDO: U35.16 (SDO)
unnamed: J1.T, R18.2
unnamed: J2.T, R19.2
unnamed: J3.T, R17.2
unnamed: J4.T, R20.2
unnamed: J5.T, R26.2
unnamed: J6.T, R27.2
unnamed: J7.T, R25.2
unnamed: J8.T, R28.2
unnamed: R17.1, RV5.2 (A2), U39.1, U39.2 (-)
unnamed: R18.1, RV6.2 (A2), U39.6 (-), U39.7
unnamed: R19.1, RV7.2 (A2), U39.8, U39.9 (-)
unnamed: R20.1, RV8.2 (A2), U39.13 (-), U39.14
unnamed: R25.1, RV9.2 (A2), U40.1, U40.2 (-)
unnamed: R26.1, RV10.2 (A2), U40.6 (-), U40.7
unnamed: R27.1, RV11.2 (A2), U40.8, U40.9 (-)
unnamed: R28.1, RV12.2 (A2), U40.13 (-), U40.14
unnamed: C107.2, R13.1, R35.2, U39.3 (+)
unnamed: C106.2, R14.1, R36.2, U39.5 (+)
unnamed: C105.2, R15.1, R34.2, U39.10 (+)
unnamed: C104.2, R16.1, R33.2, U39.12 (+)
unnamed: C108.2, R21.1, R40.2, U40.3 (+)
unnamed: C109.2, R22.1, R39.2, U40.5 (+)
unnamed: C110.2, R23.1, R37.2, U40.10 (+)
unnamed: C111.2, R24.1, R38.2, U40.12 (+)
OUT_BUFFERED_A1: R33.1, U34.3 (V_{OUT}A)
OUT_BUFFERED_A2: R38.1, U35.3 (V_{OUT}A)
OUT_BUFFERED_B1: R34.1, U34.4 (V_{OUT}B)
OUT_BUFFERED_B2: R37.1, U35.4 (V_{OUT}B)
OUT_BUFFERED_C1: R35.1, U34.23 (V_{OUT}C)
OUT_BUFFERED_C2: R40.1, U35.23 (V_{OUT}C)
OUT_BUFFERED_D1: R36.1, U34.22 (V_{OUT}D)
OUT_BUFFERED_D2: R39.1, U35.22 (V_{OUT}D)

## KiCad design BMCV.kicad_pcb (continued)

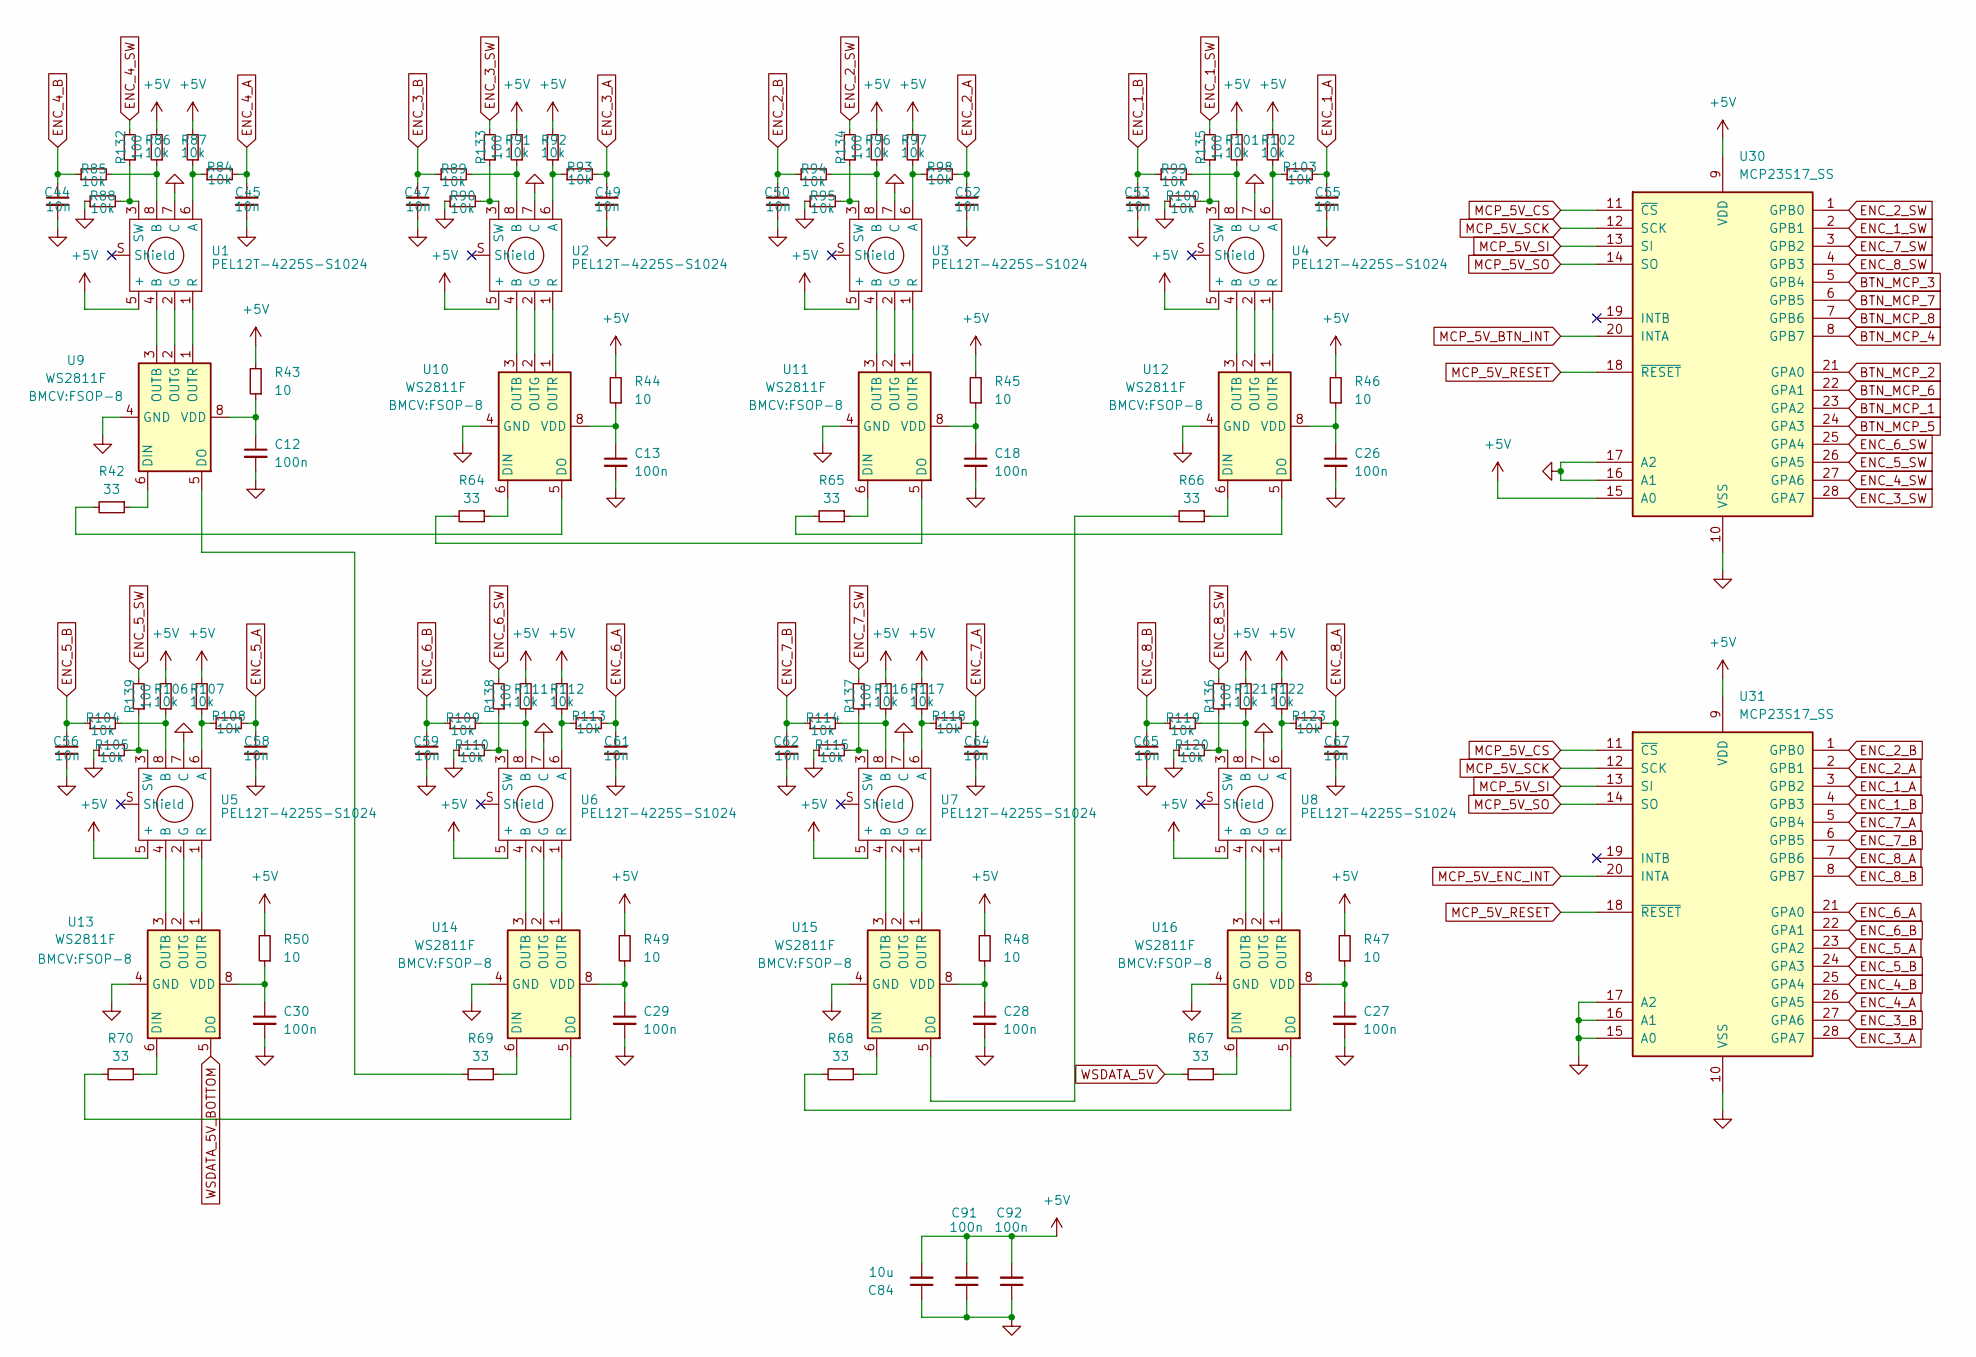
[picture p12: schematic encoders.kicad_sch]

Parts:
C12, C13, C18, C26, C27, C28, C29, C30: 100n; C_0402_1005Metric; LCSC Part # C307331
C44, C45, C47, C49, C50, C52, C53, C55, C56, C58, C59, C61, C62, C64, C65, C67: 10n; C_0402_1005Metric; LCSC Part # C15195
C84: 10u; C_0805_2012Metric; LCSC Part # C237493
C91, C92: 100n; C_0603_1608Metric; LCSC Part # C14663
R42, R64, R65, R66, R67, R68, R69, R70: 33; R_0402_1005Metric; LCSC Part # C25105
R43, R44, R45, R46, R47, R48, R49, R50: 10; R_0402_1005Metric; LCSC Part # C25077
R84, R85, R86, R87, R88, R89, R90, R91, R92, R93, R94, R95, R96, R97, R98, R99, R100, R101, R102, R103, R104, R105, R106, R107, R108, R109, R110, R111, R112, R113, R114, R115, R116, R117, R118, R119, R120, R121, R122, R123: 10k; R_0402_1005Metric; LCSC Part # C25744
R132, R133, R134, R135, R136, R137, R138, R139: 100; R_0402_1005Metric; LCSC Part # C25076
U1, U2, U3, U4, U5, U6, U7, U8: PEL12T-4225S-S1024; PEL12T-4xxxS-S1024
U9, U10, U11, U12, U13, U14, U15, U16: WS2811F; FSOP-8; LCSC Part # C5446692
U30, U31: MCP23S17_SS; SSOP-28_5.3x10.2mm_P0.65mm; LCSC Part # C128577

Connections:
+5V: C84.2, C91.2, C92.2, R43.2, R44.2, R45.2, R46.2, R47.2, R48.2, R49.2, R50.2, R86.2, R87.2, R91.2, R92.2, R96.2, R97.2, R101.2, R102.2, R106.2, R107.2, R111.2, R112.2, R116.2, R117.2, R121.2, R122.2, U1.5 (+), U2.5 (+), U3.5 (+), U4.5 (+), U5.5 (+), U6.5 (+), U7.5 (+), U8.5 (+), U30.9 (VDD), U30.15 (A0), U31.9 (VDD); also elsewhere on the board
BTN_MCP_1: U30.23 (GPA2); also elsewhere on the board
BTN_MCP_2: U30.21 (GPA0); also elsewhere on the board
BTN_MCP_3: U30.5 (GPB4); also elsewhere on the board
BTN_MCP_4: U30.8 (GPB7); also elsewhere on the board
BTN_MCP_5: U30.24 (GPA3); also elsewhere on the board
BTN_MCP_6: U30.22 (GPA1); also elsewhere on the board
BTN_MCP_7: U30.6 (GPB5); also elsewhere on the board
BTN_MCP_8: U30.7 (GPB6); also elsewhere on the board
ENC_1_A: C55.1, R103.2, U31.3 (GPB2)
ENC_1_B: C53.1, R99.1, U31.4 (GPB3)
ENC_1_SW: R135.2, U30.2 (GPB1)
ENC_2_A: C52.1, R98.2, U31.2 (GPB1)
ENC_2_B: C50.1, R94.1, U31.1 (GPB0)
ENC_2_SW: R134.2, U30.1 (GPB0)
ENC_3_A: C49.1, R93.2, U31.28 (GPA7)
ENC_3_B: C47.1, R89.1, U31.27 (GPA6)
ENC_3_SW: R133.2, U30.28 (GPA7)
ENC_4_A: C45.1, R84.2, U31.26 (GPA5)
ENC_4_B: C44.1, R85.1, U31.25 (GPA4)
ENC_4_SW: R132.2, U30.27 (GPA6)
ENC_5_A: C58.1, R108.2, U31.23 (GPA2)
ENC_5_B: C56.1, R104.1, U31.24 (GPA3)
ENC_5_SW: R139.2, U30.26 (GPA5)
ENC_6_A: C61.1, R113.2, U31.21 (GPA0)
ENC_6_B: C59.1, R109.1, U31.22 (GPA1)
ENC_6_SW: R138.2, U30.25 (GPA4)
ENC_7_A: C64.1, R118.2, U31.5 (GPB4)
ENC_7_B: C62.1, R114.1, U31.6 (GPB5)
ENC_7_SW: R137.2, U30.3 (GPB2)
ENC_8_A: C67.1, R123.2, U31.7 (GPB6)
ENC_8_B: C65.1, R119.1, U31.8 (GPB7)
ENC_8_SW: R136.2, U30.4 (GPB3)
MCP_5V_BTN_INT: U30.20 (INTA); also elsewhere on the board
MCP_5V_CS: U30.11 (~CS), U31.11 (~CS); also elsewhere on the board
MCP_5V_ENC_INT: U31.20 (INTA); also elsewhere on the board
MCP_5V_RESET: U30.18 (~RESET), U31.18 (~RESET); also elsewhere on the board
MCP_5V_SCK: U30.12 (SCK), U31.12 (SCK); also elsewhere on the board
MCP_5V_SI: U30.13 (SI), U31.13 (SI); also elsewhere on the board
MCP_5V_SO: U30.14 (SO), U31.14 (SO); also elsewhere on the board
unnamed: R85.2, R86.1, U1.8 (B)
unnamed: R89.2, R91.1, U2.8 (B)
unnamed: R94.2, R96.1, U3.8 (B)
unnamed: R99.2, R101.1, U4.8 (B)
unnamed: R104.2, R106.1, U5.8 (B)
unnamed: R109.2, R111.1, U6.8 (B)
unnamed: R114.2, R116.1, U7.8 (B)
unnamed: R119.2, R121.1, U8.8 (B)
unnamed: R84.1, R87.1, U1.6 (A)
unnamed: U1.2 (G), U9.2 (OUTG)
unnamed: U1.1 (R), U9.1 (OUTR)
unnamed: R88.2, R132.1, U1.3 (SW)
unnamed: R92.1, R93.1, U2.6 (A)
unnamed: R90.2, R133.1, U2.3 (SW)
unnamed: R97.1, R98.1, U3.6 (A)
unnamed: R95.2, R134.1, U3.3 (SW)
unnamed: R102.1, R103.1, U4.6 (A)
unnamed: R100.2, R135.1, U4.3 (SW)
unnamed: R107.1, R108.1, U5.6 (A)
unnamed: R105.2, R139.1, U5.3 (SW)
unnamed: R112.1, R113.1, U6.6 (A)
unnamed: R110.2, R138.1, U6.3 (SW)
unnamed: R117.1, R118.1, U7.6 (A)
unnamed: R115.2, R137.1, U7.3 (SW)
unnamed: R122.1, R123.1, U8.6 (A)
unnamed: R120.2, R136.1, U8.3 (SW)
unnamed: R42.1, U9.6 (DIN)
unnamed: R69.2, U9.5 (DO)
unnamed: U1.4 (B), U9.3 (OUTB)
unnamed: C12.1, R43.1, U9.8 (VDD)
unnamed: R64.1, U10.6 (DIN)
unnamed: R42.2, U10.5 (DO)
unnamed: U2.4 (B), U10.3 (OUTB)
unnamed: U2.2 (G), U10.2 (OUTG)
unnamed: U2.1 (R), U10.1 (OUTR)
unnamed: C13.1, R44.1, U10.8 (VDD)
unnamed: R65.1, U11.6 (DIN)
unnamed: R64.2, U11.5 (DO)
unnamed: U3.4 (B), U11.3 (OUTB)
unnamed: U3.2 (G), U11.2 (OUTG)
unnamed: U3.1 (R), U11.1 (OUTR)
unnamed: C18.1, R45.1, U11.8 (VDD)
unnamed: R66.1, U12.6 (DIN)
unnamed: R65.2, U12.5 (DO)
unnamed: U4.4 (B), U12.3 (OUTB)
unnamed: U4.2 (G), U12.2 (OUTG)
unnamed: U4.1 (R), U12.1 (OUTR)
unnamed: C26.1, R46.1, U12.8 (VDD)
unnamed: R70.1, U13.6 (DIN)
unnamed: U5.4 (B), U13.3 (OUTB)
unnamed: U5.2 (G), U13.2 (OUTG)
unnamed: U5.1 (R), U13.1 (OUTR)
unnamed: C30.1, R50.1, U13.8 (VDD)
unnamed: R69.1, U14.6 (DIN)
unnamed: R70.2, U14.5 (DO)
unnamed: U6.4 (B), U14.3 (OUTB)
unnamed: U6.2 (G), U14.2 (OUTG)
unnamed: U6.1 (R), U14.1 (OUTR)
unnamed: C29.1, R49.1, U14.8 (VDD)
unnamed: R68.1, U15.6 (DIN)
unnamed: R66.2, U15.5 (DO)
unnamed: U7.4 (B), U15.3 (OUTB)
unnamed: U7.2 (G), U15.2 (OUTG)
unnamed: U7.1 (R), U15.1 (OUTR)
unnamed: C28.1, R48.1, U15.8 (VDD)
unnamed: R67.1, U16.6 (DIN)
unnamed: R68.2, U16.5 (DO)
unnamed: U8.4 (B), U16.3 (OUTB)
unnamed: U8.2 (G), U16.2 (OUTG)
unnamed: U8.1 (R), U16.1 (OUTR)
unnamed: C27.1, R47.1, U16.8 (VDD)
WSDATA_5V: R67.2; also elsewhere on the board
WSDATA_5V_BOTTOM: U13.5 (DO); also elsewhere on the board

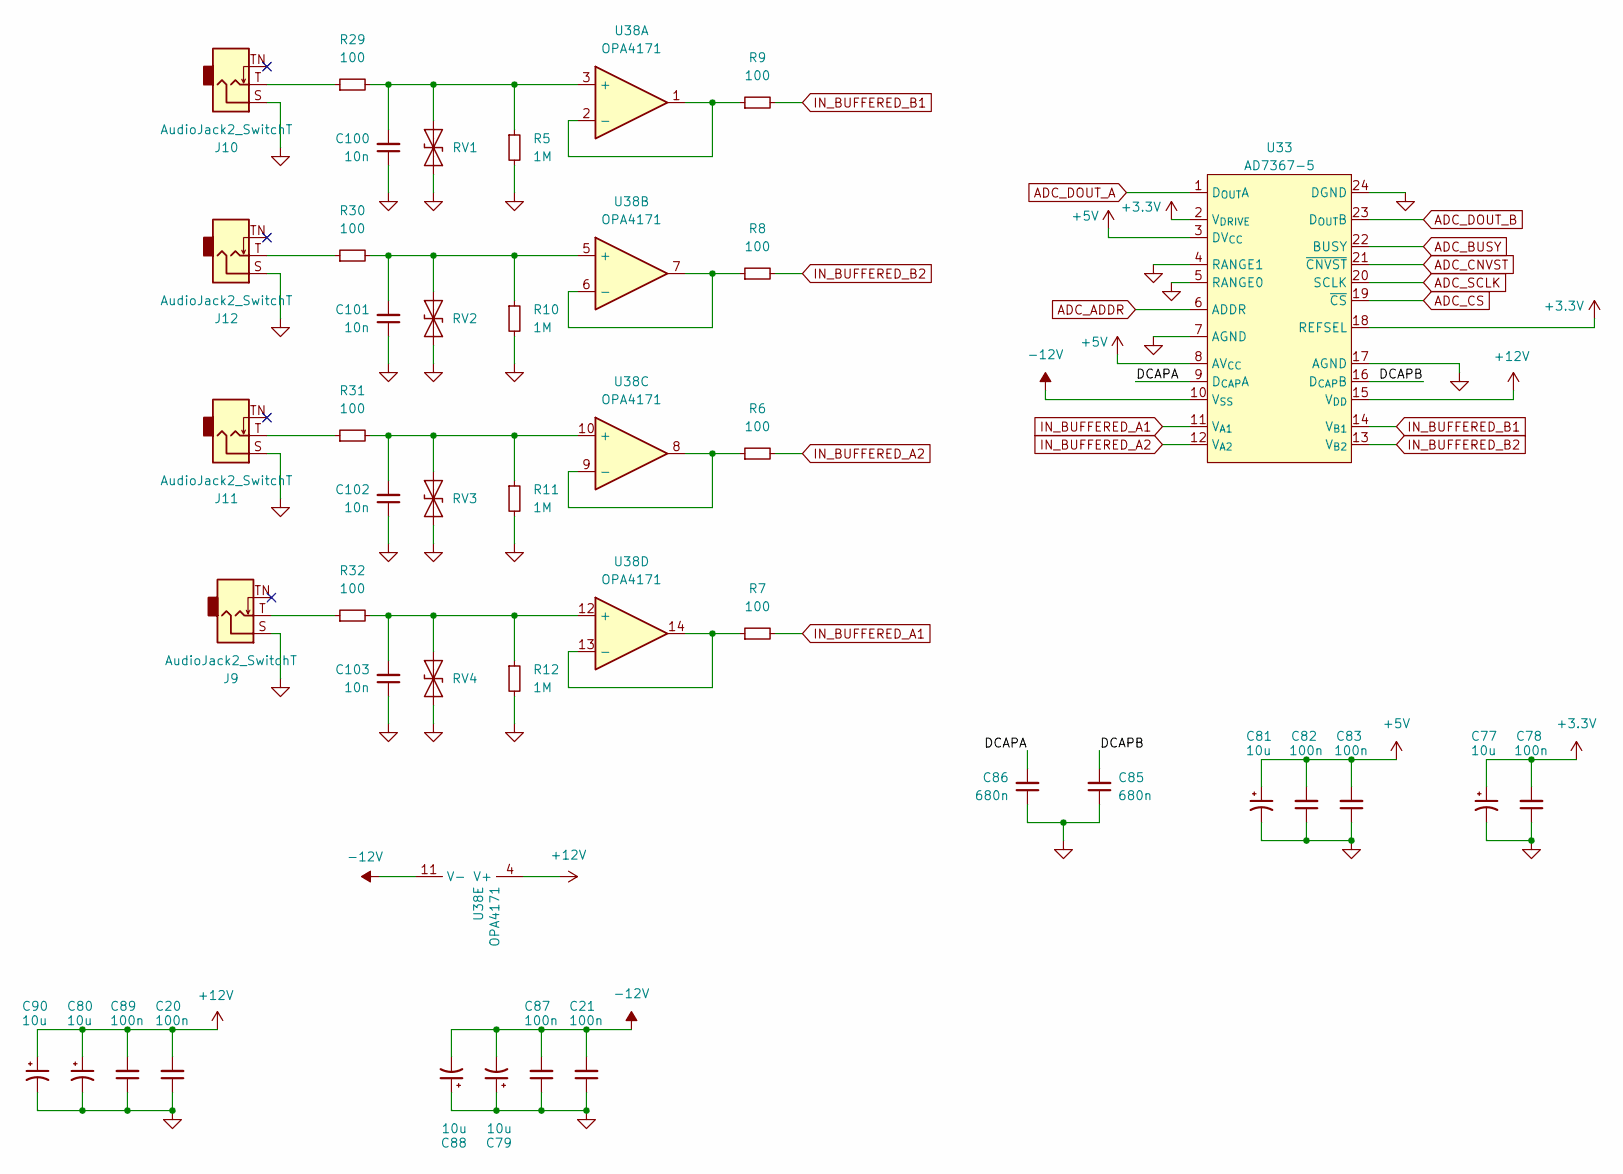
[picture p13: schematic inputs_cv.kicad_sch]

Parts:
C20, C21, C87, C89: 100n; C_0603_1608Metric; LCSC Part # C14663
C77, C79, C80, C81, C88, C90: 10u; C_0805_2012Metric; LCSC Part # C237493
C78, C82, C83: 100n; C_0402_1005Metric; LCSC Part # C307331
C85, C86: 680n; C_0603_1608Metric; LCSC Part # C5143539
C100, C101, C102, C103: 10n; C_0402_1005Metric; LCSC Part # C15195
J9, J10, J11, J12: AudioJack2_SwitchT; Jack_3.5mm_QingPu_WQP-PJ398SM_Vertical_CircularHoles
R5, R10, R11, R12: 1M; R_0603_1608Metric; LCSC Part # C22935
R6, R7, R8, R9: 100; R_0402_1005Metric; LCSC Part # C25076
R29, R30, R31, R32: 100; R_0603_1608Metric; LCSC Part # C22775
RV1, RV2, RV3, RV4: SD12C-01FTG; D_SOD-323; LCSC Part # C135970
U33: AD7367-5; TSSOP-24_4.4x7.8mm_P0.65mm; LCSC Part # C650862
U38: OPA4171; TSSOP-14_4.4x5mm_P0.65mm; LCSC Part # C529553

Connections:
+5V: C81.1, C82.2, C83.2, U33.3 (DV_{CC}), U33.8 (AV_{CC}); also elsewhere on the board
+12V: C20.2, C80.1, C89.2, C90.1, U33.15 (V_{DD}), U38.4 (V+); also elsewhere on the board
-12V: C21.2, C79.2, C87.2, C88.2, U33.10 (V_{SS}), U38.11 (V-); also elsewhere on the board
/InputsCV/DCAPA: C86.2, U33.9 (D_{CAP}A)
/InputsCV/DCAPB: C85.2, U33.16 (D_{CAP}B)
ADC_ADDR: U33.6 (ADDR); also elsewhere on the board
ADC_BUSY: U33.22 (BUSY); also elsewhere on the board
ADC_CNVST: U33.21 (~CNVST); also elsewhere on the board
ADC_CS: U33.19 (~CS); also elsewhere on the board
ADC_DAC_SCLK: U33.20 (SCLK); also elsewhere on the board
ADC_DAC_SDO: U33.1 (D_{OUT}A); also elsewhere on the board
ADC_DOUT_B: U33.23 (D_{OUT}B)
IN_BUFFERED_A1: R7.2, U33.11 (V_{A1})
IN_BUFFERED_A2: R6.2, U33.12 (V_{A2})
IN_BUFFERED_B1: R9.2, U33.14 (V_{B1})
IN_BUFFERED_B2: R8.2, U33.13 (V_{B2})
unnamed: J9.T, R32.1
unnamed: J10.T, R29.1
unnamed: J11.T, R31.1
unnamed: J12.T, R30.1
unnamed: C100.2, R5.1, R29.2, RV1.2 (A2), U38.3 (+)
unnamed: C101.2, R10.1, R30.2, RV2.2 (A2), U38.5 (+)
unnamed: C102.2, R11.1, R31.2, RV3.2 (A2), U38.10 (+)
unnamed: C103.2, R12.1, R32.2, RV4.2 (A2), U38.12 (+)
unnamed: R9.1, U38.1, U38.2 (-)
unnamed: R8.1, U38.6 (-), U38.7
unnamed: R6.1, U38.8, U38.9 (-)
unnamed: R7.1, U38.13 (-), U38.14

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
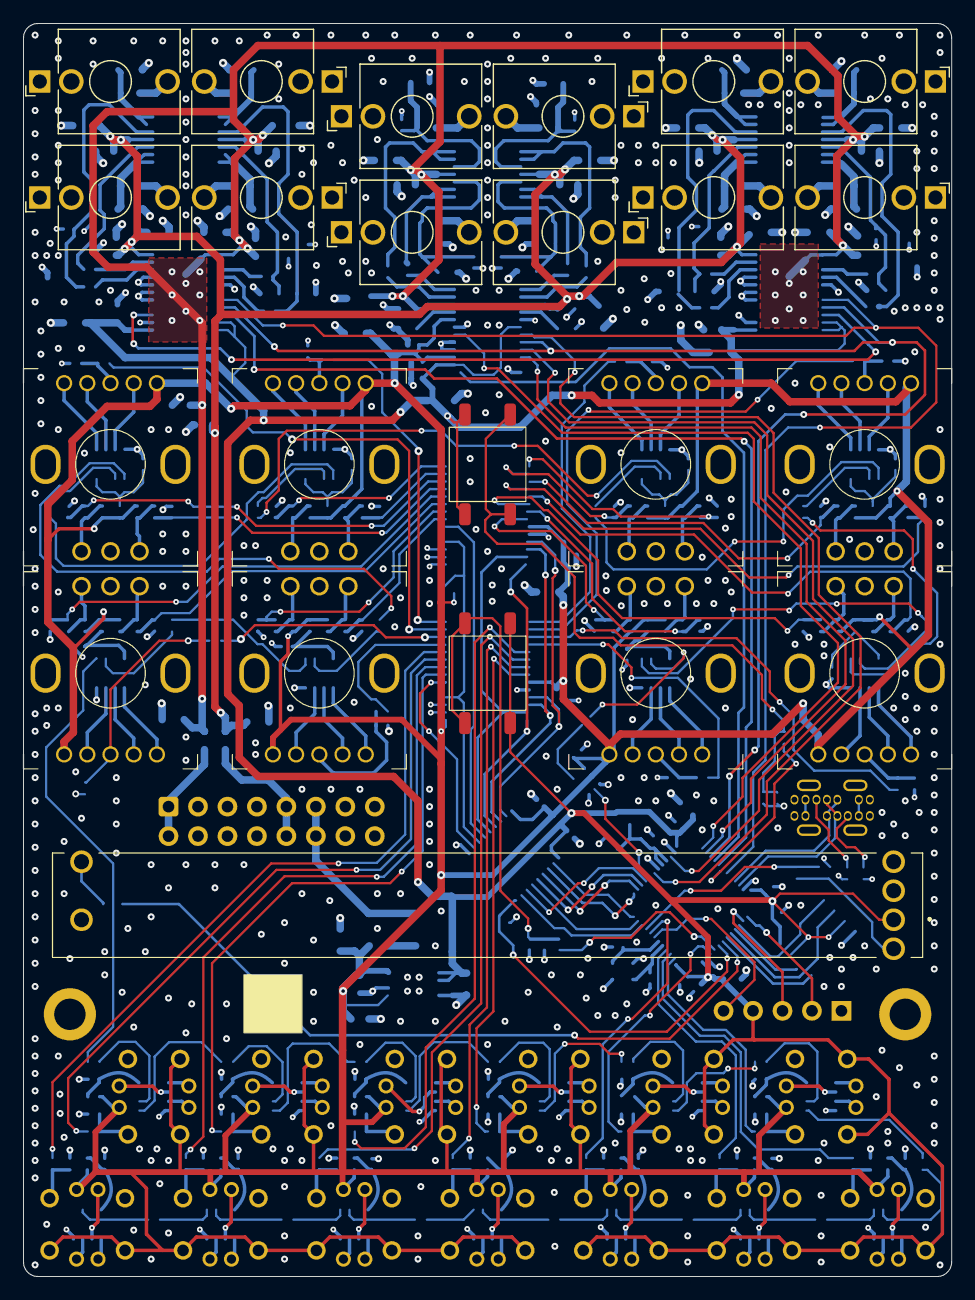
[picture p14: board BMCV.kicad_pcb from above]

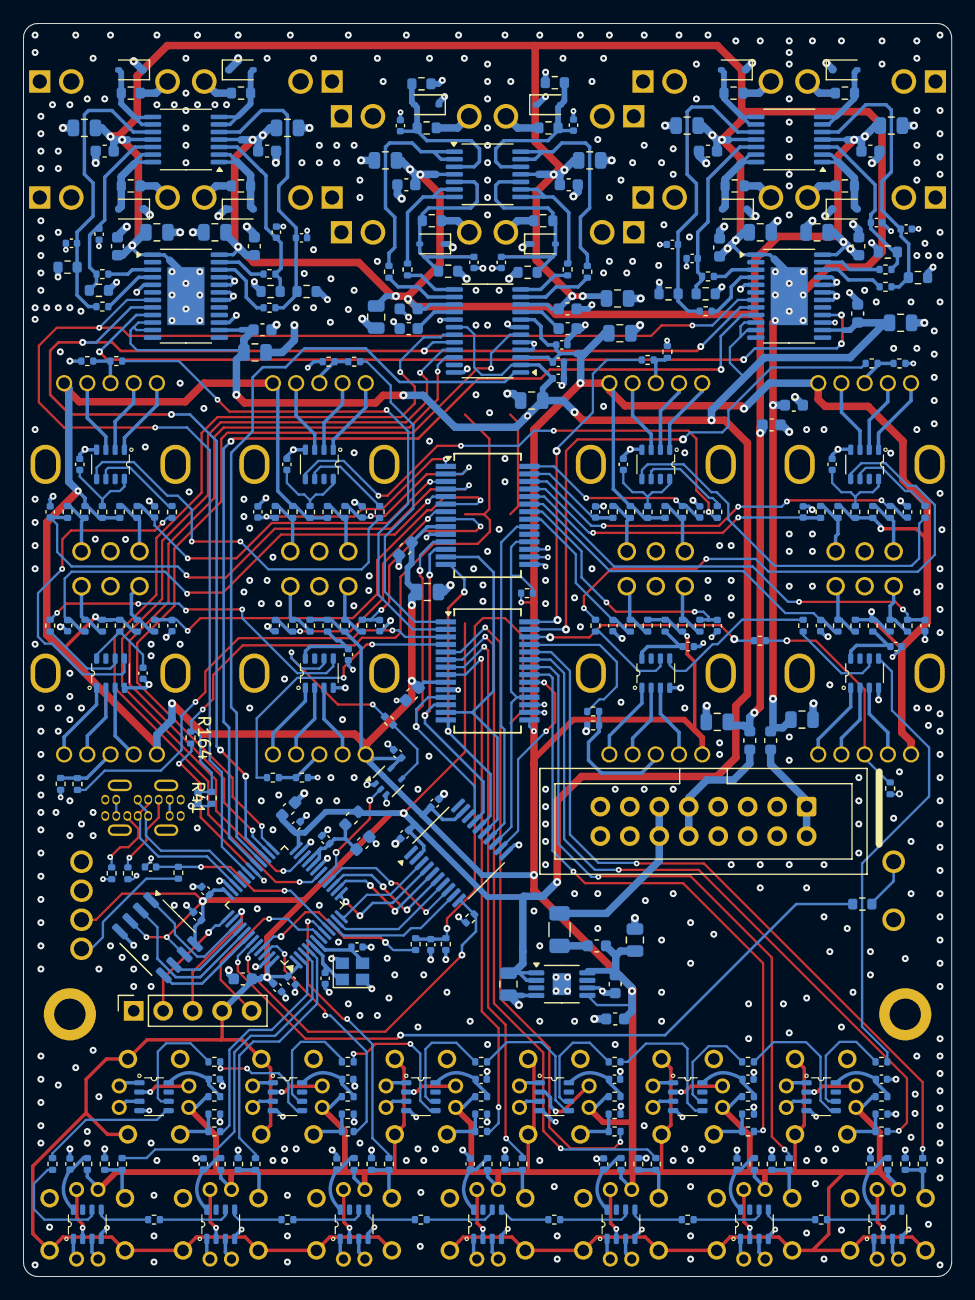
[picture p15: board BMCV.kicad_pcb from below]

Board: 4 copper layers, 80.0 x 108.0 mm, 366 parts (328 on the bottom side), 307 nets.

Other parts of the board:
C11, C99: 100n; C_0402_1005Metric
R4: 1k5; R_0603_1608Metric
VR1: PTL60-15G1-103B2; PTL6015xxxxxxx

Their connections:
unnamed 84: C11.2; also elsewhere on the board
unnamed 85: C99.2; also elsewhere on the board
unnamed: R4.2, VR1.B1 (B_(+))
unnamed 288: VR1.2 (WIPER); also elsewhere on the board
SLIDER_LED: R4.1; also elsewhere on the board

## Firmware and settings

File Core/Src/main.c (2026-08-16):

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
/* Includes ------------------------------------------------------------------*/
#include "main.h"
#include "usb_device.h"

/* USER CODE BEGIN Includes */
#include "bmcv.h"
#include "dac_adc_hal.h"
#include "fram.h"
#include "fw_update.h"
#include "helpers.h"
#include "mcp.h"
#include "usblink.h"
#include "ws2811_hal.h"
#include <stdint.h>

/* USER CODE END Includes */

ADC_HandleTypeDef hadc1;

SPI_HandleTypeDef hspi1;
SPI_HandleTypeDef hspi2;
SPI_HandleTypeDef hspi3;
DMA_HandleTypeDef hdma_spi1_rx;
DMA_HandleTypeDef hdma_spi1_tx;
DMA_HandleTypeDef hdma_spi2_rx;
DMA_HandleTypeDef hdma_spi2_tx;

TIM_HandleTypeDef htim1;
TIM_HandleTypeDef htim2;
TIM_HandleTypeDef htim3;
TIM_HandleTypeDef htim4;
DMA_HandleTypeDef hdma_tim3_ch4;

/* USER CODE BEGIN PV */

// The DAC's clock. Hand-written rather than added through CubeMX, which is what
// every timer in this file except TIM1 and TIM3 already is: the .ioc still
// describes CubeMX's TIM2 - prescaler 14400, period 32, TIM2_IRQn - and that is
// the timer this file calls htim4, while its htim2 (the free-running
// microsecond counter everything is timestamped against) has no .ioc
// counterpart at all. Regenerating from the .ioc would not round-trip, so the
// generated files are maintained here and the USER CODE blocks are what keeps
// that honest.
//
// TIM6 because it is a basic timer: no channels, no pins, nothing to take away
// from anything, and an interrupt vector of its own. It exists on this part and
// nothing else in the build has claimed it.
TIM_HandleTypeDef htim6;

/* USER CODE END PV */

void SystemClock_Config(void);
static void MX_GPIO_Init(void);
static void MX_DMA_Init(void);
static void MX_ADC1_Init(void);
static void MX_SPI1_Init(void);
static void MX_SPI2_Init(void);
static void MX_SPI3_Init(void);
static void MX_TIM1_Init(void);
static void MX_TIM3_Init(void);
static void MX_TIM4_Init(void);
static void MX_TIM2_Init(void);
/* USER CODE BEGIN PFP */
static void MX_TIM6_Init(void);
/* USER CODE END PFP */

/* USER CODE BEGIN 0 */

void HAL_GPIO_EXTI_Callback(uint16_t GPIO_Pin) { bmcv_handle_gpio_exti(GPIO_Pin); }

void HAL_SPI_TxRxCpltCallback(SPI_HandleTypeDef* hspi) { bmcv_handle_txrx_complete(hspi); }

void HAL_TIM_PWM_PulseFinishedCallback(TIM_HandleTypeDef* htim) { ws2811_dma_complete_callback(htim); }

void HAL_TIM_ErrorCallback(TIM_HandleTypeDef* htim) { ws2811_dma_error_callback(htim); }

void init_cycle_counter()
{
  CoreDebug->DEMCR |= CoreDebug_DEMCR_TRCENA_Msk;
  DWT->CYCCNT = 0;
  DWT->CTRL |= DWT_CTRL_CYCCNTENA_Msk;
}

/* USER CODE END 0 */

/**
 * @brief  The application entry point.
 * @retval int
 */
int main(void)
{

  /* USER CODE BEGIN 1 */
  // Before HAL_Init, before the clocks, before anything. If the last boot asked
  // to be updated, the ROM bootloader takes over from here - and it only brings
  // USB up if it inherits a chip that has just reset, which is exactly what
  // this point in the boot still is.
  fw_update_check_boot();
  /* USER CODE END 1 */

  /* MCU Configuration--------------------------------------------------------*/

  /* Reset of all peripherals, Initializes the Flash interface and the Systick. */
  HAL_Init();

  /* Configure the system clock */
  SystemClock_Config();

  /* Initialize all configured peripherals */
  MX_GPIO_Init();
  MX_DMA_Init();
  MX_ADC1_Init();
  MX_SPI1_Init();
  MX_SPI2_Init();
  MX_SPI3_Init();
  MX_TIM1_Init();
  MX_TIM3_Init();
  MX_TIM4_Init();
  MX_USB_Device_Init();
  MX_TIM2_Init();

  /* USER CODE BEGIN 2 */
  init_cycle_counter();

  HAL_GPIO_WritePin(LEVEL_SHIFTER_EN_GPIO_Port, LEVEL_SHIFTER_EN_Pin, GPIO_PIN_SET);
  HAL_Delay(20);

  ws2811_init(&htim3, TIM_CHANNEL_4);

  fram_init(&hspi3, SPI3_FRAM_CS_GPIO_Port, SPI3_FRAM_CS_Pin);

  mcp_init(&hspi1);

  dacadc_init(&hspi2);

  bmcv_init(INT_MCP_ENC_Pin, ADC1);

  // After bmcv_init, which is where the rate it asks for is decided. Started
  // below rather than here, so nothing fires before the first transfer is
  // primed.
  MX_TIM6_Init();

  /* USER CODE END 2 */

  /* Infinite loop */
  /* USER CODE BEGIN WHILE */
  HAL_ADC_Start_IT(&hadc1);
  HAL_TIM_Base_Start(&htim2);
  HAL_TIM_Base_Start_IT(&htim4);

  HAL_Delay(10);

  // Primes the chain: the first transfer is armed here, and every one after it
  // is armed by TIM6 when the completion for the last has landed.
  dacadc_dma_next();

  HAL_TIM_Base_Start_IT(&htim6);

  while (1)
  {
    bmcv_main(__HAL_TIM_GET_COUNTER(&htim2));

    // Handled out here rather than in the USB interrupt that received it:
    // entering DFU tears down the USB stack, which is not something to do from
    // inside its own ISR - and it never comes back.
    if (usblink_dfu_requested())
    {
      fw_update_enter_dfu();
    }
    /* USER CODE END WHILE */

    /* USER CODE BEGIN 3 */
  }
  /* USER CODE END 3 */
}

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
/* USER CODE BEGIN 4 */

void HAL_ADC_ConvCpltCallback(ADC_HandleTypeDef* hadc) { bmcv_handle_adc_conversion_complete(hadc); }

void HAL_TIM_PeriodElapsedCallback(TIM_HandleTypeDef* htim)
{
  if (htim->Instance == TIM4)
  {
    bmcv_poll_tasks();
  }
  else if (htim->Instance == TIM6)
  {
    bmcv_dac_tick(__HAL_TIM_GET_COUNTER(&htim2));
  }
}

// The DAC's clock, at whatever rate bmcv_dac_service_hz() asks for - 64kHz at
// the current substep count, which is 15.625us.
//
// Prescaler 0 and the whole divide in the reload, so the period is exact. At
// 144MHz and a 250us engine tick the reload comes out at 2250 counts, dividing
// the tick into sixteen with nothing left over; a prescaler of 143 would give a
// 1us tick and quantise a 15.625us period to 15 or 16, which is 2-6% of jitter
// on the cadence this whole change exists to make even.
//
// APB1's timer clock is undivided here, so TIM6 counts at SystemCoreClock. The
// division is done against that rather than a literal 144 for the same reason
// bmcv_init's us_per_cycle is.
static void MX_TIM6_Init(void)
{
  __HAL_RCC_TIM6_CLK_ENABLE();

  htim6.Instance           = TIM6;
  htim6.Init.Prescaler     = 0;
  htim6.Init.CounterMode   = TIM_COUNTERMODE_UP;
  htim6.Init.Period        = (SystemCoreClock / bmcv_dac_service_hz()) - 1;
  htim6.Init.AutoReloadPreload = TIM_AUTORELOAD_PRELOAD_DISABLE;
  if (HAL_TIM_Base_Init(&htim6) != HAL_OK)
  {
    Error_Handler();
  }

  // Priority 0, which is the SPI DMA completion's. Same priority means neither
  // can preempt the other, so the service can never be re-entered against the
  // completion that feeds it and the two need no lock between them. TIM4's LED
  // and MCP poll sits at 1 and is preempted by both, which is what it is for.
  HAL_NVIC_SetPriority(TIM6_DAC_IRQn, 0, 0);
  HAL_NVIC_EnableIRQ(TIM6_DAC_IRQn);
}

/* USER CODE END 4 */
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


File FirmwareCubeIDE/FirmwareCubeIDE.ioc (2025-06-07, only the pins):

Mcu.UserName=STM32G474CETx
PA0.GPIO_Label=IN_BTN_MCU3
PA0.Signal=GPIO_Input
PA1.GPIO_Label=ADC1_IN2_SLIDER
PA1.Signal=ADC1_IN2
PA10.GPIO_Label=OUT_DAC_SYNC
PA10.Signal=GPIO_Output
PA11.Signal=USB_DM
PA12.Signal=USB_DP
PA13.Signal=SYS_JTMS-SWDIO
PA14.Signal=SYS_JTCK-SWCLK
PA15.GPIO_Label=SPI3_FRAM_CS
PA15.Signal=GPIO_Output
PA2.GPIO_Label=INT_MCP_BTN
PA2.Signal=GPXTI2
PA3.GPIO_Label=INT_MCP_ENC
PA3.Signal=GPXTI3
PA4.GPIO_Label=OUT_MCP_CS
PA4.Signal=GPIO_Output
PA5.GPIO_Label=SPI1_MCP_SCK
PA5.Signal=SPI1_SCK
PA6.GPIO_Label=SPI1_MCP_MISO
PA6.Signal=SPI1_MISO
PA7.GPIO_Label=SPI1_MCP_MOSI
PA7.Signal=SPI1_MOSI
PA8.GPIO_Label=MENU_BTN_2
PA8.Signal=GPIO_Input
PA9.GPIO_Label=EXTRA_PA9
PA9.Signal=GPIO_Output
PB0.GPIO_Label=OUT_MCP_RESET
PB0.Signal=GPIO_Output
PB1.GPIO_Label=WS_TIM3_CH4
PB1.Signal=S_TIM3_CH4
PB10.GPIO_Label=OUT_ADC_CNVST
PB10.Signal=GPIO_Output
PB11.GPIO_Label=OUT_ADC_ADDR
PB11.Signal=GPIO_Output
PB12.GPIO_Label=INT_ADC_BUSY
PB12.Signal=GPXTI12
PB13.GPIO_Label=SPI2_DAC_ADC_SCK
PB13.Signal=SPI2_SCK
PB14.GPIO_Label=SPI2_DAC_ADC_MISO
PB14.Signal=SPI2_MISO
PB15.GPIO_Label=SPI2_DAC_ADC_MOSI
PB15.Signal=SPI2_MOSI
PB2.GPIO_Label=OUT_ADC_CS
PB2.Signal=GPIO_Output
PB3.GPIO_Label=SPI3_FRAM_SCK
PB3.Signal=SPI3_SCK
PB4.GPIO_Label=SPI3_FRAM_MISO
PB4.Signal=SPI3_MISO
PB5.GPIO_Label=SPI3_FRAM_MOSI
PB5.Signal=SPI3_MOSI
PB6.GPIO_Label=MENU_BTN_3
PB6.Signal=GPIO_Input
PB7.GPIO_Label=LEVEL_SHIFTER_EN
PB7.Signal=GPIO_Output
PB8-BOOT0.GPIO_Label=MENU_BTN_BOOT
PB8-BOOT0.Signal=GPIO_Input
PB9.GPIO_Label=IN_BTN_MCU1
PB9.Signal=GPIO_Input
PC13.GPIO_Label=IN_BTN_MCU2
PC13.Signal=GPIO_Input
PC14-OSC32_IN.GPIO_Label=IN_BTN_MCU5
PC14-OSC32_IN.Signal=GPIO_Input
PC15-OSC32_OUT.GPIO_Label=IN_BTN_MCU4
PC15-OSC32_OUT.Signal=GPIO_Input
PF0-OSC_IN.Signal=RCC_OSC_IN
PF1-OSC_OUT.Signal=RCC_OSC_OUT

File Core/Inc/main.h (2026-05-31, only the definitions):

#define IN_BTN_MCU2_Pin GPIO_PIN_13
#define IN_BTN_MCU2_GPIO_Port GPIOC
#define IN_BTN_MCU5_Pin GPIO_PIN_14
#define IN_BTN_MCU5_GPIO_Port GPIOC
#define IN_BTN_MCU4_Pin GPIO_PIN_15
#define IN_BTN_MCU4_GPIO_Port GPIOC
#define IN_BTN_MCU3_Pin GPIO_PIN_0
#define IN_BTN_MCU3_GPIO_Port GPIOA
#define ADC1_IN2_SLIDER_Pin GPIO_PIN_1
#define ADC1_IN2_SLIDER_GPIO_Port GPIOA
#define INT_MCP_BTN_Pin GPIO_PIN_2
#define INT_MCP_BTN_GPIO_Port GPIOA
#define INT_MCP_BTN_EXTI_IRQn EXTI2_IRQn
#define INT_MCP_ENC_Pin GPIO_PIN_3
#define INT_MCP_ENC_GPIO_Port GPIOA
#define INT_MCP_ENC_EXTI_IRQn EXTI3_IRQn
#define OUT_MCP_CS_Pin GPIO_PIN_4
#define OUT_MCP_CS_GPIO_Port GPIOA
#define SPI1_MCP_SCK_Pin GPIO_PIN_5
#define SPI1_MCP_SCK_GPIO_Port GPIOA
#define SPI1_MCP_MISO_Pin GPIO_PIN_6
#define SPI1_MCP_MISO_GPIO_Port GPIOA
#define SPI1_MCP_MOSI_Pin GPIO_PIN_7
#define SPI1_MCP_MOSI_GPIO_Port GPIOA
#define OUT_MCP_RESET_Pin GPIO_PIN_0
#define OUT_MCP_RESET_GPIO_Port GPIOB
#define WS_TIM3_CH4_Pin GPIO_PIN_1
#define WS_TIM3_CH4_GPIO_Port GPIOB
#define OUT_ADC_CS_Pin GPIO_PIN_2
#define OUT_ADC_CS_GPIO_Port GPIOB
#define OUT_ADC_CNVST_Pin GPIO_PIN_10
#define OUT_ADC_CNVST_GPIO_Port GPIOB
#define OUT_ADC_ADDR_Pin GPIO_PIN_11
#define OUT_ADC_ADDR_GPIO_Port GPIOB
#define INT_ADC_BUSY_Pin GPIO_PIN_12
#define INT_ADC_BUSY_GPIO_Port GPIOB
#define INT_ADC_BUSY_EXTI_IRQn EXTI15_10_IRQn
#define SPI2_DAC_ADC_SCK_Pin GPIO_PIN_13
#define SPI2_DAC_ADC_SCK_GPIO_Port GPIOB
#define SPI2_DAC_ADC_MISO_Pin GPIO_PIN_14
#define SPI2_DAC_ADC_MISO_GPIO_Port GPIOB
#define SPI2_DAC_ADC_MOSI_Pin GPIO_PIN_15
#define SPI2_DAC_ADC_MOSI_GPIO_Port GPIOB
#define MENU_BTN_2_Pin GPIO_PIN_8
#define MENU_BTN_2_GPIO_Port GPIOA
#define EXTRA_PA9_Pin GPIO_PIN_9
#define EXTRA_PA9_GPIO_Port GPIOA
#define OUT_DAC_SYNC_Pin GPIO_PIN_10
#define OUT_DAC_SYNC_GPIO_Port GPIOA
#define SPI3_FRAM_CS_Pin GPIO_PIN_15
#define SPI3_FRAM_CS_GPIO_Port GPIOA
#define SPI3_FRAM_SCK_Pin GPIO_PIN_3
#define SPI3_FRAM_SCK_GPIO_Port GPIOB
#define SPI3_FRAM_MISO_Pin GPIO_PIN_4
#define SPI3_FRAM_MISO_GPIO_Port GPIOB
#define SPI3_FRAM_MOSI_Pin GPIO_PIN_5
#define SPI3_FRAM_MOSI_GPIO_Port GPIOB
#define MENU_BTN_3_Pin GPIO_PIN_6
#define MENU_BTN_3_GPIO_Port GPIOB
#define LEVEL_SHIFTER_EN_Pin GPIO_PIN_7
#define LEVEL_SHIFTER_EN_GPIO_Port GPIOB
#define MENU_BTN_BOOT_Pin GPIO_PIN_8
#define MENU_BTN_BOOT_GPIO_Port GPIOB
#define IN_BTN_MCU1_Pin GPIO_PIN_9
#define IN_BTN_MCU1_GPIO_Port GPIOB
#define MIDI_IN_PORTS_NUM 0x01  // Specify input ports number of your device
#define MIDI_OUT_PORTS_NUM 0x01 // Specify output ports number of your device

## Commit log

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2026-08-01 Stage 1: derive button gestures in one place
    Every UX call site re-derived press/hold semantics from HwState's raw
    button_pressed_t/button_released_t with its own threshold: MS(10), MS(200),
    MS(500), MS(1000), CTRL_SHIFT_ACTIVATION, and a raw `> 10` in scene.c that
    was microseconds where milliseconds were meant. Render code re-derived
    independently of input code, so the two could disagree - SAV drew its LED
    from pressed_t but acted on released_t.
    ui_input.c folds raw hardware state into edge events (DOWN/UP/TAP/HOLD/
    LONG/VLONG) once per engine tick, with the durations defined in exactly one
    place. Handlers and renderers now read the same events, so they cannot drift.
    Events accumulate unt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
    [test_ui_gestures.c, test_ui_input.c]
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2026-08-01 Stage 4: layered renderer and one confirmation mechanism
    The four write_*_led functions were switch(shift_state) blocks that each
    re-picked colours, re-derived what to highlight, and in some arms wrote
    nothing at all - scene.c's QNT arm only touched its LED while a trig source
    was pending, so otherwise the framebuffer kept the previous frame.
    ui_render.c replaces them with one stack per element: base, then context,
    then the transient value, then confirmation. Layer 0 always writes, so stale
    pixels are structurally impossible. Layers 1 and 3 are mode-independent -
    they read ui_sel_is_candidate and ui_feedback_active - so a new mode gets
    consistent highlighting and confirmation without any re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
    [test_led_render.c]
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2026-08-02 Review pass: enforce the layering, split the frontend
    Four test files never failed the build. test_instance, test_panel_spec,
    test_sim_rt and test_input_state called TESTKIT_SUMMARY() without return, so
    main fell off its end and exited 0 - ctest reported green however many checks
    failed. They are the four newest suites, so everything they covered was
    unverified. testkit_summary is [[nodiscard]] now, which makes the omission a
    compiler warning rather than a silent pass.
    Mute was a mutating getter with a prose contract: channel_output_level()
    advanced the ramp as a side effect and the header told hosts they had to call
    it. A host reading channels_output_level[] directly got ungated audio and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
    [clock_sync.csv, demo_amp.csv, mute_channel.csv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]
2026-08-02 LED language, MOD freed, output clamp, PWM
    Two vocabularies were fighting over the same 21 LEDs, and one parameter was
    doing two unrelated jobs.
    LEDs: white is now the whole vocabulary of assignment - a pickable element keeps
    its own colour and marks itself with a 200ms white flash every 1.6s; with a
    source held, valid destinations are steady white and everything else goes dark.
    A shift mode's channel LEDs show that mode's own setting and never the output
    level, via a ChannelBaseLayer in the mode table. Setting-state hues are shared
    across pages (index 0 is always purple). CPY/CLR wear one tint each. Confirm
    colours: green wrote, purple cleared, cyan loaded; red is errors only. Fixes
    every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
    [demo_amp.csv, mute_channel.csv]
2026-08-02 MOD per shape mode, held-press feedback, a debuggable module
    MOD warped the phase in the wavetable mode and did nothing in the other two. It
    now has a job in each, chosen for what that shape wants: skew for the wavetable
    (one rational warp, replacing two straight segments that met at a corner),
    density for stepped random, and an AD envelope for PWM whose ramps stay inside
    their own segment. The stepped-random normalisation table gained a probability
    axis so its correction holds as density moves - ~86KB of flash, and `just
    sr-table` regenerates it now that it is not a hand-run tool.
    Shape modes are three rather than five: the SMOOTH/SEMI/HARD trio was one
    algorithm at three hold values. wave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
    [bmcv_sim.c, test_channel.c, test_led_render.c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]
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2026-08-03 A VCV Rack module, running the firmware
    vcv/ is a Rack 2 plugin whose whole signal path is this repo's core. The
    core sources are compiled straight out of Core/Src/Lib from the same list
    the ARM build, tests/ and sim/ use, so there is no copy to drift: the
    module allocates one BmcvInstance, samples Rack's ports into an
    InputSample every audio frame, ticks the engine on a divider at 4kHz and
    reads channels_gated_level[] and leds[] back out. There is no DSP in the
    plugin and there must never be any.
    The panel is the real exported artwork with Rack's own parts on it -
    PJ301M jacks, VCVLightBezel for the backlit switches, TL1105 for the three
    tactiles, Rack's screws in the artwork's own slots.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
    [mute_channel.csv, shift_modes.csv]
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2026-08-04 The clock cannot poison the module, and CI runs
    Two pulses inside the 2ms post-reset guard divided by zero: the interval is
    only measured outside that window, but the divide was not gated on having
    measured one. freq_est is a leaky integrator, so the inf never washed out -
    every later estimate inf, every channel's phase NaN, and wavetable_lookup
    indexed with whatever a NaN casts to. A power cycle was the only recovery.
    The interval is now only taken against a pulse that happened, Clock_Reset
    drops the pulse history, a pulse closer than 1ms is bounce, a tempo outside
    1..1000 BPM is not a measurement, wavetable_lookup masks i0 as it already
    masked i1, and a non-finite phase resets instead of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
    [bmcv_sim.c, test_channel.c, test_config_migrate.c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]
2026-08-04 The sync loop, measured and then fixed
    Turned the phase-lock loop into numbers before touching it - settling, ringing,
    frequency pull and slew, long-run alignment, phase continuity - and the numbers
    found what listening had not. tests/pll_metrics.{c,h} does the measuring,
    tests/test_pll.c holds thirteen scenarios and prints the table, docs/pll.md
    keeps the baseline to diff against.
    Three defects, in the order they were found:
    - A crossfade between scenes at different rates flipped the alignment period 44
    times in a one-second fader move. gcd comes from find_denominator, whose
    answer jumps as the ratio moves, and the target is measured from an origin
    that repeats every gcd beats - so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
    [clock_lock.csv]
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2026-08-07 The module flashes itself, from a browser tab
    The USB-C port had never been used for the one thing a USB port on a
    Eurorack module is for. Updating meant an ST-Link on the programming
    header.
    The hardware was already built for this and nobody had noticed: FN2 is
    wired to PB8, which is BOOT0. Holding it at power-on hands the module to
    the DFU bootloader in the STM32's mask ROM - so no bootloader of ours, no
    flash spent on one, and nothing that can be bricked.
    web/update/ is a page that speaks DfuSe over WebUSB. The firmware gained
    a SysEx control channel on the MIDI endpoint it already enumerated, so
    the button is optional: the page asks it to reboot, and it comes back as
    a bootloader with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
    [main.c]
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2026-08-07 feat(midi): drive the clock and reset from MIDI when no input is configured
    A jack always wins: MIDI Clock only advances the beat, and MIDI Start
    only resets it, when no input is configured as that source - not when
    the configured input happens to be idle. The two gate independently.
    midi_realtime.c is the hardware-free decode, the counterpart to
    sysex.c for the four System Real-Time bytes the clock cares about:
    Clock (0xF8) and Start (0xFA) are latched, Continue is deliberately
    not treated as Start (it resumes rather than restarts), and Stop needs
    no handling at all - a source that stops pulsing already reads as gone
    once Clock_Poll's own timeout passes, the same as an unplugged CV
    clock.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
    [test_input_fold.c]
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2026-08-07 refactor!: reorganize repo with firmware at the root
    Flips the layout: firmware, the simulator, the web frontend and the VCV
    Rack module move up from BMCVFirmware/ to the repo root, and the PCB
    project, its production/fabrication outputs, and documentation become
    clearly named subfolders (pcb/, production/, docs/). The legacy
    pre-firmware wavetable export scripts move to legacy/wavetable-export/.
    This also gets the tree closer to VCV Rack Library layout conventions
    without yet splitting vcv/ into its own repository, which the Library
    ultimately requires and which vcv/Makefile already anticipates via its
    BMCV_ROOT indirection.
    Updates CI (ci.yml, pages.yml) to drop the BMCVFirmware/ working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
    [BMCV.kicad_sch, BMCVFirmware.cfg, buttons.kicad_sch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]
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2026-08-10 test(ui): cover the scene and channel button dispatch
    ui_scene.c and ui_channel.c were the two host-testable core sources no test
    referenced at all, and between them they are every button and encoder on the
    front panel: each arm of their switches is a different user-visible
    behaviour reached through the same hardware.
    Both files were verified to bite by mutation - wrapping step_setting instead
    of clamping, dropping its delta clamp, and removing the N_INPUTS bound each
    fail the test that names them.
    The bounds test compares the whole EngineConfig rather than input_mode[]
    alone: without the guard the write lands one past that array and inside the
    next member, so a narrower comparison passes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
    [test_ui_channel.c]
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2026-08-10 fix(leds): recover from a failed LED DMA instead of freezing the panel
    ws2811_update() clears WS_DATA_COMPLETE_FLAG to mark a frame in flight and
    then starts the DMA. Only the completion callback sets it back, and that
    callback runs only if the transfer actually started - so a HAL_TIM_PWM_Start_DMA
    that returned anything but HAL_OK left the flag clear for good, and the guard
    at the top of the function refuses to draw while it reads that way.
    One failed start therefore parked the panel on its last frame until the case
    was power-cycled. It also took the amber DFU indication with it: fw_update.c
    waits on this same flag before handing over to the bootloader, so the only
    feedback that route has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
    [main.c]
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2026-08-11 feat(ui): save the selected parameter with the patch, defaulting to OFS
    The parameter the encoders edit in no-shift mode lived in UiState, which is
    the half that is deliberately not saved - so every power cycle landed on a
    fixed page (CH_PARAM_SHP, set in bmcv_instance_init) regardless of where the
    user left it.
    It moves into EngineConfig, which is what goes to FRAM. That makes it one
    value rather than a live copy and a stored one, and it puts it alongside
    scene_a, scene_b and current_preset, which are panel state saved with the
    patch for the same reason. A preset therefore recalls the page it was stored
    with, which is the same rule the rest of the record already follows.
    Record format 4 -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
    [clock_sync.csv, shift_modes.csv]
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2026-08-11 feat(midi): publish the channel outputs, inputs and clock as MIDI
    The module already enumerated as a USB MIDI device and read Clock, Start
    and SysEx off it. Now it talks back: the eight channel outputs and four CV
    inputs as control changes on MIDI channel 1, CC 16-27, and its own clock
    at 24 PPQN. See docs/midi.md.
    midi_out.c is core code with no USB in it - it turns EngineState and
    HwState into a queue of plain MIDI messages, and each host only carries
    the bytes. So the mapping exists once and the simulator cannot drift from
    the hardware. The web frontend drains the same queue into a Web MIDI port
    and shows the twelve CCs as they go out, which works with no MIDI port on
    the machine at all.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
    [bmcv_sim.c]
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2026-08-11 feat(ui): rework the FRQ ring - prime-limit colour, off-grid wash, rate pulse
    The frequency ring coded a ratio as a hue from a hand-maintained table with
    no rule behind it: powers of two were green except 1/64, 32 and 128; odd
    integer divisions were red; ratios with a numerator and a denominator were
    cyan whether the odd factor was 3 or 5. It also spent red, which
    color_presets.h and the README both reserve for errors alone.
    The grid was already a reciprocal-symmetric 5-limit lattice - every entry
    2^k, 3*2^k or 5*2^k - so the colour now reads that structure off instead of
    restating it by hand. Hue is the ratio's prime limit: green straight, yellow
    triplet, orange quintuplet. Octaves are fre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
    [clock_lock.csv]
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2026-08-13 feat(leds): rebuild the colour pipeline around light rather than duty
    Every value the renderer handed the panel was a duty cycle, and duty is
    not light: the three dies differ by nearly four to one, so a VAL_LOW
    purple put out a third of what a VAL_LOW yellow did and a bipolar ring
    read brighter positive than negative. Everything here follows from
    fixing that, and from giving the framebuffer somewhere to put the
    fractions it needs once it does.
    The framebuffer is 8.8 fixed point and the flush dithers it with a
    first-order sigma-delta, so a colour can ask for a fraction of a duty
    step and get it. The dither lives in the flush rather than the
    framebuffer, which is what keeps the simulator show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
    [bmcv_sim.c, bmcv_sim_cli.c, led_color.h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]
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2026-08-14 feat(core): let a host reset a module and forget its storage
    The two things the remote input mailbox cannot express, because neither is a
    level and neither is a panel gesture: start again, and forget what was saved.
    Both destructive, so both are edges - acted on once per change of a sequence
    number, however often the mailbox is rewritten. Both transports rewrite theirs
    continuously, and a command performed twice is the whole risk here.
    Separate from RemoteInput rather than riding along with it. The two have
    opposite shapes: input is a level re-sent every frame and read every tick, a
    command is a one-off sent when somebody clicks. Keeping them apart means the
    input mailbox stays a pure level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
    [bmcv_sim.c, test_instance.c]
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2026-08-15 feat: carry the module over WebUSB, and delete the SysEx layer
    Snapshots, both mailboxes and the reboot into DFU all move to the vendor
    interface's bulk endpoints. Nothing is encoded and nothing is framed: a bulk
    transfer keeps its boundaries, so one transfer is one message and a snapshot is
    simply the instance's bytes. The browser assembles the 2384 of them and hands
    over the whole thing, so there is no reassembly on either side.
    That deletes rather more than it adds. Gone: the seven-bit codec, the stream
    builder that spread a snapshot across fifty-seven transfers, every SYSEX_CMD,
    the parser that had to report several messages per transfer because a host packs
    what it has, and the rule th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
    [bmcv_sim.c, main.c]
2026-08-15 fix(input): a rebuilt instance is a position, not a gesture
    Clearing FRAM on hardware returned every setting to its default except the
    offset. The cause is older than the transport that exposed it.
    Encoder positions are free-running counters the instance does not own. A module
    that has been played has them a long way from zero, and rebuilding the instance
    - which is what a remote reset does - zeroes the frame they are compared
    against. The difference between the panel and a fresh frame is not a turn, but
    the first fold read it as one, and applied it to whichever parameter was
    selected. config_defaults deliberately selects OFS, so the whole accumulated
    position of encoder 0 landed on the off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
    [test_input_fold.c]
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2026-08-15 feat(web): say what an input is for in the colour the module says it in
    The transient messages go. What a reset or a wipe did is visible immediately in
    everything the page is already showing - the panel, the scopes, the channel
    table - so a line of text announcing it restated what the page had already said,
    and had to be placed and timed out to do so. It had also drifted to sitting
    beside the FRAM button, where it read as a label for it.
    The input labels take the colour the module lights that jack's own LED with.
    ui_render.c maps each InputMode through input_mode_color[], which reaches
    purple for default, yellow for clock, red for reset and cyan for a level - so
    those are the four here. App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
    [bmcv_sim.c]
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2026-08-15 feat(sim): one scope window for every source, and a ring that forgets
    The same cell at the same width showed 375ms of simulation against two seconds
    of hardware, so a trace that looked slow in one read as fast in the other.
    Switching source is meant to change where the picture comes from and nothing
    else about it.
    Two seconds everywhere, which is the longer of the two it replaces. Setting the
    simulation to that alone would not have worked: spanSamples clamps to the ring,
    and at one sample per engine tick two seconds wants 8000 of 4096 frames - so it
    would have drawn 1.02s and still disagreed. BMCV_SIM_SCOPE_DIV decimates the
    simulation's capture to every second tick, which fits and loses no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
    [bmcv_sim.c]
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2026-08-15 fix(ui): a press and a turn in the same tick is a fine adjust, not a reset
    The reset guard asks whether a press spanned an encoder edit, by comparing how
    long the button has been down against how long ago the last edit was. That only
    works if both are measured from the same instant, and held_us stopped
    accumulating one tick early - so an edit made on the very tick the button went
    down looked older than the press containing it, and the release wiped the value
    that press had just adjusted.
    Nobody presses and turns within one tick by hand, which is why this survived on
    hardware. The web panel's shift-wheel does exactly that: it asserts the push and
    feeds the detent in the same gesture, so fine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
    [test_ui_channel.c]
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2026-08-15 docs: give the project a CLAUDE.md, and one per directory that has its own rules
    Six files: the root one is commands, layout, the seam rule and an avoid-list,
    and five sub-files carry what only matters once you are in that directory - the
    core's struct and enum rules, how to add a test and at which level, what each
    generator owns, the frontend's no-build/no-deps constraints, and the golden-flow
    workflow. docs/ stays the long-form reference and the root file is its index:
    pll.md alone is 231 lines of measurement baseline, which belongs in a doc rather
    than in every context window.
    Auditing the docs against the tree turned up four things that were wrong rather
    than merely verbose:
    - Two dead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
    [test_input_fold.c]
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2026-08-16 feat(sr): a second stepped mode, driven for modulation
    SHP is the distribution and MOD is the motion. The value path is untouched: a
    style is where the knobs go plus a reshaping of the finished value, which is all
    the difference between a bassline and something to modulate with turned out to
    need.
    sr_bias_map() is the new axis and the one thing the pattern engine could not do
    - sr_shape_blend() is odd, so it compresses or expands the middle symmetrically
    and a distribution that leans was out of reach however the levers were set. Two
    stages either way, no powf: leaning low with the peaks still reaching at one
    end, bunched against both rails at the other.
    Applied after the correction, delibe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
    [bmcv_sim.c]
2026-08-16 feat(drift): a third random mode, with no pattern in it
    Four octaves of a smoothed triangle summed in the phase domain. Every rate is a
    whole number of cycles, so the waveform closes on itself by construction; every
    octave is odd over a whole number of periods, so its mean over a cycle is
    exactly zero at every setting; and the peak-to-peak is known in advance. The
    level work the stepped modes need a table and a per-channel measurement for is
    two constants here, and the call costs 20ns against their 87.
    SHP is detail - two turns of direction per cycle at one end, sixteen at the
    other - and MOD is the same reshaping the control mode puts on SHP, free here
    because there is no correction for it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
    [bmcv_sim.c]
2026-08-16 revert(drift): a smooth cycle-locked wander is a waveform, not randomness
    It measured well on every number the harness has - DC exactly zero, no
    correction at all, 20ns a call, the gentlest small turn of the three - and it
    sounded like a sine with harmonics, because that is what it is. A waveform that
    closes on itself over one cycle is a Fourier series; smooth means few harmonics;
    octave rates are harmonics 1, 2, 4 and 8 at fixed phases. No tuning reaches
    randomness from there, and non-integer rates would break the loop.
    The plan keeps the reasoning so this is not rebuilt, and names what the module
    is actually missing instead: patterns that evolve across cycles rather than
    repeating every o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
    [bmcv_sim.c]
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2026-08-16 fix(dac): serve a due transaction where it lands, not when the loop notices
    The output rate was a property of how busy the engine was. A DMA completion set
    a flag and waited for the main loop, and the loop was inside an engine tick - so
    with eight stepped channels the frame rate fell from 4.5kHz to under 1kHz
    exactly when the most was being asked of it, and dac_fps collapsed onto
    engine_fps.
    Measured on the module: the service was turning around every 55us against a
    15.6us target. Six bytes at an 18MHz SPI clock is 2.67us of bus time, so the
    wire was busy 5% of that and the rest was latency. The completion interrupt now
    serves the next transaction itself when one is due, which is one interp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
    [main.c]
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2026-08-16 fix(dac): give the outputs a clock instead of the loop's leftovers
    Serviced from the main loop, the output rate was a property of how busy the
    engine was. A completion arriving during a tick waited out the rest of it, and
    a tick costs 307us of a 250us period with eight stepped channels - so read off
    the module, dac_fps and engine_fps were the same number, 2942: exactly one
    transaction per tick, 735 frames/s against the 16k the substep count asks for.
    The interpolation was not oversampling anything, it was smoothing over an
    output that could not keep up.
    TIM6 owns it now. A basic timer - no channels, no pins, its own vector - at
    bmcv_dac_service_hz(), with prescaler 0 and the whole divide in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
    [main.c]
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2026-08-16 fix(pll): stop the beat phase wrapping past a beat the counter has not reached
    Clock_Poll interpolates beat_phase between pulses, and wrapped it with a
    `while (next_phase >= 1.0f) next_phase -= 1.0f`. Only a pulse advances
    beat_counter. So for the ticks between a beat falling due and its pulse
    arriving - a pulse is late by up to a tick, every beat - the phase said "a new
    beat has started" while the counter still said the old one.
    channel.c reads the two together: the alignment target is
    (beats_in % gcd) + beat_phase, scaled by the ratio. A phase that has wrapped
    without the counter is a target a whole beat out of step, and it is applied to
    every locked channel at once.
    Measured at a 312us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
    [test_pll.c]
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

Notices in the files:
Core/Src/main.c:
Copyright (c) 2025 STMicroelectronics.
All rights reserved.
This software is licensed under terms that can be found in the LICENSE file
